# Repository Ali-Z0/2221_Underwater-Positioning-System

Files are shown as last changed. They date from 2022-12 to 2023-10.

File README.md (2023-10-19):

# 2221_UnderwaterLocalization
> Project for the localization of an underwater module.
> Demonstration [here](https://www.example.com). <!-- If you have the project hosted somewhere, include the link here. -->

## Table of Contents
* [General Information](#general-information)
* [Technologies Used](#technologies-used)
* [Features](#features)
* [Configuration](#configuration)
* [Usage](#usage)
* [Project Status](#project-status)
* [Improvements](#improvements)
* [Contact](#contact)
<!-- * [License](#license) -->

## General Information
This project revolves around an onboard electronic card designed to store measurement data about the movement of an underwater module through an inertial unit and a pressure sensor. This aims to mathematically locate it from its starting point (reference). This is crucial because underwater localization isn't an easy task, especially given the various underwater communication constraints, notably that electromagnetic waves do not propagate easily there.
<!-- You don't have to answer all the questions - just the ones relevant to your project. -->

## Technologies Used
- MPLAB Harmony v2_06
- Microcontroller - PIC32MX130F256D
- Inertial Unit - Bosch BNO055

## Features
- Saving a data set every 100ms.
- Maximum usage depth of 60m.
- 2 hours of logging onto an SD card.
- Sensing on 9 axes:
  - 3-axis accelerometer.
  - 3-axis gyroscope.
  - 3-axis magnetometer.
  - Temperature sensor
  - Depth gauge [0->10bar] [Res 1/10]
  - 3 to 5 free MikroE slots for additional measurements.
- Capability to save location of points of interest via:
  Saving button [To be defined: Magnetic, Optical, Mechanical or other].
- Battery with a minimum autonomy of 2 hours.
- Battery charging via USB connector.
- Data reading through USB connector (Electronic interfacing, software
  optional in this version).
- LED Interface.

<p align="center" width="100%">
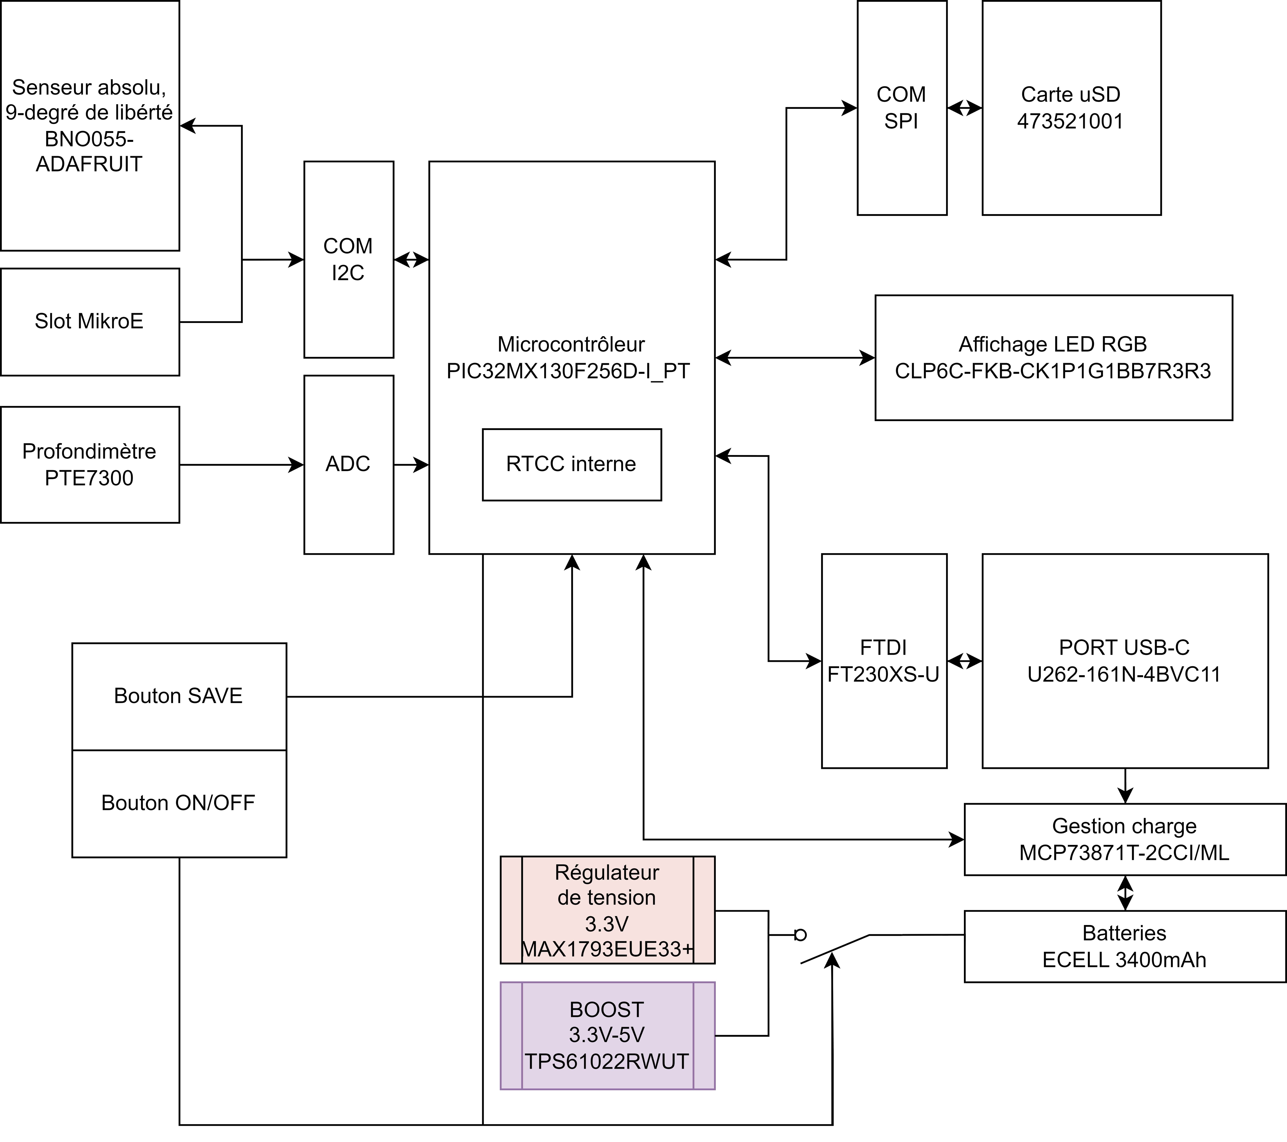
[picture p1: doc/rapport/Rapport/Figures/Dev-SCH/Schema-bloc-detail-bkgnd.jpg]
    
</p>

## Configuration
The electronic card must be assembled considering the manufacturing files and the BOM (Bill of Materials). The firmware then needs to be implemented into the PIC microcontroller, and an SD card should be inserted to read the movement data.

## Usage
The firmware code needs to be flashed using MPLAB-X with harmony onto the microcontroller of the produced PCB. To do this, there's a BERG programming connector. Once the code is flashed, the underwater module can be used, and provided an SD card is inserted, movement data will be saved in CSV format.

## Project Status
The project is completed, but improvements can always be made.

## Improvements
To do:
- [DONE] SCK VALID ONLY AT PIN 14 instead of 20
- [DONE] CHANGE U2TX PIN (PIN14) TO ANOTHER PIN
- [DONE] EXTERNAL OSCILLATOR MUST BE CONNECTED AS SECONDARY OSCILLATOR AND NOT PRIMARY
- Review multiplexer system (choice of CS polarity).

## Contact
Created by Ali Zoubir: ali.zoubir@etml-es.ch

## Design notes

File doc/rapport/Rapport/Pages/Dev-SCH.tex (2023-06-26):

% ------------------------- MAIN TASK ---------------------------------
\section{Développement schématique}

\subsection{Scéma bloc détaillé}
{
	\begin{figure}[h]
		\centering
		
		\caption{Schéma bloc détaillé}
		\label{fig:schema-bloc-detail}
		\source{Auteur}
	\end{figure}
}

\clearpage
\subsection{Choix des composants} \label{ssec:num32}
{
	\subsubsection{Microcontrôleur}
	Lors de la recherche de composants, j'ai décidé d'utiliser l'un des PIC32 standards de l'ES :
	\textbf{PIC32MX130F064D-I/PT}.
		
	\begin{figure}[h]
		\centering
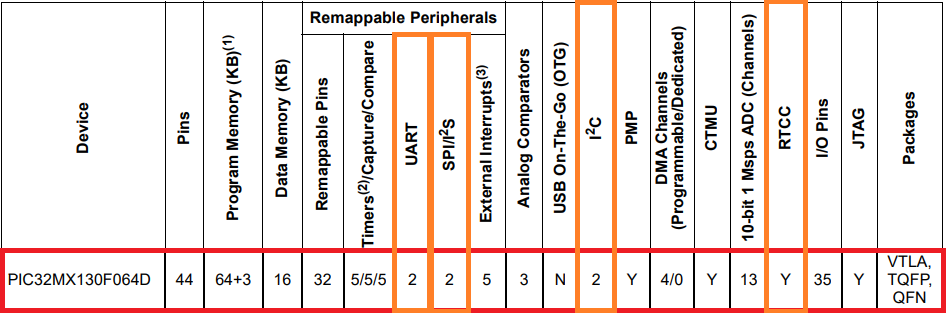
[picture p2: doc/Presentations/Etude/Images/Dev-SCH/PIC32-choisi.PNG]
		
		\caption{Périphériques disponibles du PIC}
		\label{fig:pic32-choisi}
		\source{\href{https://ww1.microchip.com/downloads/aemDocuments/documents/OTH/ProductDocuments/DataSheets/PIC32MM0256GPM064-Family-Data-Sheet-DS60001387D.pdf}{PIC32MM0256GPM064 family datasheet}}
	\end{figure}
	
	Nous pouvons constater sur la figure \ref{fig:pic32-choisi} que les critères minimaux de mon projet sont respectés :
	
	\begin{center}
		\fbox{\textit{1 - I2C}} \fbox{\textit{1 - SPI}} \fbox{\textit{1 - UART}} \fbox{\textit{1 - RTCC}}
	\end{center}
}

\clearpage
\subsection{Dimensionnements} \label{ssec:num31}
{
	\subsubsection{Vue d'ensemble schématique} \label{sssec:SchemaBloc} \vspace{-6mm}
	{
		\begin{figure}[th]
			\centering
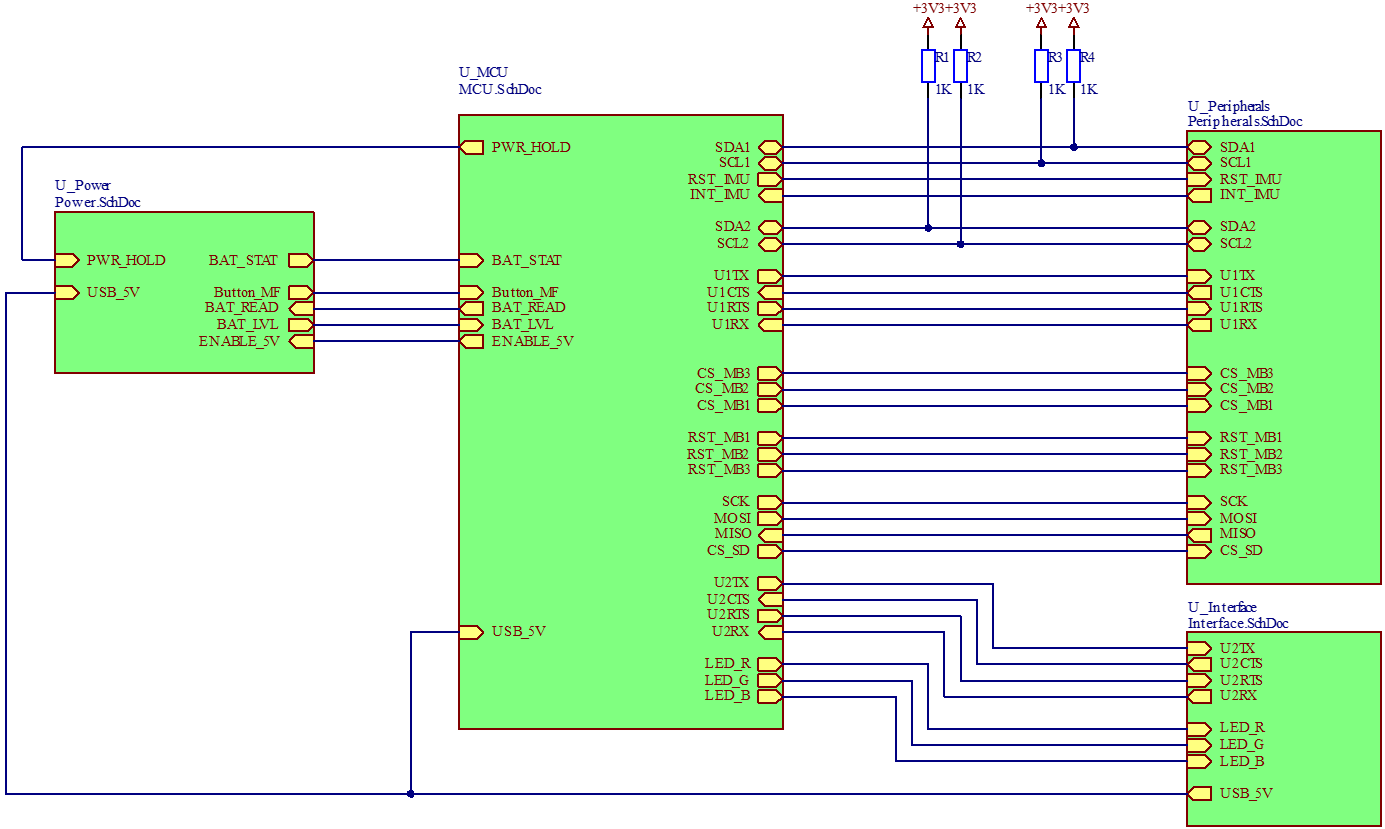
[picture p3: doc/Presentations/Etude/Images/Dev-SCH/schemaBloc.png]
			
			\caption{Schéma bloc de la schématique}
			\source{Auteur}
			\label{fig:schemablocSCH}
		\end{figure} \vspace{-5mm}
		Nous pouvons constater sur la figure \ref{fig:schemablocSCH} la structure des différents blocs du schéma : 
		
		\begin{tabularx}{16cm}{|X|X|}
			\hline
			Bloc & Description \\
			\hline
			\hline
			Power & Contient les différents régulateurs du système, ainsi que la gestion de charge de la batterie. \\
			\hline
			MCU & Contient l'intelligence du système, avec le microcontrôleur ainsi que tous ses composants passifs associés. \\
			\hline
			Peripherals & Périphériques du système : Carte-SD, Centrale inertielle, Capteur de pression, Slots MikroE. \\ 
			\hline
			Interface & Connecteur USB avec convertisseur serial (FTDI) et tous les composants passifs de sécurité. Interface LED RGB pour le statut. \\
			\hline
		\end{tabularx}
	}

	\clearpage
	\subsubsection{Autonomie du système} \label{sssec:SysAutonomie}
	{
		Afin de proportionner la batterie du circuit, il a fallut dimensionner les différentes consommations des composants, ceci par le biais de leurs documentations :
		
		\begin{center}
			\fbox{\textit{MCU - 30mA}} \fbox{\textit{BNO055 - 12.3mA}} \fbox{\textit{Capt. Pression - 4mA}} \fbox{\textit{\textcolor{red}{Carte-SD - 100mA}}} \fbox{\textit{MikroE - ??mA}} \fbox{\textit{Régulateurs - 40uA}} \fbox{\textit{LED RGB - 25mA}} 
		\end{center}
		
		Nous pouvons constater que la plus grande consommation vient de la carte micro-SD, qui au maximum peut induire 100mA. \footnote{\href{https://images-na.ssl-images-amazon.com/images/I/91tTtUMDM3L.pdf}{Datasheet SanDisk} }

		Afin d'obtenir une autonomie d'au moins 2h (selon CDC), il faudrait une capacité de :
		
		\begin{equation}
			Capacite = Consommation_{tot} * Temps
		\end{equation}
		
		Ce qui nous fait une capacité de $\sim$342.68mAh, valeur facilement atteignable par les batteries li-ion du marché. Étant-donné que différents projets utilisaient des batteries 3400mAh, dans un objectif de conformité et de simplification des commandes, j'ai choisis cette même valeur.
		Ce qui signifie une autonomie de $\sim$20 heures, sans compter les différents mécanismes d'économie d'énergie.
		
		C'est un temps largement suffisant pour la durée de plusieurs expéditions, néanmoins la RTCC du microcontrôleur pourrait requérir d'être alimentée en permanence, on pourrait donc imaginer un fonctionnement où lorsque l'on charge la batterie la date se mettrait à jour et le mode "éteint" serait juste un mode de veille qui attendrait un niveau positif sur le switch avant de commencer le logging avec un timsetamp principale contenant la date, puis, seulement des deltas entre les mesures. Un diagramme des états est présents à la figure \ref{fig:etatsdiagramme}.
		
		\clearpage
		\begin{figure}[th]
			\centering
			
			\caption{Diagramme des états du système}
			\label{fig:etatsdiagramme}
			\source{Auteur}
		\end{figure}
		
	}

	\clearpage
	\subsubsection{LED Interface} \label{sssec:DimLedRGB}
	{
		Afin d'informer l'utilisateur de ce qu'il se passe dans le système, j'ai décidé d'implémenter en tant qu'interface, une led RGB. Celle-ci sera un minimum puissante, afin de pouvoir être lisible lors de l'utilisation sous-marine du module.
		
		La consommation de la led RGB étant relativement importante, des mécanismes d'économie d'énergie seront mis en place dans le développement firmware. \vspace{+3mm}
		
		\textbf{Diagramme d'interface :}
		
		\begin{figure}[h]
			\centering
			
			\caption{Définitions des états de la LED RGB}
			\source{Auteur}
			\label{fig:ledstates}
		\end{figure}
	}

	\clearpage
	\subsubsection{Adaptation mécanique} \label{sssec:MecAdapt}
	{	
		L'idée étant d'obtenir une mesure de pression sans modification mécaniques sur le boîtier originale, plusieurs idées ont émergées :
		\begin{itemize}
			\item[1)] Mesurer une déformation mécanique a-même le module, dans le but de déduire la pression (Développement d'un capteur).
			\item[2)] Ajout d'une rallonge cylindrique au module, afin de fixer un capteur de pression à plat sur celui-ci, tout en permettant les modifications mécaniques sans altération du boîtier originale.
		\end{itemize}
		Par sa complexité moins importante et due aux contraintes de temps, la seconde option sera-celle développée lors de cette version du projet.
		Voici des ébauches (Pas à l'échelle) du concept : 
		\begin{figure}[h]
			\centering
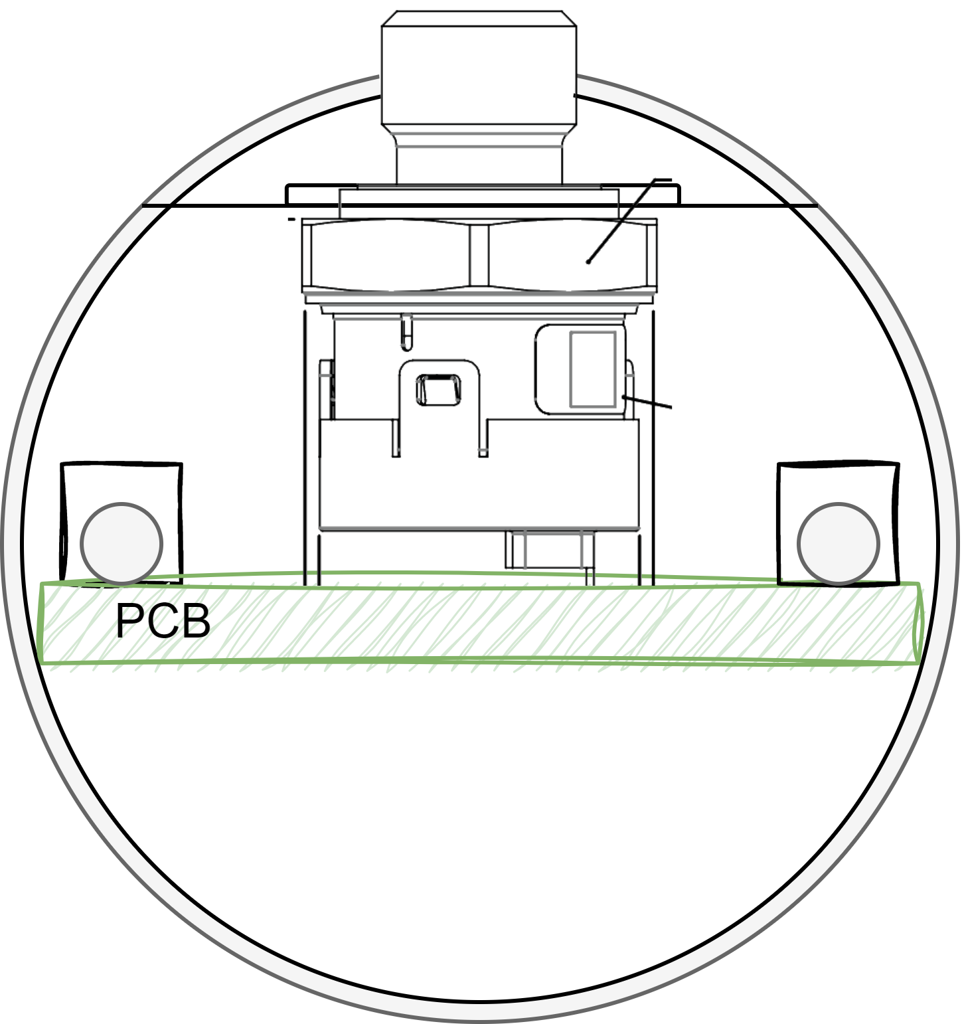
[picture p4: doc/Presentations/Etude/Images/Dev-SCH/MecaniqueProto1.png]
			
			\caption{Ébauche intérieur du cylindre}
			\label{fig:mecaniqueproto1}
			\source{Auteur}
		\end{figure}\vspace{-5mm}
		\begin{figure}[!h]
			\centering
			
			\caption{Ébauche globale}
			\label{fig:mecaniqueproto2}
			\source{Auteur}
		\end{figure}

	}

	\clearpage
	\subsubsection{Bus de communications}
	{
		\textbf{UART (1) :} \\
		\underline{Utilisation :} Communication avec les boards Mikroe, pour les clicks-boards utilisant la comm. série. \\
		\underline{Pinning :} \vspace{-6mm}
		\begin{figure}[h]
			\centering
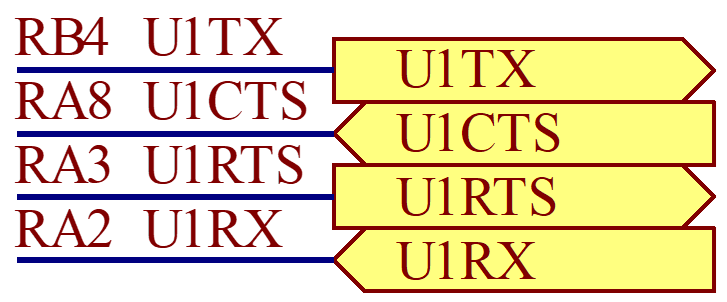
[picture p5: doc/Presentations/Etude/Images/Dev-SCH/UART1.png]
			
			\label{fig:uart1}
		\end{figure}		
	
		\textbf{UART (2) :} \\
		\underline{Utilisation :} Communication avec FTDI conversion USB-Serial. Transfert des fichiers de la carte-SD et mise-à-jour de la RTCC. \\
		\underline{Pinning :} \vspace{-6mm}
		\begin{figure}[h]
			\centering
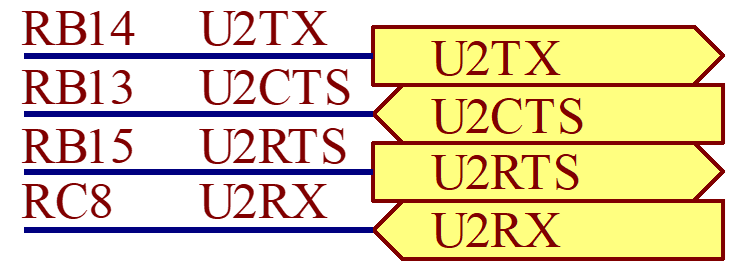
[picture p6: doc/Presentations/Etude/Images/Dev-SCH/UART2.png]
			
			\label{fig:uart2}
		\end{figure}		
	
		\textbf{SPI :} \\
		\underline{Utilisation :} Communication avec la carte micro-SD, écriture des mesures, timestamps et flag d'importance. \\
		\underline{Pinning :} \vspace{-6mm}
		\begin{figure}[h]
			\centering
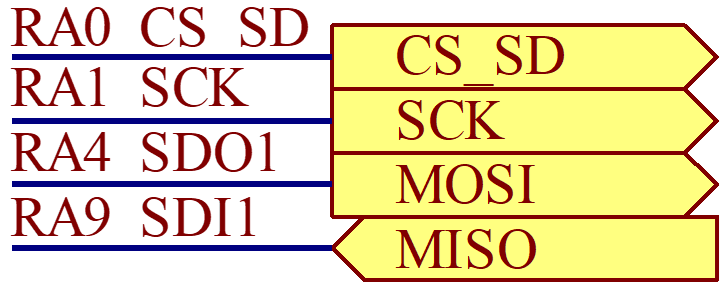
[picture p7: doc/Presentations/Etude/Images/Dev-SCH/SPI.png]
			
			\label{fig:spi}
		\end{figure}
	
		\textbf{I2C (1) :} \\
		\underline{Utilisation :} Lecture des mesure de la centrale inertielle BNO055 et paramétrage des registres de celui-ci. \\
		\underline{Pinning :} \vspace{-6mm}
		\begin{figure}[h!]
			\centering
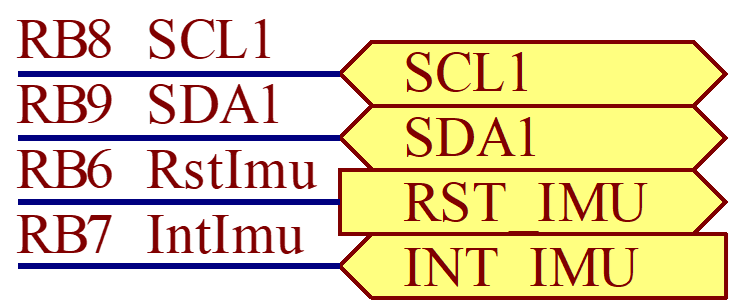
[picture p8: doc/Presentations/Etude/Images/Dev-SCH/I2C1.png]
			
			\label{fig:i2c1}
		\end{figure}
	
		\textbf{I2C (2) :} \\
		\underline{Utilisation :} Lecture des données du capteur de pression et est également connecté aux slots Mikroe, pour permettre à ceux-ci de communiquer via I2C. \\
		\underline{Pinning :} \vspace{-6mm}
		\begin{figure}[h!]
			\centering
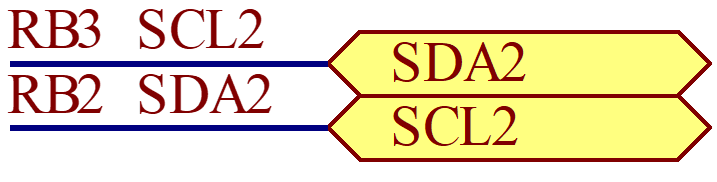
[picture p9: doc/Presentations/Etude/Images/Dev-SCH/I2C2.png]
			
			\label{fig:i2c2}
		\end{figure}
	
		\clearpage
		Pour ce qui est des mesures sur ces différents bus de communications, des connecteurs bergs ont étés prévus, afin de pouvoir connecter facilement un analyseur logique sur les différentes trames : 
		
		\begin{figure}[h]
			\centering
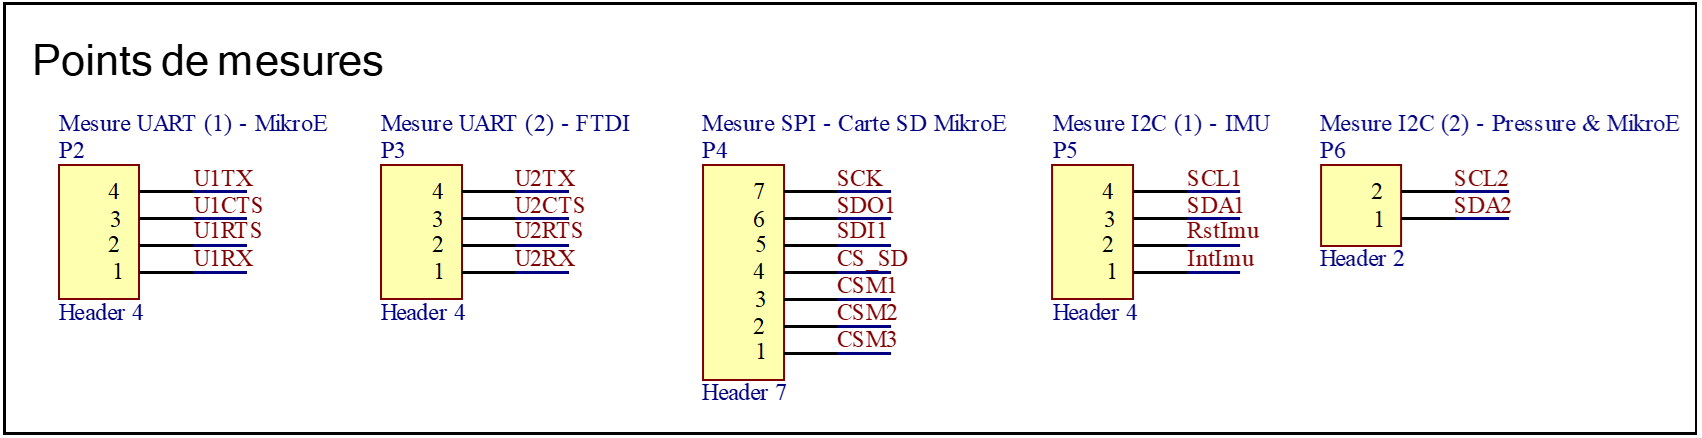
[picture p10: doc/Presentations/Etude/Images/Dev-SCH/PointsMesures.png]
			
			\caption{Connecteurs pour analyseur logique}
			\label{fig:pointsmesures}
		\end{figure}
		
		Une contrainte s'est crée, lorsque toutes les pins du microcontrôleur ont été allouée alors qu'il restait des connexion pour les "Chip select" et "Reset" des carte click-board Mikroe. Afin de remédier à ce problème, j'ai décidé d'utiliser un démultiplexeur, sachant que chacune des ces PINS, peuvent être activée seulement une à une : 
		
		\begin{figure}[h]
			\centering
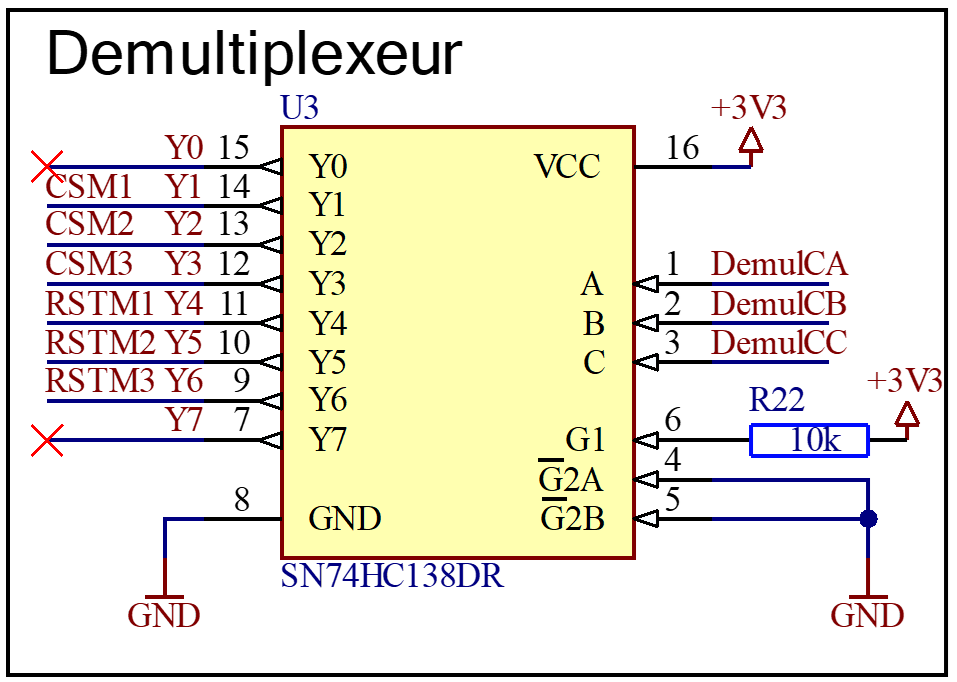
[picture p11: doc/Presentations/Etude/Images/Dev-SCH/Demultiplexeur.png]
			
			\caption{Demultiplexeur}
			\label{fig:demultiplexeur}
		\end{figure}
	}
	
	\clearpage
	\subsubsection{Périphériques}
	{
		\begin{figure}[h]
			\centering
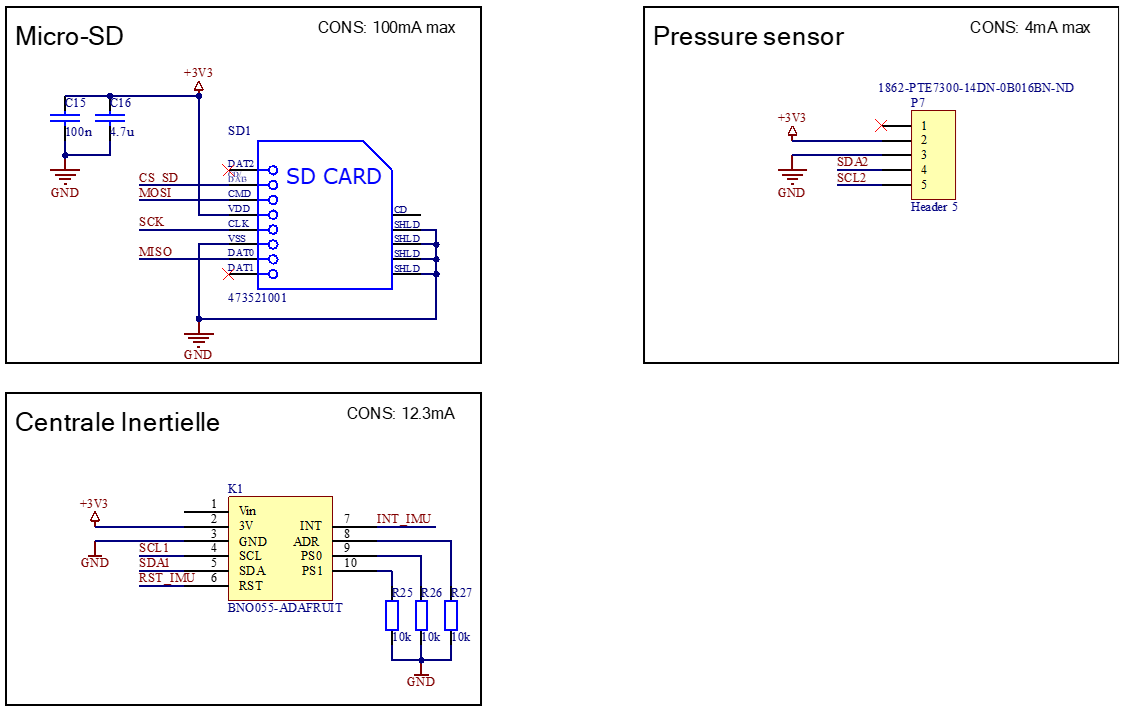
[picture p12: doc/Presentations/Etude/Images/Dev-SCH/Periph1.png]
			
			\caption{Carte-SD, capteur de pression et centrale inertielle.}
			\label{fig:periph1}
		\end{figure}
		
		Pour la carte-SD, certaines pins ne sont pas utilisée car pas utile dans le cadre du projet (Ex: Pin CD (Card Detect)).
		Pour le capteur de pression, il s'agit d'un simple connecteur (AMTEK 5H2001N0-105PXBL00A01) qui vas venir connecter le senseur rattaché à l'extension mécanique.
		Quant à la centrale inertielle (BNO055 adafruit-board) le bit d'adresse supplémentaire est mis à 0.
		
		\begin{figure}[h]
			\centering
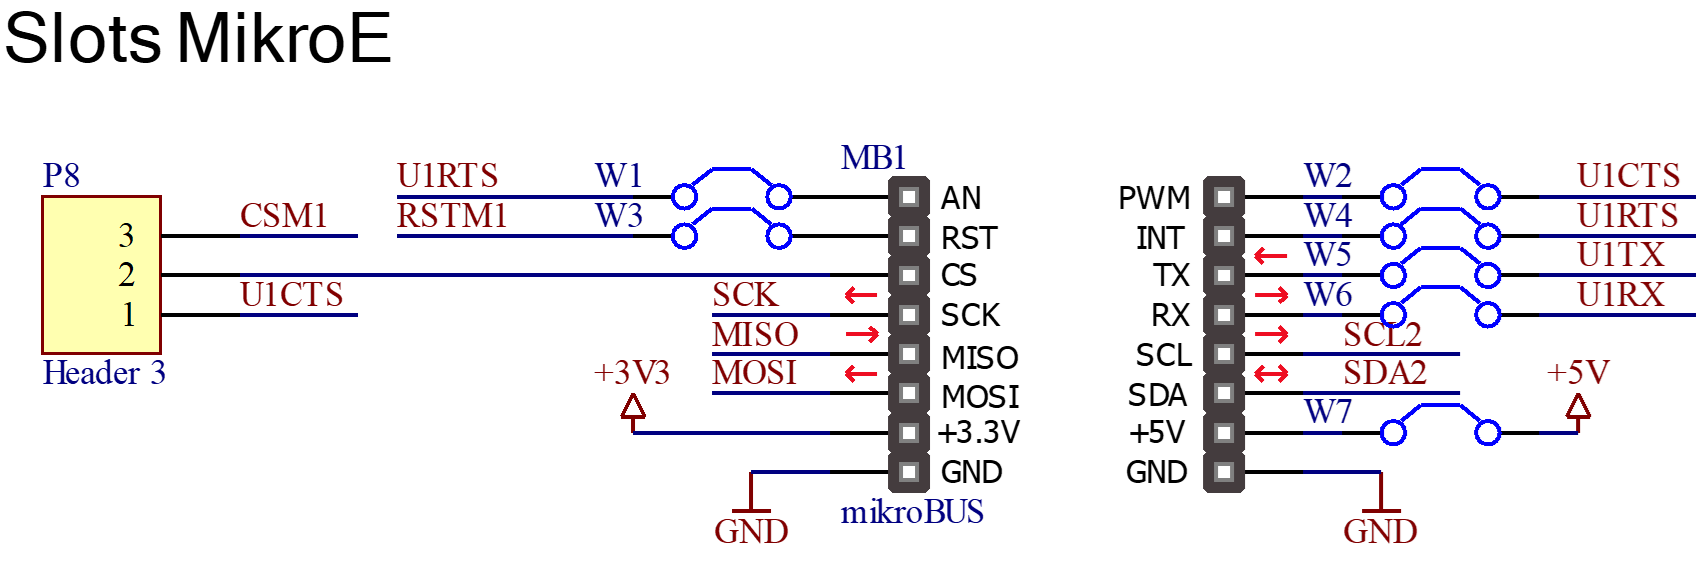
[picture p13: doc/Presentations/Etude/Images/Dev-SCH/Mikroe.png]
			
			\caption{}
			\label{fig:mikroe}
		\end{figure}
		Les slots Mikroe (3x figure \ref{fig:mikroe}) sont prévus pour pouvoir utiliser le plus de bus de communication possibles. Les jumpers sont prévus pour éviter les collisions sur les lignes.
		
	}

	\clearpage
	\subsubsection{Chargeur de batterie} \label{sssec:BatCharger}
	{
		Ici je vais me pencher sur les dimensionnement des 3 résistances \textit{PROG} du composant de régulation et de charge d'accu, les autres composants passifs n'ont pas requis de dimensionnements particuliers.
		\begin{figure}[h]
			\centering
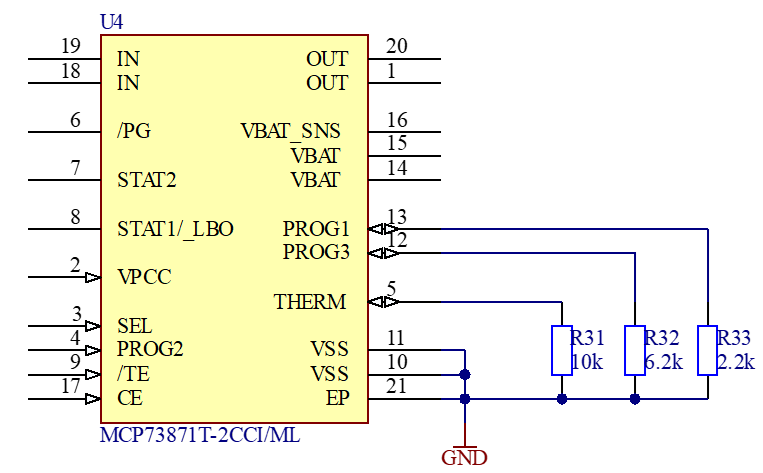
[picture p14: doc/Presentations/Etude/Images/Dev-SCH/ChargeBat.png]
			
			\caption{IC régulation et gestion charge de l'accu}
			\label{fig:chargebat}
		\end{figure}
		
		Afin de déterminer le comportement de la charge via les différentes étapes de courants, quelques équations ont été utiles : \\
		Où \\
		$C = 3400mAh$ \\
		$ratio_{term} = 0.05$
		$ratio_{chrg} = 0.1$
		
		\begin{equation} \label{equ:ich}
			I_{term} = C * ratio_{chrg} 
		\end{equation}
		D'après \ref{equ:ich}, $I_{term} = 170mA$.
	 
	 	\begin{equation} \label{equ:Rprog3}
		 	Rprog3 = \frac{1000V}{I_{term}}
		\end{equation}
		D'après \ref{equ:Rprog1}, $Rprog3 = 5k88 \Omega$ E12 $\Longrightarrow$ $6k2\Omega$ (Arrondis au supérieur pour limiter courant de terminaison).
		
		\begin{equation} \label{equ:Rprog1}
			Rprog1 = \frac{1000V}{C * ratio_{chrg}} 
		\end{equation}
		D'après \ref{equ:Rprog1}, $Rprog1 = 2k94 \Omega$ E12 $\Longrightarrow$ $2k2\Omega$ (Arrondis à l'inférieur pour limiter courant de charge).
		 
	}
	
	\clearpage
	\subsubsection{Synthèse et perspectives de l'étude} \label{sssec:conclusionEtude}
	{
		Lors du développement de la schématique, je n'ai pas eu de grands dimensionnements à faire mais plutôt dû mettre en place des mécanismes permettant la communication avec tous les senseurs et périphériques du système. J'ai essayé d'être le plus explicite possible lors de la création des différents blocs du schéma électrique, pour permettre une compréhension aisée de celui-ci. 
		J'ai pû faire un contrôle mutuel de la schématique avec mon collègue M. Meven Ricchieri.
		Je n'ai pas rencontré de problèmes particuliers, j'ai pus compléter la schématique, avancer sur le concept globale et je suis très enthousiaste de continuer ce projet.
		Désormais il vas falloir préparer la création du PCB, en contrôlant les footprints du circuit et développer d'avantage l'aspect mécanique du projet.
		La schématique issue de cette partie développement,  sera disponible en annexe de ce rapport.	
		
	}
}

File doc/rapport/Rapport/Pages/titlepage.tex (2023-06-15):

\begin{titlepage}
   \begin{center}
        \vspace*{1cm}
        \LARGE
        {\Huge \textbf{Localisation sous-marine}}
        
        \vspace{0.3cm}
        Système de logging pour déplacement de module sous-marin.
            
        \vspace{1.5cm}

        \textbf{Ali Zoubir} \vspace{5mm}
        
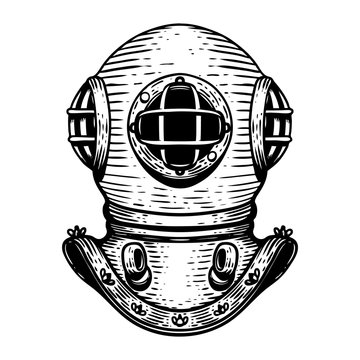
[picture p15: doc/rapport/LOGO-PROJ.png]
        

        \vfill
            
        Rapport de projet
            
        \vspace{0.8cm}
     
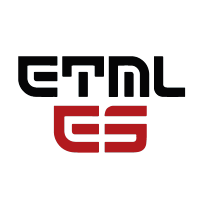
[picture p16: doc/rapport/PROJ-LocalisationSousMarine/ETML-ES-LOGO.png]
        

        Génie électrique\\
        École supérieure\\
        Suisse\\
        \monthyeardate\today
            
   \end{center}
\end{titlepage}

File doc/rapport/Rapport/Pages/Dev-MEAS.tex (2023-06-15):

% !TeX spellcheck = fr_FR
\section{Validation du design}
Lors de cette section, sera décrite la procédure de vérification des caractéristiques du projet ainsi que sa validation.
\subsection{Liste de matériel} \label{ssec:ListeMateriel}
{
	\begin{enumerate}
		\item Oscilloscope Tektronix RTB2004 ES.SLO2.05.01.16 \label{enum:oscillo}
		\item Analyseur logique USB, 8 canaux, 24 MHz \label{enum:logicAnalyzer}
		\item USB vers TTL HW-597 \label{enum:USB-TTL}
		\item Carte Localisation-Sous-Marine V0.0 \label{enum:PCBL}
	\end{enumerate}
}

\subsection{Contrôle des alimentations}
{
	En premier lieu, une vérification des tensions d'alimentation permet de valider un aspect critique et fondamental de la carte.
	\subsubsection{Méthodologie}
	\paragraph{Mesure du 3.3V :} Alimentation de la carte par une connexion brève entre les pins du connecteur du bouton \textbf{P15}. Mesure sur le testpoint \textit{V\_regOUT5}, voir figure \ref{fig:sch3}.
	\begin{figure}[h]
		\centering
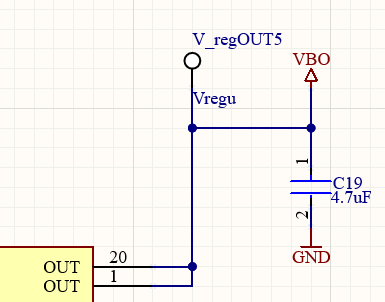
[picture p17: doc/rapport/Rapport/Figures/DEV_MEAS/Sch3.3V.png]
		\fbox{}
		\caption{Testpoint mesure 3.3V}
		\label{fig:sch3}
	\end{figure}
	
	\paragraph{Mesure du 5V :} Pour mesurer le 5V, il faut ponter par une résistance de $0\Omega$ la résistance R50, ainsi que activer la Pin RC5 / EN\_5V. Ensuite, la mesure a été prise sur le connecteur P16, pin-3, avec l'oscilloscope (Numéro \ref{enum:oscillo} de la liste de matériel \ref{ssec:ListeMateriel}) :
	\begin{figure}[h]
		\centering
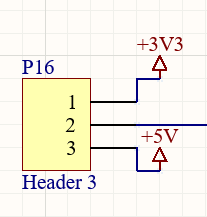
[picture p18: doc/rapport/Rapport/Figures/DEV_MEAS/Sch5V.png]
		\fbox{}
		\caption{Schéma de mesure 5V}
		\label{fig:sch5v}
	\end{figure}
	
	\clearpage
	
	\subsubsection{Mesures}
	
	\begin{figure}
		\begin{subfigure}{.5\textwidth}
			\centering
			
			\caption{Mesure 3.3V}
			\label{fig:Mes3.3V}
		\end{subfigure}
		\begin{subfigure}{.5\textwidth}
			\centering
			
			\caption{Mesure 5V}
			\label{fig:Mes5V}
		\end{subfigure}
		\caption{Mesures des tensions d'alimentation}
		\label{fig:Mesure3.3et5V}
	\end{figure}
	
	\paragraph{Analyse :} Nous pouvons observer les valeurs respectives des tensions sur les figures \ref{fig:Mes3.3V} et \ref{fig:Mes5V}. La tension d'alimentation du microcontrôleur est mesurée à \textit{3.125V}, ce qui peut être expliqué par une chute de tension aux bornes de la batterie LI-ION qui nécessite donc d'être chargée. La tension 3.3V oscille légèrement, ce qui peut s'expliquer par le fait qu'il s'agit de l'alimentation principale de la carte avec le plus de consommateurs. Mais également par le fait que des signaux rapides sont générés par le microcontrôleur et ses différents périphériques.
	
	La tension d'alimentation du capteur de pression, dont la tension dimensionnée est de 5V, est quant à elle mesurée à \textit{5.0295V}, ce qui signifie une bonne précision de la part du circuit de boost. On peut également voir que la tension n'oscille pas et ne va donc pas perturber le capteur de pression.
	
	Nous pouvons donc confirmer le fonctionnement des blocs d'alimentation du projet.
}

\subsection{Communication UART}
{
	Comme décrit lors de la sous-section \ref{ssec:Usart}, une communication série est implémentée dans le projet. Cette communication n'est pas critique pour le projet, mais il est important de vérifier son fonctionnement pour d'éventuelles versions ultérieures.
	\subsubsection{Méthodologie}
	Pour la mesure, l'analyseur logique (Numéro \ref{enum:logicAnalyzer} de la liste de matériel \ref{ssec:ListeMateriel}) a été utilisé. Les trames U1TX et U1RX ont été mesurées sur le connecteur P4 :
	
	\begin{figure}[h]
		\centering
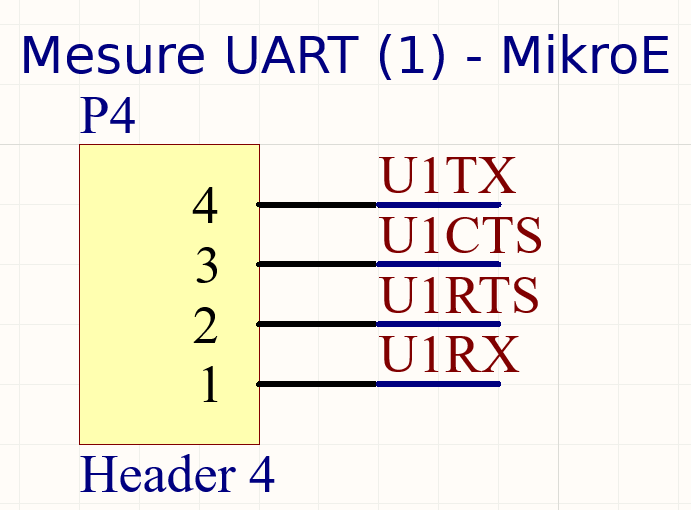
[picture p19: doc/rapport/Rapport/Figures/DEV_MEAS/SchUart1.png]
		\fbox{}
		\caption{Schéma de mesure UART1}
		\label{fig:schuart1}
	\end{figure}
	\clearpage	
	\subsubsection{Mesures}
	
	\begin{figure}[h]
		\centering
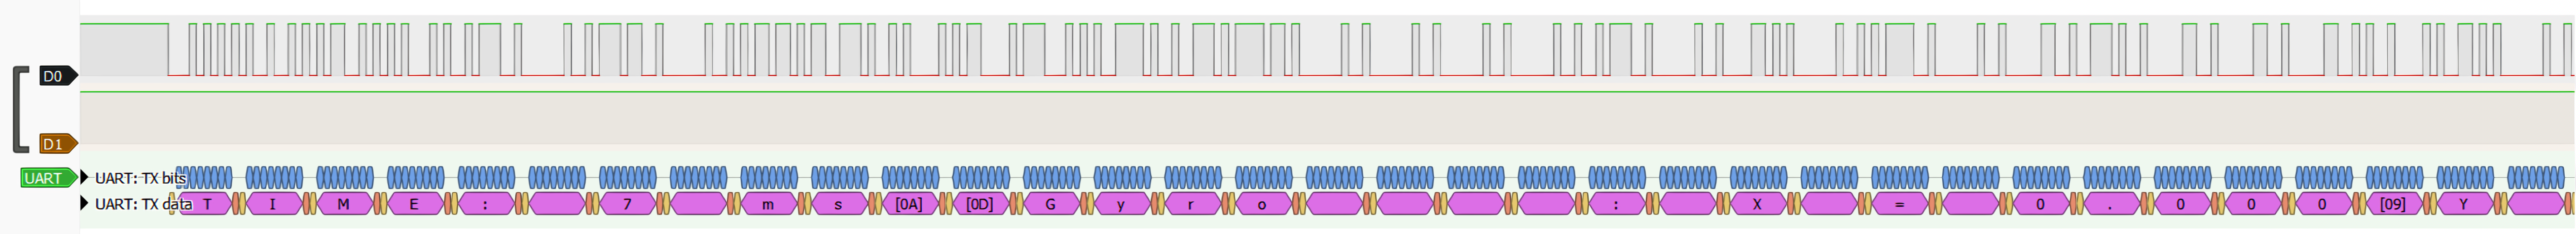
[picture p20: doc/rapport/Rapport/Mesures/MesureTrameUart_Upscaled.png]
		\fbox{}
		\caption{Mesures trames UART}
		\label{fig:mesuretrameuart}
	\end{figure}
	Nous pouvons lire des caractères ASCII sur la trame de la figure \ref{fig:mesuretrameuart}, qui reflètent le message envoyé contenant les mesures. 
	
	En connectant le module USB-TO-TTL (Numéro \ref{enum:USB-TTL} de la liste de matériel \ref{ssec:ListeMateriel}) aux broches Tx et Rx de la figure \ref{fig:mesuretrameuart}, puis en ouvrant une communication série via PuTTY à une baudrate de $115200$, nous obtenons la communication de la figure \ref{fig:puttytrames} dans la console :
	
	\begin{figure}[h]
		\centering
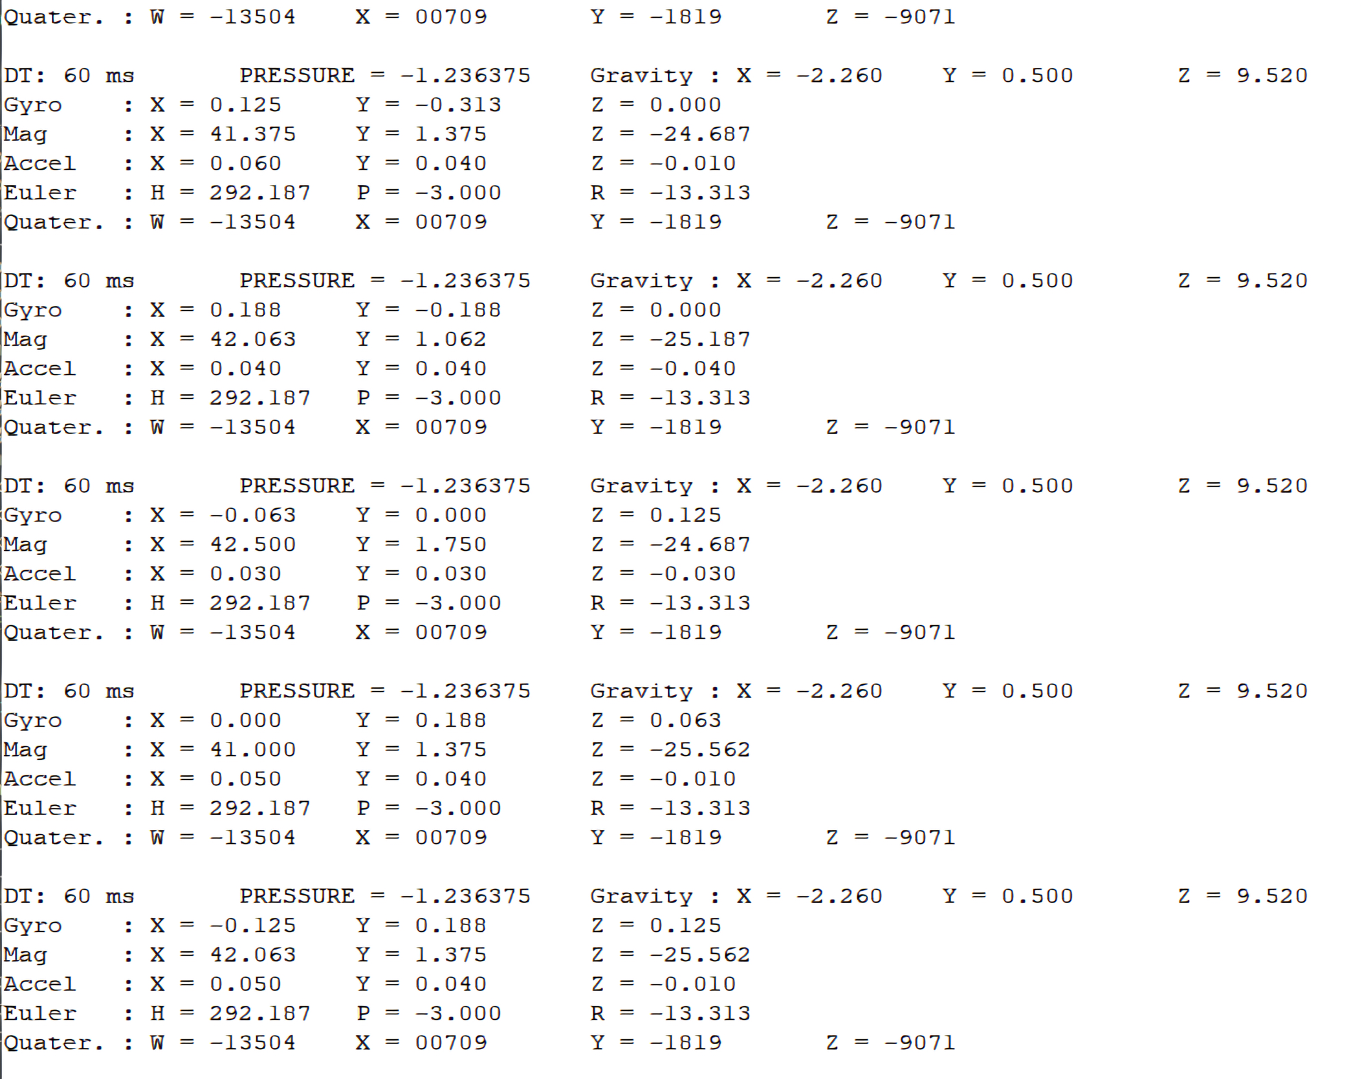
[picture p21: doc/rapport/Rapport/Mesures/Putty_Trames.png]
		\fbox{}
		\caption{Réception UART sur PuTTY}
		\label{fig:puttytrames}
	\end{figure}
	Analyse de la réception : Sur la figure \ref{fig:puttytrames}, on peut visualiser les données de la centrale inertielle, le temps écoulé entre chaque mesure, ainsi que les données du capteur de pression. Nous pouvons observer qu'entre chaque mesure, il s'écoule un laps de temps de $60 ms$, ce qui est plus rapide que les spécifications demandées par le cahier des charges. La mesure du capteur de pression à $-1.236$ bar n'est pas cohérente, car le capteur de pression n'était pas connecté au moment des mesures. Nous pouvons également constater que les mesures de la centrale inertielle sont cohérentes selon les données typiques d'une centrale inertielle\footnote{Exemple de données de fusion d'une centrale inertielle \cite{rozbicka2021estimation}}.
	
	\clearpage
}

\subsection{Communication SPI, carte SD}
{
	Il reste maintenant un élément critique à valider : la communication SPI avec la carte SD. Cette communication permet le logging des valeurs de mesure et est donc un aspect essentiel du projet.
	\subsubsection{Méthodologie}
	Pour cette mesure j'ai mesuré les signaux (SCK, SDO1, SDI1, CS\_SD) du SPI avec l'analyseur logique (Numéro \ref{enum:logicAnalyzer} de la liste de matériel \ref{ssec:ListeMateriel}).
	
	\begin{figure}[h]
		\centering
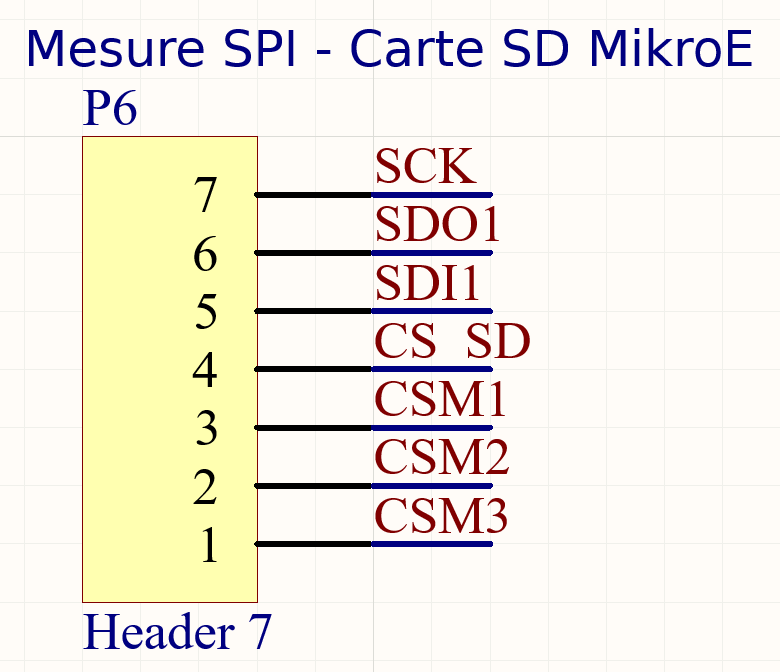
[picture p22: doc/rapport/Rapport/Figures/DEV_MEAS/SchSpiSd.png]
		\fbox{}
		\caption{Schéma de mesure carte SD}
		\label{fig:schspisd}
	\end{figure}
		
	\subsubsection{Mesures}
	\begin{figure}[h]
		\centering
		
		\caption{Vue d'ensemble de la communication SPI}
		\label{fig:spisdcommensembleupscaled}
	\end{figure}
	Comme le montre la figure \ref{fig:spisdcommensembleupscaled}, on peut constater que les trames SPI utilisées pour la gestion de la FAT sont nombreuses. C'est pourquoi il est important d'avoir une fréquence élevée afin d'optimiser le temps des échanges de données.
	
	Nous allons maintenant mesurer le temps entre deux écritures sur la carte SD afin de vérifier le temps écoulé entre les mesures. et l'écriture.
	
	\clearpage
	
	\begin{figure}[h]
		\centering
		
		\caption{Temps entre deux écritures sur la carte SD}
		\label{fig:spisdtempreentre2commsupscaled}
	\end{figure}
	
	Nous pouvons observer sur la figure \ref{fig:spisdtempreentre2commsupscaled} que le temps mesuré entre une première écriture et le début de la suivante est de $89.804 ms$. Le temps disponible entre deux écritures est d'environ $\sim6ms$.
	Nous pouvons donc constater l'importance d'une vitesse élevée sur la communication SPI et sur le microcontrôleur.
	
	Avec une fréquence d'horloge de $48MHz$, on peut donc déduire :
	
	\begin{equation} 
		\label{equ:Noperations}
		N_{op} = T_{dispo} * F_{sys} = 6*10^{-3} * 48*10^{6} = 288'000 
	\end{equation}
	
	D'après le calcul \ref{equ:Noperations} nous savons que le MCU peut effectuer $288'000$ cycles machines durant ce temps disponible. Nous considérons ce nombre d'opérations suffisants au système, sachant qu'il n'y a pas beaucoup d'autre opérations. \textbf{Cet élément est à prendre en compte en cas d'ajout de fonctionnalité dans le système}.
	
	\paragraph{Mesure début de trame :} Sur la figure \ref{fig:spisdtramedepartupscaled} nous pouvons observer à quoi ressemble un début de trame sur la carte SD pour système FAT.
	
	\begin{figure}[h]
		\centering
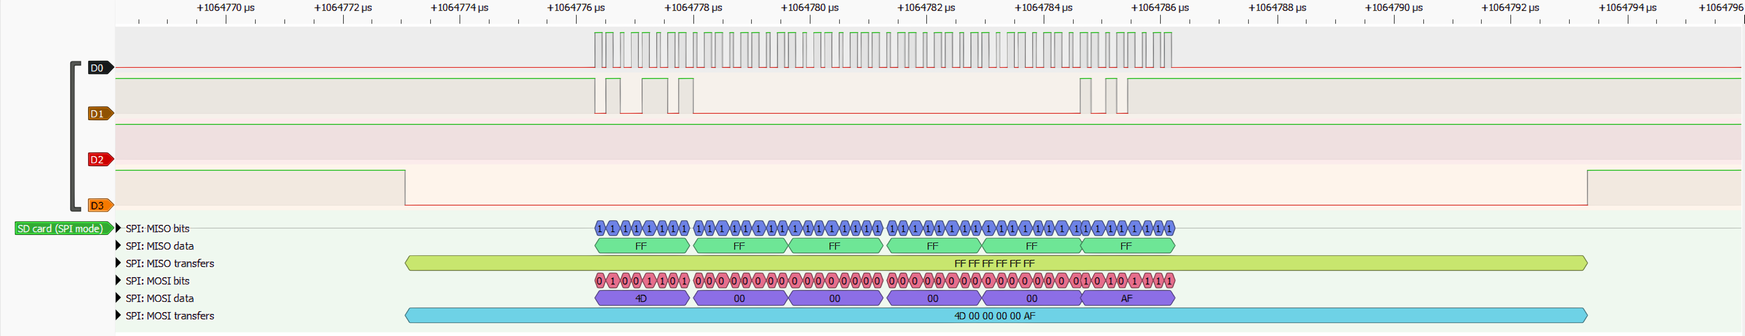
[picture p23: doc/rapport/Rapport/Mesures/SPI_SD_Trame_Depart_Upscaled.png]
		
		\caption{Mesure début de trame}
		\label{fig:spisdtramedepartupscaled}
	\end{figure}

}

\clearpage

\section{Caractéristiques du produit fini}

\input{Tables/tb_caracteristiques.tex}

On peut voir sur le tableau \ref{tab:Caracteristiques} les caractéristiques issues du développement final du projet dans sa version 0.0. Un test de logging de 5 heures a été effectué sans difficulté et a récolté 30 MB de données dans le fichier CSV, ce qui correspond effectivement aux caractéristiques du tableau \ref{tab:Caracteristiques}.

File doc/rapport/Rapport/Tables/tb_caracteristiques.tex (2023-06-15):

% Please add the following required packages to your document preamble:
% \usepackage{graphicx}
\begin{table}[h]
	\centering
	\resizebox{\columnwidth}{!}{%
		\begin{tabular}{|l|rlrl|}
			\hline
			Caractéristique          & \multicolumn{2}{c|}{Attribut}                       & \multicolumn{2}{c|}{Valeur alternative} \\ \hline
			Axes de mesures          & $9$                 & \multicolumn{1}{l|}{}         & -                   &                   \\ \hline
			Mesures                  & \multicolumn{4}{c|}{$[ms][bar][\degree/s][uT][Euler][Quaternion][\degree C]$}                              \\ \hline
			Temps entre mesures      & $90$                & \multicolumn{1}{l|}{$[ms]$}   & $11.11$             & $Hz$              \\ \hline
			Nombre de mesures max    & $1.641$             & \multicolumn{1}{l|}{$M$}      & -                   &                   \\ \hline
			Capacité carte SD        & $256$               & \multicolumn{1}{l|}{$[MB]$}   & -                   &                   \\ \hline
			Pression maximum         & $10$                & \multicolumn{1}{l|}{$[bars]$} & $145$               & $PSI$             \\ \hline
			Autonomie                & $\sim20$            & \multicolumn{1}{l|}{$[h]$}    & $72'000$            & $[s]$             \\ \hline
			Batterie                 & $3400$              & \multicolumn{1}{l|}{$[mAh]$}  & $11.22$             & $[Wh]$            \\ \hline
			Profondeur               & $101.97$            & \multicolumn{1}{l|}{$[mH2O]$} & -                   &                   \\ \hline
			Précision pression       & $0.15$              & \multicolumn{1}{l|}{$[\%]$}    & -                   &                   \\ \hline
			Slot Mikroe              & $1$                 & \multicolumn{1}{l|}{$[-]$}    & -                   &                   \\ \hline
			Vitesse MCU              & $48$                & \multicolumn{1}{l|}{$[MHz]$}  & -                   &                   \\ \hline
			Interface                & LED RGB             & \multicolumn{1}{l|}{}         & -                   &                   \\ \hline
			Communications           & I2C, SPI, UART, USB & \multicolumn{1}{l|}{}         & -                   &                   \\ \hline
			Vitesse SPI              & $5$                 & \multicolumn{1}{l|}{$[MHz]$}  & -                   &                   \\ \hline
			Vitesse UART             & $115200$            & \multicolumn{1}{l|}{$[Bd]$}   & -                   &                   \\ \hline
			Mise en évidence mesure  & Oui                 & \multicolumn{1}{l|}{}         & -                   &                   \\ \hline
			Compensation température & Oui                 & \multicolumn{1}{l|}{}         & -                   &                   \\ \hline
		\end{tabular}%
	}
	\caption{Caractéristiques du projet V0.0}
	\label{tab:Caracteristiques}
\end{table}

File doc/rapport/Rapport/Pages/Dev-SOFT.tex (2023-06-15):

% !TeX spellcheck = fr_FR
\section{Développement firmware}
Dans cette section, nous allons décrire et expliquer le processus de programmation du code qui a été implémenté dans le microcontrôleur PIC32MX130F256D.
Le processus de programmation du code dans le PIC32MX130F256D comprend plusieurs étapes. Tout d'abord, il est nécessaire de disposer d'un environnement de développement intégré (IDE) adapté à ce microcontrôleur, tel que MPLAB X IDE. Cet IDE est équipé de l'environnement Harmony, qui permet l'utilisation d'un configurateur graphique pour les différentes bibliothèques du PIC.

\subsection{Configuration des PINs dans Harmony}
{
	\begin{figure}[h]
		\centering
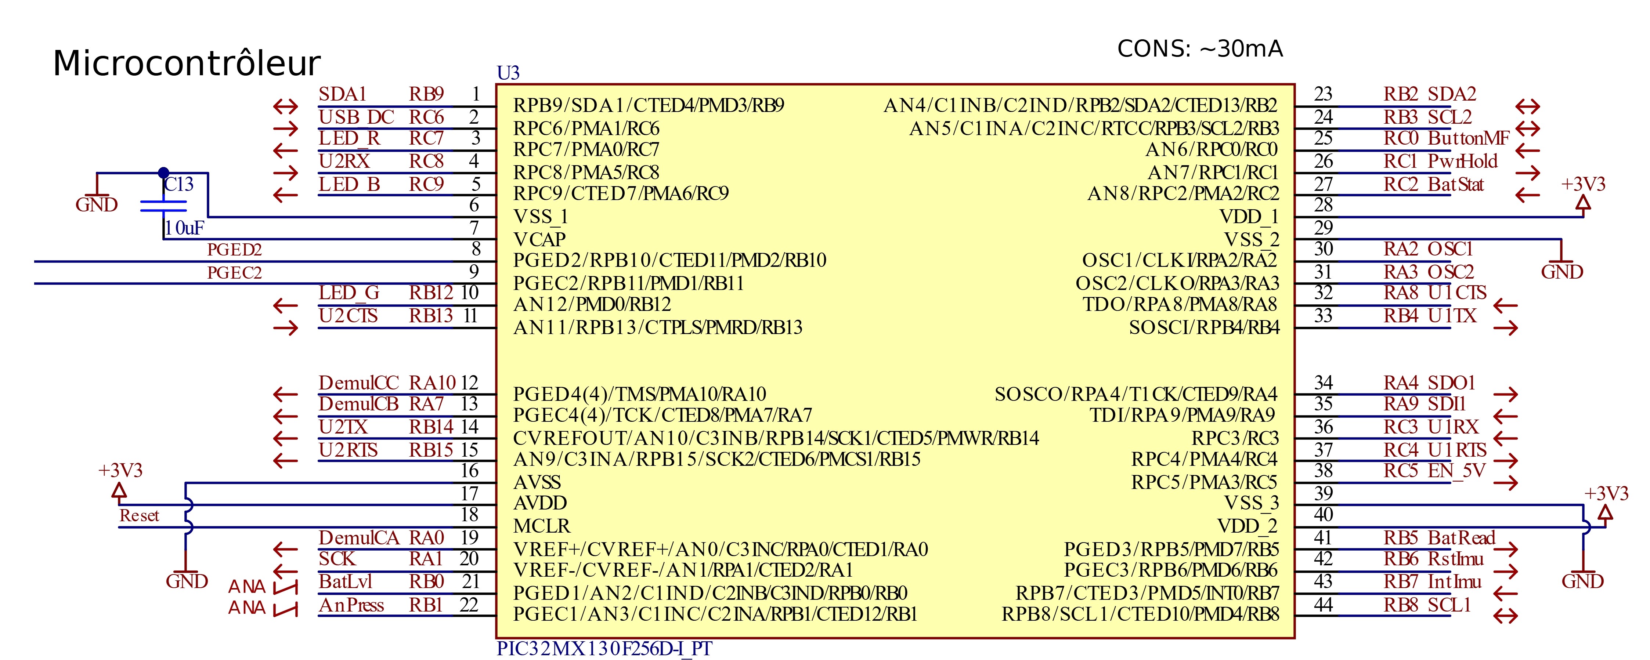
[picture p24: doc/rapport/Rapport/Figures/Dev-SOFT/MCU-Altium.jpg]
		
		\caption{Pinning réelles dans altium designer}
		\label{fig:mcu-altium}
	\end{figure}
	\begin{figure}[h]
		\centering
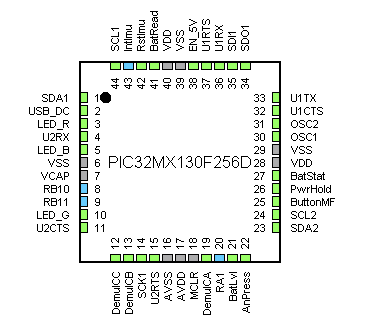
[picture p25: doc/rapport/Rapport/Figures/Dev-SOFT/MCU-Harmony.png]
		
		\caption{Pinning dans Harmony}
		\label{fig:mcu-harmony}
	\end{figure}
	
	On peut constater que la PIN 20 (SCK) est en haute impédance dans Harmony, tandis que la PIN 14, qui était supposée être \textit{U2TX}, est maintenant configurée en tant que SCK. Cela est dû à une erreur : SCK ne peut être assigné qu'à la PIN 14. Par conséquent, il a été nécessaire d'ajouter un fil externe pour relier la PIN 14 à la PIN 20, ce qui a entraîné la perte de la communication USB sur l'UART2. Cette modification sera expliquée en détail ultérieurement.

}

\subsection{Configuration des périphériques dans Harmony}
{
	\subsubsection{Timers} 
	
	Deux timers seront utilisés, l'un pour mesurer des attentes en ms et l'autre moins rapide, pour les diverses actions du programmes, avec une interruptions chaque 10ms.
	\begin{table}[h]
		\centering
		\begin{tabular}{|l|l|}
			\hline
			Timer & Temps voulu \\
			\hline
			Timer 1 & 1ms \\
			\hline
			Timer 2 & 10ms \\
			\hline
		\end{tabular}
	\end{table}

	La fréquence de l'horloge système a été augmentée à 48 MHz dans le but d'accélérer l'ensemble du système, étant donné qu'il implique de nombreuses communications nécessitant des opérations rapides, que ce soit pour la préparation des tampons de données ou les divers calculs.
	
	\begin{figure}[h]
		\centering
		
		\caption{Configuration dans harmony}
		\label{fig:timerconfig}
	\end{figure}

	\begin{figure}[h]
		\centering
		\begin{subfigure}[b]{0.45\textwidth}
			\centering
			
			\caption{Timer 1, Dimensionnement pour 1ms}
			\label{fig:timer1ms}
		\end{subfigure}
		\hfill
		\begin{subfigure}[b]{0.45\textwidth}
			\centering
			
			\caption{Timer 2, Dimensionnement pour 10ms}
			\label{fig:timer10ms}
		\end{subfigure}
		\hfill
		\caption{Application timer développée par l'auteur}
		\label{fig:appTimer}
	\end{figure}

	\clearpage

	\subsubsection{USART} \label{ssec:Usart}
	Dans le but de vérifier les données de mesure en temps réel et de faciliter le débogage, une communication sérielle UART a été mise en place. Pour cela, le périphérique UART1, initialement prévu pour le slot mikroe, a été utilisé. Un module USB-to-TTL externe sera utilisé pour lire les données via Putty sur un ordinateur.
	
	\begin{figure}[h]
		\centering
		
		\caption{Configuration UART}
		\label{fig:configuart}
	\end{figure}

	Nous pouvons constater sur la figure \ref{fig:configuart} que l'UART est configuré sans interruption à un bauderate de 115200.

	\subsubsection{Carte SD - SPI} 
	{
	L'utilisation du SPI a été optimisée en choisissant une fréquence de 5 MHz afin de réduire le temps d'exécution sur le microcontrôleur, compte tenu du grand nombre de trames nécessaires pour les opérations FAT. Cependant, j'ai rencontré un problème lié à la clock du SPI. En raison de la vitesse élevée et des modifications que j'ai dû apporter, la clock interfère inutilement avec le FTDI, et un fil relie SCK et U2TX, créant ainsi une inductance parasite. Pour résoudre ce problème, j'ai ajouté un condensateur de \textbf{33pF} entre SCK et GND pour stabiliser la communication. Vous pouvez consulter la configuration Harmony de la carte SD sur la figure \ref{fig:configsdspi}.
	\clearpage
	\begin{figure}[h]
		\centering
		
		\caption{Configuration du SPI}
		\label{fig:configsdspi}
	\end{figure}
	}

	\subsection{Code}
	Je vais dans cette section décrire le code du projet. Voici la hiérarchie des fichier du projet :
	\begin{figure}[h]
		\centering
		
		\caption{Hiérarchie des fichiers du projet}
		\label{fig:classescode}
	\end{figure}
	
	\clearpage	
	
	\subsubsection{Callbacks}
	{
	Chacun des timers appelle dans leur interruption une fonction appartenant au fichier \textit{app.c}, qui contient les actions définies pour chaque intervalle de temps spécifique. On peut visualiser cela sur le diagramme présenté dans la figure \ref{fig:callbacks}.
	
	\begin{figure}[h!]
		\centering
		
		\caption{Interactions des interruptions et des callbacks}
		\label{fig:callbacks}
	\end{figure}

	Les callbacks en C offrent flexibilité, extensibilité et réutilisabilité. Ils permettent d'ajuster dynamiquement le comportement du programme, d'étendre les fonctionnalités et de réutiliser le code. Les callbacks favorisent également l'encapsulation et la personnalisation, améliorant ainsi la modularité et la maintenance du code.	
	}
	
	\clearpage
	\subsubsection{Centrale inertielle BNO055}
	Pour ce qui est de la centrale inertielle BNO055, j'ai utilisé la bibliothèque de BOSCH \footnote{\href{https://github.com/BoschSensortec/BNO055_driver}{Bibliothèque du fabricant}}. Je l'ai configurée en 32 bits et j'ai créé les fonctions de bas niveau (i2c) en établissant le lien avec la bibliothèque BOSCH. Tout cela a été fait dans le fichier BNO055\_support.c.
	
	Pour faire le lien entre la bibliothèque de haut niveau et la bibliothèque de bas niveau, j'ai utilisé un pointeur de fonction présent dans la structure de données du BNO, comme illustré dans le listing \ref{lst:lienPointeur}.
	
\begin{lstlisting}[frame=single, label={lst:lienPointeur}, language=C, caption={Code lien pointeur de fonction}, captionpos=b]
s8 I2C_routine(void)
{
	bno055.bus_write = BNO055_I2C_bus_write;
	bno055.bus_read = BNO055_I2C_bus_read;
	bno055.delay_msec = BNO055_delay_msek;
	bno055.dev_addr = BNO055_I2C_ADDR1;
	return BNO055_INIT_VALUE;
}
\end{lstlisting}
\begin{lstlisting}[frame=single, language=C, caption={Code écriture i2c au BNO055}, captionpos=b, breaklines=true]
s8 BNO055_I2C_bus_write(u8 dev_addr, u8 reg_addr, u8 *reg_data, u8 cnt)
{
	s8 BNO055_iERROR = BNO055_INIT_VALUE;
	u8 array[I2C_BUFFER_LEN];
	u8 stringpos = BNO055_INIT_VALUE;
	array[BNO055_INIT_VALUE] = reg_addr;
	
	i2c_start();
	BNO055_iERROR = i2c_write(dev_addr<<1);
	
	for (stringpos = BNO055_INIT_VALUE; stringpos < (cnt+BNO055_I2C_BUS_WRITE_ARRAY_INDEX); stringpos++)
	{
		BNO055_iERROR = i2c_write(array[stringpos]);
		array[stringpos + BNO055_I2C_BUS_WRITE_ARRAY_INDEX] = *(reg_data + stringpos);
	}
	
	i2c_stop();
	if(BNO055_iERROR-1 != 0)
		BNO055_iERROR = -1;
	else
		BNO055_iERROR = 0;
	return (s8)(BNO055_iERROR);
}
\end{lstlisting}
	Pour ce qui est de l'utilisation de la libraire haut-niveau bno055\_support, voici la préparation et la lecture des données : 
	
	\begin{lstlisting}[frame=single, language=C, caption={Code lecture des données par la librairie}, captionpos=b, breaklines=true]
/* BNO055 Read all important info routine */
bno055_local_data.comres = bno055_read_routine(&bno055_local_data);
/* Delta time */
bno055_local_data.d_time = timerData.TmrMeas - timerData.ltime;
/* Pressure measure */
bno055_local_data.pressure = Press_readPressure();
/* Flag measure value */
bno055_local_data.flagImportantMeas = flagMeas;
	\end{lstlisting}

	\subsubsection{Carte SD}
	La  communication de la carte SD fonctionne sous forme d'une machine d'état non-bloquante, permettant ainsi de s'adapter aux situations de la carte sans bloquer le système pour autant.
	
	\begin{figure}[h]
		\centering
		
		\caption{Machine d'état de la carte SD}
		\label{fig:mermaid-diagram-2023-06-14-162436}
	\end{figure}

	\clearpage
	
	\paragraph{Planification d'une écriture}
	Afin de lancer une écriture d'un set de mesure sur la carte SD, il faut utiliser la fonction \textit{sd\_BNO\_scheduleWrite()} qui vas préparer le buffer d'écriture et modifier l'état de la carte SD : 
	\begin{lstlisting}[frame=single, language=C, caption={Lancement d'une écriture sur la carte SD}, captionpos=b, breaklines=true]
/* Write measures to sdCard */
sd_BNO_scheduleWrite(&bno055_local_data);
	\end{lstlisting}
	
	Les données sont écrite dans un fichier .CSV nommé "MESURES". La forme de la trame est la suivante :
	
	\begin{figure}[h]
		\centering
		
		\caption{Format de la trame}
		\label{fig:trame}
	\end{figure}

	\begin{lstlisting}[frame=single, language=C, caption={Ecriture du buffer}, captionpos=b, breaklines=true]
"%d;%d0;%f;%.4f;%.4f;%.4f;%.4f;%.4f;%.4f;%.4f;%.4f;%.4f;%.4f;%.4f;%.4f;%.4f;%.4f;%.4f;%d;%d;%d;%d;"
	\end{lstlisting}
	
	\paragraph{Exemple trame CSV :} 
	0;372;1.025;-0.2500;0.3800;9.7900;-0.1250;0.1250;-0.0625;-44.8750;35.0625;-7.2500;0.0000;-0.0100;-0.2700;0.0000;-2.1875;-1.5000;16379;320;216;-1;

	\subsubsection{Application main}
	On peut visualiser la machine d'état de l'application principale sur la figure \ref{fig:stateapp}.
	\begin{figure}[h]
		\centering
		
		\caption{Machine d'état application}
		\label{fig:stateapp}
	\end{figure}

	\clearpage
	
	\paragraph{Fonctionnement APP\_STATE\_LOGGING :} Une fois que l'application est en mode logging, le fonctionnement est décris sur la figure \ref{fig:appstatelogging} sous forme de flowchart.
	
	\begin{figure}[h]
		\centering
		
		\caption{Fowchart state logging}
		\label{fig:appstatelogging}
	\end{figure}

	\clearpage

}

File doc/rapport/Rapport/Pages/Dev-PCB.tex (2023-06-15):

% ------------------------- MAIN TASK ---------------------------------
\section{Développement du PCB}

\subsection{Bill of materials} \label{ssec:BOM}
{
	La BOM complète est disponible dans les répertoires du projet, voici un extrait des prix des composants importants :
	
	\begin{figure}[h]
		\centering
		
		\caption{Prix des composants}
		\label{fig:prixcomposants}
	\end{figure}
	
}
\clearpage

\subsection{Mécanique du projet} \label{ssec:mechProjet}
{
	Afin d'installer le PCB dans le boitier de la lampe, les deux tiges internes du boitier peuvent avec des attaches servir de support. Pour se faire, imprimer une pièce a visser en 3d ou en utilisant simplement des brides, pourrait permettre de maintenir la carte dans le boitier. Il faudra donc mettre des trous dans le PCB pour permettre des visses ou des brides.

	\subsubsection{Considérations mécaniques} \label{ssec:RestrictionMech}
	\paragraph{Tige conductrice :} Sachant que les tiges de support de la lampe sont conductrices, il faut donc prévoir une zone sans composant, sans cuivre apparent et si possible sans pistes sur les bords de la couche \textit{bottom}.
	\paragraph{Carte SD : } La carte SD requiert un support relativement grand et un espace doit être prévu pour pouvoir insérer/retirer la carte facilement et sans qu'elle dépasse trop du PCB.
	\paragraph{Centra inertielle :} La centrale inertielle, se connecte via des bergs femelles et vas par conséquent prendre de la place en hauteur, ce qui doit être considéré.
	\paragraph{Slot MIKROE :} Un slot mikroe est présent dans le projet et pour être implémenté, vas requérir un allongement mécanique du bouton de la lampe, pour gagner de la place. Cette pièce doit être produite et usinée, car elle requiert d'être étanche. 
	\paragraph{LED RGB :} La LED en bout du PCB peut exploiter le réfracteur déjà présent de la lampe.
	\paragraph{Connecteur USB :} Pour charger l'appareil, un port USB devrait être disponible au bord du PCB.
}
\clearpage

\subsection{Placement des composants} \label{ssec:placementComp}
{
\begin{figure}[h]
	\centering
	
	\caption{Placement alimentations}
	\label{fig:baspcb}
\end{figure}

J'ai décidé de placer en bas du PCB les parties d'alimentations du projet. Cette zone comporte :

% Please add the following required packages to your document preamble:
% \usepackage{graphicx}
\begin{table}[h]
	\centering
	\resizebox{\textwidth}{!}{%
		\begin{tabular}{|c|l|l|}
			\hline
			Composant &
			\multicolumn{1}{c|}{Detail} &
			\multicolumn{1}{c|}{Justification} \\ \hline
			USB &
			FTDI, piste 5V, pistes différentiels &
			Bord du PCB pour cablage ergonomique \\ \hline
			Capteur de pression &
			\begin{tabular}[c]{@{}l@{}}Connecteur, Jumper choix alim,\\ Choix mode (courant,tension,i2c)\end{tabular} &
			\begin{tabular}[c]{@{}l@{}}Capteur de pression proche du bord\\ branchement plus simple\end{tabular} \\ \hline
			Carte SD &
			Condos de découplages, pistes SPI &
			Plus grand consommateur \\ \hline
			Gestion batterie &
			\begin{tabular}[c]{@{}l@{}}Régulateur de charge, bouton ON/OFF,\\ régulateur 3.3V\end{tabular} &
			Zone dédiée, proche de la batterie \\ \hline
			Boost 5V (bottom) &
			Circuit de boost 3.3-5V &
			\begin{tabular}[c]{@{}l@{}}Isolé, loin des petits signaux (bruit).\\ Proche du capteur de pression (5V)\end{tabular} \\ \hline
		\end{tabular}%
	}
	\caption{Composants de la zone et justification}
	\label{tab:PlacementBas}
\end{table}
\clearpage

\begin{figure}[h]
	\centering
	
	\caption{Placement signaux}
	\label{fig:hautpcb}
\end{figure}

Le microcontrôleur est plus ou moins centrée par rapport aux différents périphériques, afin de minimiser la longueur des pistes des petits signaux. Il y a un bouton de reset, un multiplexeur et un oscillateur externe, au plus proche du MCU.
}
\clearpage

\subsection{Mécanique du PCB}
{

	\begin{figure}[h]
		\centering
		
		\caption{Plan mécanique du PCB}
		\label{fig:2221pcbmechdimspage-0001}
	\end{figure}
	La conception du PCB comprend des dimensions spécifiques, avec une longueur de 188.15 mm, une largeur de 40.51 mm et une hauteur de 27 mm. Pour faciliter l'installation et la fixation, cinq trous M3 sont répartis le long du PCB. Cependant, la présence du socle de la pile, qui a une hauteur de 15.9 mm, peut poser un problème, car il peut entraver le placement du PCB.
	Afin de résoudre cette contrainte, une décision a été prise de positionner le socle de la pile au centre du PCB. Cette disposition permet de mieux répartir l'espace disponible et d'éviter que le socle de la pile ne perturbe les autres contraintes mécaniques.
	En examinant une représentation en 3D de la carte, on peut constater que la carte SD simulée s'intègre parfaitement à la surface du PCB et ne dépasse pas ses dimensions.
}

\clearpage
\subsection{Routage} \label{ssec:routage}
{
	\begin{figure}[h]
		\centering
		
		\caption{Pistes du PCB}
		\label{fig:pistespcb}
	\end{figure}
	
	Routage sur 4 couches, chacune possède une orientation de piste : Top-Horizontal, Bottom-Vertical, Layer1-Vertical, Layer2-Vertical. La zone la plus denses est celle du microcontrôleur, c'est aussi où il y a le plus de vias. On peut voir que les pistes du bas sur la figure \ref{fig:pistespcb} sont plus épaisses, c'est parce que ce sont les pistes d'alimentations principales. Le 3.3V a une arborescence en arbre, avec le tronc qui traverse le PCB et les branches qui vont alimenter les différents systèmes, en passant bien d'abord par les condensateur de découplages de chacun. 
	\paragraph{Piste différentiel :} L'USB possède une piste différentiel Data+/Data-, on peut la voir en bas de la figure \ref{fig:pistespcb} (Couche brune).
}
\clearpage

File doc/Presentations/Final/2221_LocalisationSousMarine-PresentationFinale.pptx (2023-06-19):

## PRESENTATION FINALE

Localisation sous-marine 2221
Système de logging pour algorithme de localisation sous-maine


Ali Zoubir

ETML-ES
Génie électrique

## STRUCTURE

1. Concept et caractéristiques
2. Design
3. Validation
4. Caractéristiques finales
5. Conclusion
6. Démonstration

TABLE DES MATIERES

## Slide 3

CONCEPT & INTRODUCTION

## INTRODUCTION

CONCEPT

L’objectif de ce projet, et de stocker des données de mesures du déplacement d’un
module sous-marin par une centrale inertielle, dans le but de le localiser.

Micro Sd Images - Free Download on Freepik
Goupille de localisation - Icônes cartes et emplacement gratuites
Gagnez une lampe de plongée SUPE - chercheursdeau
6: Example sensor data from an IMU sensor placed on the lateral side of... | Download Scientific Diagram

## INTRODUCTION

CARACTERISTIQUES

PRINCIPALES

- Sensing sur 9 axes.
- Sauvegarde d’un set de donnée chaque 100ms.
- 2 heures de logging dans une carte SD.
- Possibilité de sauvegarder la localisation de points d’intérêts.
- Profondeur d’utilisation maximum, de 60m.
- Batterie, autonomie minimum de 2 heures
- Charge de la batterie par connecteur USB.

SECONDIRES

- Lecture des données par connecteur USB (Interfaçage électronique, software optionnel
dans cette version).
- Interface LED ou petit écran.

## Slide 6

DESIGN

## DESIGN

SCHEMA BLOC


## DESIGN

TECHNOLOGIES


Pression : 10 [bars]
Température : -40 … 125 [°C]
Courant : 7 [mA]

BNO055 IMU Fusion Breakout - Stemma QT - Adafruit | Mouser

Profondeur : 950 [m]
Température : 0… 40 [°C]
Tension max : 26 [V]


Mémoire : 64+3 [kB]
Pins : 44 [-]
Timers : 5 [-]
UART : 2 [-]
SPI : 2 [-]
I2C : 2 [-]
ADC : 3 [-]
RTCC : Oui

ECELL ECE18650 Pile rechargeable spéciale 18650 Li-Ion 3.7 V 3400 mAh - Conrad Electronic Suisse
Kingbright3.2 V, 4.1 V, 4.5 V RGB LED 5050 SMD, KAAF-5050RGBS-13 | RS

## DESIGN

METHODOLOGIE - INTERFACES

DONNEES IMU

I2C

CLICK BOARD

UART, SPI, I2C, ADC

CARTE SD

SPI

CLICK BOARD

UART, SPI, I2C, ADC

DONNEES IMU

I2C

3,3 TO 5V

XC9140A501MR-G

PRESSION

ADC

NIVEAU BATTERIE

ADC – MCP73871

## DESIGN

PRIX PRINCIPAUX


## DESIGN

MECANIQUE - CONTRAINTES

TIGE CONDUCTRICES

Il faut prévoir une zone sans composant, sans cuivre apparent et si possible sans pistes sur les
bords de la couche bottom.

CARTE SD

La carte SD requiert un support relativement grand et un espace doit être prévu pour pouvoir insérer/retirer la carte facilement et sans qu’elle dépasse trop du PCB.

IMU

La centrale inertielle, se connecte via des bergs femelles et vas par conséquent prendre de la place en hauteur, ce qui doit être considéré.

CLICK BOARD

Un slot mikroe est présent dans le projet et pour être implémenté, vas requérir un allongement mécanique du bouton de la lampe, pour gagner de la place.

## DESIGN


BAS DU PCB


MECANIQUE - PLACEMENT

## DESIGN


HAUT DU PCB

MECANIQUE - PLACEMENT

## DESIGN

MECANIQUE - DIMENSIONS


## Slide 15

VALIDATION

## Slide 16

CARACTERISTIQUES FINALES

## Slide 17

CONCLUSION

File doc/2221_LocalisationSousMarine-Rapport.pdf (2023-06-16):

# Localisation sous-marine

# Système de logging pour déplacement de module

sous-marin.

# Ali Zoubir

# Rapport de projet

# Génie électrique École supérieure Suisse 16 juin 2023

PROJET 2221 | 16 juin 2023 | LocalisationSousMarine

## Table des matières

1 Cahier des charges | | 4
2 Pré-étude | 8
3 Développement schématique | 17
4 Développement du PCB | 28

PROJET 2221 | 16 juin 2023 | LocalisationSousMarine
5 Développement firmware | 34
6 Validation du design | 43
7 Caractéristiques du produit fini | 48
8 Conclusion | 49
9 Bibliographie | 50
10 Annexes | 51

ETML-ES | 16 juin 2023 | Localisation sous-marine V0.0

# Localisation sous-marine

2022, V0.0

## 1 Cahier des charges

### 1.1 Description

L´ objectif de ce projet, et de stocker des données de mesures du déplacement dun module sous-marin par une centrale inertielle, dans le but de mathématiquement le localiser depuis son point de départ (référence). Ceci, car la localisation sous-marine nest pas une tâche aisée due aux différentes contraintes de communication sous-marine notamment le fait que les ondes électromagnétiques ne sy propagent pas facilement.

### 1.2 Aperçu

— Sauvegarde dun set de donnée chaque 100ms. — Profondeur dutilisation maximum, de 60m.
— 2 heure de logging dans carte SD.
— Sensing sur 9 axes :
Mesures [Il est souhaitable que les capteurs choisis aient une faible dérive]; Accéléromètre 3-axes.
Gyroscope 3-axes.
Magnétomètre 3-axes.
Senseur de température
Profondimètre [0->10bar] [Res 1/10]
3 à 5 slots libres MikroE pour autres mesures.
— Possibilité de sauvegarder la localisation de points dintérêts par :
Bouton de sauvegarde [A définir : Magnétique, Optique, Mécanique ou autre].
— Batterie, autonomie minimum de 2 heures [∼10°C].
— Charge de la batterie par connecteur USB.
— (Optionnel) Lecture des données par connecteur USB (Interfaçage électronique, software optionnel dans cette version).
— (Optionnel) Interface LED ou petit écran.

### 1.3 Tâches à réaliser

Développement et intégration dun PCB avec capteurs et logging sur carte SD dans une lampe de plongée étanche.
Développement schématique
- Fonctionnement MCU.
- Périphériques de mesures et de sauvegarde / Bus de communication.
- Gestion batterie
Routage pour intégration dans boitier de lampe de plongée 200x45mm. Programmation mesure et sauvegarde chaque 100ms.
- Configuration MCU.
- Configuration des périphériques de mesure pour 9-DOF.
- Configuration des périphériques de sauvegarde (Carte SD).
- Configuration et communication avec l’interface.
- Communication et traitement des données mesurées.

FIGURE 1 – Schéma de principe Source : Auteur

### 1.4 Description des blocs

1. Carte SD :
Stockage des données de mesures chaque 100ms, cur du projet.
2. Accéléromètre-gyroscope-magnétomètre :
Lecture des données individuelles brute ainsi que de fusion des capteurs, pour mesurer les déplacements sur 9 degrés de libertés.
3. Profondimètre :
Mesure la pression pour déduire la profondeur, afin de corroborer les autres mesures des capteurs.
4. Real time clock :
Permet de sauvegarder la temporalité du set de mesure dans la carte SD.
5. Affichage :
Affichage LED ou écran, pour affichage pas encore définis (ex. Profondeur, état batterie)
6. Bouton sauvegarde :
Permet la mise en valeur dun set de mesure. La forme de ce bouton nest pas encore définie. Il sera peut-être fusionné avec le bouton ON/OFF.
7. Bouton ON/OFF :
Permet dallumer ou déteindre le système.
8. Batterie :
Batterie du système, technologie à définir dans la pré-étude.
9. COM. USB :
Permet de charger les batteries. Il faudra également prévoir dans cette version linterface électronique pour la lecture de la carte SD directement par le port USB.
10. Microcontrôleur :
Lis et traite les valeurs des capteurs, sauvegarde dans la carte SD...

### 1.5 Jalons principaux


FIGURE 2 – Jalons principaux

### 1.6 Livrable

Les fichiers sources de CAO électronique des PCB réalisés
Tout le nécessaire à fabriquer un exemplaire hardware de chaque :
fichiers de fabrication (GERBER) / liste de pièces avec références pour commande / implantation
Prototype fonctionnel
Modifications / dessins mécaniques, etc
Les fichiers sources de programmation microcontrôleur (.c / .h)
Tout le nécessaire pour programmer les microcontrôleurs (logiciel ou fichier .hex)
Un calcul / estimation des coûts
Un rapport contenant les calculs - dimensionnement de composants - structogramme, etc.

## 2 Pré-étude

L’objectif de cette pré-étude, est de se pencher sur le fonctionnement plus fondamental du système, faire des petits dimensionnements ainsi que de survoler différents aspects techniques liés au projet.

### 2.1 Fonctionnement du système

### 2.1.1 Schéma bloc

FIGURE 3 – Schéma bloc du module Source : Auteur

Capteurs : Les différents capteurs sont interfacés sur le même bus, et ont comme master le microcontrôleur en communication bidirectionnel, afin d’à la fois configurer les registres des périphériques et de lire leurs mesures.

Carte SD : La carte SD est interfacée en SPI et va contenir les données des différents capteurs ainsi que leurs éventuels flags d’importance (sauvegarde), sa taille sera dimensionnée ultérieurement.

Port USB & charge : Un port USB est présent, afin charger les batteries par un IC de gestion de charge connecté directement au 5V. De plus le port USB est communiquant avec le microcontrôleur par un driver FTDI, afin d’éventuellement ajouter un système de lecture de la carte SD, directement par USB. Ceci dans cette version ou une ultérieure. Le port USB pourrait aussi servir a fixer la référence de la RTC.

Bouton multifonction : Un bouton étanche sera présent sur le module, l’exploiter en tant que bouton multifonction est une solution ergonomique pour ne pas mettre en péril l’étanchéité globale. Ce bouton ferait office de ON/OFF et de "sauvegarde" de point d’intérêt. Pour se faire, le bouton contrôlerait par un transistor de commutation l’alimentation du système, puis lors de l’allumage du microcontrôleur, le MCU prendrait la relève en maintenant le système allumé a sont tour, permettant ainsi de lire le bouton et de sur une pression longue déconnecter l’alimentation.

Affichage : L’affichage permettra de visualiser différentes données, dont les plus importantes tel que la pression ou le statut de la batterie. La forme de l’affichage est encore a définir selon la mécanique du module, mais le plus élégant, serait l’utilisation d’un petit écran OLED.

Capteur de pression : Le capteur de pression devra avoir un contact direct avec l’eau, cela impliquera de la mécanique et de la gestion d’étanchéité. Une autre possibilité aurait été de mesurer optiquement la déformation du boîtier pour en déduire la pression, mais la complexité est trop importante.

### 2.2 Choix des composants importants

### 2.2.1 Senseur absolu

Pour le senseur absolu, il existe des IC permettant directement de faire la fusion des senseurs (Accéléromètre, gyroscope, magnétomètre et thermomètre), ce qui épargne toute une phase de calcul chronophage, en permettant directement de lire les quaternion, angles de Euler, vecteurs de rotations, cap de direction etc... directement sur le composant. Il existe différents IC dont deux ce sont montrés très intéressants, le BNO85 et le BNO55, les deux étant PIN-Compatibles, j’ai décidé d’opter pour le BNO055 ¹

FIGURE 4 – Schéma bloc du module Source : https://www.mouser.ch/new/bosch/bosch-bno55-sensor/

Sachant que la brazure de ce type de boîtier est compliquée et également dans un but de
simplification du projet, j’ai décidé d’utiliser les cartes d’évaluation d’adafruit Nr : 4646 ˇ | qui
ont des connections bergs ainsi que tous les composants externes passifs déjà montés.

Caractéristiques importantes :

Résolution gyroscope | : 16 | [bits]
Résolution accéléromètre | : 14 | [bits]
Résolution magnétomètre : ∼0.3 | [µT]
IDD | : 12.3 | [mA]
Dérive de température | : ± 0.03 [%/K]
Dérive accéléromètre | : 0.2 | [%/V]
Dérive gyroscope | : <0.4 | [%/V]
Nous allons par la suite voir sur la figure 5, quelles données du BNO055 sont disponibles ainsi que leurs tailles mémoires.
1. K:/ES/PROJETS/SLO/2221_LocalisationSousMarine/doc/composants/9DOF-BNO055


FIGURE 5 – Donnée de sortie de l’IC (43 bytes) Source : https://cdn-shop.adafruit.com/datasheets/BST_BNO055_DS000_12.pdf

### 2.2.2 Capteur de pression

Pour le capteur de pression, une modification mécanique du boîter sera très probablement nécessaire. J’ai pu trouver un capteur correspondant aux caractéristiques demandée du projet, celui-ci est plutôt générique et peut communiquer en I2C :
PTE7300-14AN-1B016BN

FIGURE 6 – Illustration capteur de pression Source : Distrelec, PTE7300-14AN-1B016BN (https://www.distrelec.ch/fr/capteur-de-pression-hermetique-numerique-industriel-g1-16bar-module-sensata-pte7300-14an-1b016bn/p/30302457)

L’avantage avec le capteur ci-dessus est le système hermétique pour le trou, un autre capteur peut être utilisé lors de l’étude, néanmoins la modification mécanique étant probablement inévitable, le système de vissage de la figure 6 est intéréssant.

Changement : Le capteur de pression n’étant plus disponible, nous avons dû opter pour une alternative qui est :

FIGURE 7 – Capteur de pression alternatif Source : Distrelec, MIPAM1XX010BAAAX (https://www.distrelec.ch/fr/capteur-de-pression-isoles-du-milieu-m12-10-bar-pression-absolue-honeywell-mipam1xx010baaax/p/30173754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)

### 2.2.3 Affichage

Pour l’affichage, je vais essayer d’opter pour un petit afficheur OLED, en gardant la possibilité en cas de de complication lors de l’étude, l’utilisation de simples LEDS d’indications. Il existe plusieurs affichages OLED rond petits formats, sur lesquels je me pencherais plus en détail lors de l’étude.

### 2.2.4 Carte SD

Taille mémoire : Afin de dimensionner la taille de stockage de la carte SD, il faut utiliser les différentes caractéristiques du projet. Normalement la taille de la carte SD n’est clairement pas un problème, sachant que seulement du texte est enregistré et que les tailles mémoires disponibles peuvent être très élevées. Néanmoins il est intéressant de faire le dimensionnement pour connaître le minimum, et pour éventuellement adapter le projet avec d’autres systèmes de mémorisation.
Où :
Trec | = 7200⁰000 [ms] | Temps a enregistrer
Tech | = 100 | [ms] | Temps d’un échantillon
Smes | = 150 | [bytes] | Taille de toutes les données de mesures
Stimestamp | = ∼3 | [bytes] | Taille de l’information de temporalité
Sf lag | = 1 | [bytes] | Taille de l’indication d’importance

Nombre de mesure a effectuer :

Nbmesures =

Trec

Tech

(1)

D’après (1), nous avons un nombre de mesure de 72’000.

Taille minimum :

Taillemin = Nbmesures ∗ (Smes +Stimestamp +Sf lag) | (2)

D’après (2), la taille mémoire minimum doit être de ∼11MB.

Nous pouvons donc constater que pour une utilisation standard de 2h, la mémoire occupée est très faible, d’où l’intérêt de sauvegarder dans la carte SD la date, afin de pouvoir faire plusieurs "expéditions" en "une fois", sans avoir à vider la carte.

### 2.2.5 Real Time Clock

L’objectif de la RTC, est de donner l’information de la temporalité de la mesure (timestamp), afin de lors du traitement des donnée avoir accès à ce paramètre.
Sachant que l’échantillonnage des mesures est de 100ms, la RTC devrait permettre cette résolution. Néanmoins une autre information importante, comme mentionnée lors de la section 2.2.4, est la date de la mesure, afin de permettre plusieurs expéditions par utilisation de la carte.

J’ai donc décidé d’utiliser une RTC pour l’heure grossière de départ (Année, date, heure, minute, seconde) et les compteur du MCU pour faire le delta entre chacune des mesures en ms.

La RTC devra pouvoir tenir le minimum de 2 heure d’utilisation, à cette fin, la batterie LI-ION déjà présente sera suffisante.
La RTC devra avoir une faible consommation, le calendrier ainsi qu’une bonne précision. A cette fin, la RTC S-35390A-T8T1G est assez générique et possède une bonne documentation.

changement : L’utilisation d’une RTC/RTCC a été remplacée par une simple mesure de différence de temps entre chaque mesures.

### 2.2.6 Microcontrôleur

Le microcontrôleur devra avoir un nombre suffisant de communications, sachant que beaucoup sont présentes dans le projet (I2C, SPI, UART...), ce qui signifie un nombre de pattes élevées.
Des calculs peuvent aussi être nécessaire, si il s’avère qu’il faille faire une traitement des données préliminaire, il faudrait donc opter pour un MCU 32bits si possible.
La famille PIC est celle standardisée par l’école supérieure, c’est donc pour cette famille-ci que je vais opter.

FIGURE 8 – Illustration du modèle MCU du kit ETML-ES Source : https://www.microchip.com/en-us/product/PIC32MX795F512L

### 2.2.7 Batterie, charge et régulation

Pour la technologie de batterie, en utilisation sous-marine, j’ai trouvé ce tableau de comparaison :

FIGURE 9 – Comparaison des technologies de batteries Source : Power Systems for Autonomous Underwater Vehicles[1]

Pour des raisons de praticité et étant-donné la documentation plus importante, j’ai décidé d’utiliser la technologie LI-ION :

Avantages | Inconvénient
Haute densité d’énergie | Risque d’éclatement
Poids léger | Risque d’enflammement avec l’eau
Haute durée de vie | Sensible a la température
Charge rapide | Décharge complète altérante

TABLE 1 – Tableau avantages/inconvénient LI-ION)

Malgré les risque dûs au contact de l’eau (Enflammement, éclatement...) la technologie LI-ION est souvent utilisée pour les application sous-marines dû a ses différents avantages, c’est pour cela que j’opterais pour cette technologie.

### 2.3 Estimation des coûts

Ici je vais me baser sur les composants que j’ai pu trouver et estimer le coût moyen de ceux-ci, c’est a titre purement indicatif, (les prix sont généralement estimés a la hausse).

Composant | Estimation
Profondimètre | 70.-
Centrale inertielle | 35.-
RTC | 5.-
Microcontrôleur | 5.-
Carte SD | 20.-
Affichage OLED | 45.-
FTDI | 4.-
Batterie LI-ION | 20.-
IC chargeur | 4.-
Traco-power 3.3V | 10.-
PCB | 40.-
Total | 258.-

L’estimation des prix étant plutôt élevée, des économies peuvent être très facilement réalisées, en changeant l’affichage OLED pour des LEDS ou en modifiant le PCB (Le simplifier ou changer de fournisseur (eurocircuit)).

### 2.4 Synthèse développement

J’ai pu lors de cette pré-étude, établir le fonctionnement global du système, choisir certaines technologies et composants importants, ainsi que pu procéder a certains dimensionnements utiles quant au futur développement. Par la suite, je vais affiner les différents éléments abordés lors de la pré-étude, effectuer le développement plus détaillé de chacun des blocs et réaliser la schématique du projet. Lors de la pré-étude, je n’ai pas eu accès au boîtier mécanique du projet, ce qui a restreint mon champs d’action lors de certains dimensionnement, tandis que pendant l’étude j’aurais accès a celui-ci, ce qui risque d’impacter/modifier certains aspect fixés lors des section antérieures. Je suis très intéressé par le projet et me réjouis grandement de poursuivre son développement.

## 3 Développement schématique

### 3.1 Scéma bloc détaillé


FIGURE 10 – Schéma bloc détaillé Source : Auteur

### 3.2 Choix des composants

### 3.2.1 Microcontrôleur

Lors de la recherche de composants, j’ai décidé d’utiliser l’un des PIC32 standards de l’ES : PIC32MX130F064D-I/PT.

FIGURE 11 – Périphériques disponibles du PIC Source : PIC32MM0256GPM064 family datasheet (https://ww1.microchip.com/downloads/aemDocuments/documents/OTH/ProductDocuments/DataSheets/PIC32MM0256GPM064-Family-Data-Sheet-DS60001387D.pdf)

Nous pouvons constater sur la figure 11 que les critères minimaux de mon projet sont respectés :

1 - I2C | 1 - SPI | 1 - UART | 1 - RTCC

### 3.3 Dimensionnements

### 3.3.1 Vue d’ensemble schématique


FIGURE 12 – Schéma bloc de la schématique Source : Auteur
Nous pouvons constater sur la figure 12 la structure des différents blocs du schéma :
Bloc | Description
Power | Contient les différents régulateurs du sys-tème, ainsi que la gestion de charge de la bat-terie.
MCU | Contient l’intelligence du système, avec le microcontrôleur ainsi que tous ses compo-sants passifs associés.
Peripherals | Périphériques du système : Carte-SD, Cen-trale inertielle, Capteur de pression, Slots Mi-kroE.
Interface | Connecteur USB avec convertisseur serial (FTDI) et tous les composants passifs de sé-curité. Interface LED RGB pour le statut.

### 3.3.2 Autonomie du système

Afin de proportionner la batterie du circuit, il a fallut dimensionner les différentes consommations des composants, ceci par le biais de leurs documentations :

MCU - 30mA | BNO055 - 12.3mA | Capt. Pression - 4mA | Carte-SD - 100mA
MikroE - ??mA | Régulateurs - 40uA | LED RGB - 25mA

Nous pouvons constater que la plus grande consommation vient de la carte micro-SD, qui au maximum peut induire 100mA. ²
Afin d’obtenir une autonomie d’au moins 2h (selon CDC), il faudrait une capacité de :
Capacite = Consommationtot ∗Temps | (3)

Ce qui nous fait une capacité de ∼342.68mAh, valeur facilement atteignable par les batteries li-ion du marché. Étant-donné que différents projets utilisaient des batteries 3400mAh, dans un objectif de conformité et de simplification des commandes, j’ai choisis cette même valeur. Ce qui signifie une autonomie de ∼20 heures, sans compter les différents mécanismes d’économie d’énergie.
C’est un temps largement suffisant pour la durée de plusieurs expéditions, néanmoins la RTCC du microcontrôleur pourrait requérir d’être alimentée en permanence, on pourrait donc imaginer un fonctionnement où lorsque l’on charge la batterie la date se mettrait à jour et le mode "éteint" serait juste un mode de veille qui attendrait un niveau positif sur le switch avant de commencer le logging avec un timsetamp principale contenant la date, puis, seulement des deltas entre les mesures. Un diagramme des états est présents à la figure 13.
2. Datasheet SanDisk (https://images-na.ssl-images-amazon.com/images/I/91tTtUMDM3L.pdf)

FIGURE 13 – Diagramme des états du système Source : Auteur

### 3.3.3 LED Interface

Afin d’informer l’utilisateur de ce qu’il se passe dans le système, j’ai décidé d’implémenter en tant qu’interface, une led RGB. Celle-ci sera un minimum puissante, afin de pouvoir être lisible lors de l’utilisation sous-marine du module.
La consommation de la led RGB étant relativement importante, des mécanismes d’économie d’énergie seront mis en place dans le développement firmware.

Diagramme d’interface :

FIGURE 14 – Définitions des états de la LED RGB Source : Auteur

### 3.3.4 Adaptation mécanique

L’idée étant d’obtenir une mesure de pression sans modification mécaniques sur le boîtier originale, plusieurs idées ont émergées :
1) Mesurer une déformation mécanique a-même le module, dans le but de déduire la pression (Développement d’un capteur).
2) Ajout d’une rallonge cylindrique au module, afin de fixer un capteur de pression à plat sur celui-ci, tout en permettant les modifications mécaniques sans altération du boîtier originale.
Par sa complexité moins importante et due aux contraintes de temps, la seconde option seracelle développée lors de cette version du projet. Voici des ébauches (Pas à l’échelle) du concept :


FIGURE 15 – Ébauche intérieur du cylindre

Source : Auteur

FIGURE 16 – Ébauche globale

Source : Auteur

### 3.3.5 Bus de communications

UART (1) :
Utilisation : Communication avec les boards Mikroe, pour les clicks-boards utilisant la comm. série.
Pinning :

UART (2) :
Utilisation : Communication avec FTDI conversion USB-Serial. Transfert des fichiers de la carte-SD et mise-à-jour de la RTCC.
Pinning :

SPI :
Utilisation : Communication avec la carte micro-SD, écriture des mesures, timestamps et flag d’importance.
Pinning :

I2C (1) :
Utilisation : Lecture des mesure de la centrale inertielle BNO055 et paramétrage des registres de celui-ci.
Pinning :

I2C (2) :
Utilisation : Lecture des données du capteur de pression et est également connecté aux slots Mikroe, pour permettre à ceux-ci de communiquer via I2C.
Pinning :

Pour ce qui est des mesures sur ces différents bus de communications, des connecteurs bergs ont étés prévus, afin de pouvoir connecter facilement un analyseur logique sur les différentes trames :


FIGURE 17 – Connecteurs pour analyseur logique

Une contrainte s’est crée, lorsque toutes les pins du microcontrôleur ont été allouée alors qu’il restait des connexion pour les "Chip select" et "Reset" des carte click-board Mikroe. Afin de remédier à ce problème, j’ai décidé d’utiliser un démultiplexeur, sachant que chacune des ces PINS, peuvent être activée seulement une à une :

FIGURE 18 – Demultiplexeur

### 3.3.6 Périphériques


FIGURE 19 – Carte-SD, capteur de pression et centrale inertielle.

Pour la carte-SD, certaines pins ne sont pas utilisée car pas utile dans le cadre du projet (Ex : Pin CD (Card Detect)). Pour le capteur de pression, il s’agit d’un simple connecteur (AMTEK 5H2001N0-105PXBL00A01) qui vas venir connecter le senseur rattaché à l’extension mécanique. Quant à la centrale inertielle (BNO055 adafruit-board) le bit d’adresse supplémentaire est mis à 0.

FIGURE 20

Les slots Mikroe (3x figure 20) sont prévus pour pouvoir utiliser le plus de bus de communication possibles. Les jumpers sont prévus pour éviter les collisions sur les lignes.

### 3.3.7 Chargeur de batterie

Ici je vais me pencher sur les dimensionnement des 3 résistances PROG du composant de régulation et de charge d’accu, les autres composants passifs n’ont pas requis de dimensionnements particuliers.


FIGURE 21 – IC régulation et gestion charge de l’accu

Afin de déterminer le comportement de la charge via les différentes étapes de courants, quelques équations ont été utiles :
Où
C = 3400mAh
ratioterm = 0.05 ratiochrg = 0.1
Iterm = C∗ ratiochrg | (4)

D’après 4, Iterm = 170mA.

Rprog3 =

1000V Iterm | (5)

D’après 6, Rprog3 = 5k88Ω E12 =⇒ 6k2Ω (Arrondis au supérieur pour limiter courant de terminaison).

Rprog1 =

1000V C∗ ratiochrg | (6)

D’après 6, Rprog1 = 2k94Ω E12 =⇒ 2k2Ω (Arrondis à l’inférieur pour limiter courant de charge).

### 3.3.8 Synthèse et perspectives de l’étude

Lors du développement de la schématique, je n’ai pas eu de grands dimensionnements à faire mais plutôt dû mettre en place des mécanismes permettant la communication avec tous les senseurs et périphériques du système. J’ai essayé d’être le plus explicite possible lors de la création des différents blocs du schéma électrique, pour permettre une compréhension aisée de celui-ci. J’ai pû faire un contrôle mutuel de la schématique avec mon collègue M. Meven Ricchieri. Je n’ai pas rencontré de problèmes particuliers, j’ai pus compléter la schématique, avancer sur le concept globale et je suis très enthousiaste de continuer ce projet. Désormais il vas falloir préparer la création du PCB, en contrôlant les footprints du circuit et développer d’avantage l’aspect mécanique du projet. La schématique issue de cette partie développement, sera disponible en annexe de ce rapport.

## 4 Développement du PCB

### 4.1 Bill of materials

La BOM complète est disponible dans les répertoires du projet, voici un extrait des prix des composants importants :

FIGURE 22 – Prix des composants

### 4.2 Mécanique du projet

Afin d’installer le PCB dans le boitier de la lampe, les deux tiges internes du boitier peuvent avec des attaches servir de support. Pour se faire, imprimer une pièce a visser en 3d ou en utilisant simplement des brides, pourrait permettre de maintenir la carte dans le boitier. Il faudra donc mettre des trous dans le PCB pour permettre des visses ou des brides.

### 4.2.1 Considérations mécaniques

Tige conductrice : Sachant que les tiges de support de la lampe sont conductrices, il faut donc prévoir une zone sans composant, sans cuivre apparent et si possible sans pistes sur les bords de la couche bottom.

Carte SD : La carte SD requiert un support relativement grand et un espace doit être prévu pour pouvoir insérer/retirer la carte facilement et sans qu’elle dépasse trop du PCB.

Centra inertielle : La centrale inertielle, se connecte via des bergs femelles et vas par conséquent prendre de la place en hauteur, ce qui doit être considéré.

Slot MIKROE : Un slot mikroe est présent dans le projet et pour être implémenté, vas requérir un allongement mécanique du bouton de la lampe, pour gagner de la place. Cette pièce doit être produite et usinée, car elle requiert d’être étanche.

LED RGB : La LED en bout du PCB peut exploiter le réfracteur déjà présent de la lampe.

Connecteur USB : Pour charger l’appareil, un port USB devrait être disponible au bord du PCB.

### 4.3 Placement des composants

FIGURE 23 – Placement alimentations

J’ai décidé de placer en bas du PCB les parties d’alimentations du projet. Cette zone comporte :

Composant | Detail | Justification
USB | FTDI, piste 5V, pistes différentiels | Bord du PCB pour cablage ergonomique
Capteur de pression | Connecteur, Jumper choix alim, Choix mode (courant,tension,i2c) | Capteur de pression proche du bord branchement plus simple
Carte SD | Condos de découplages, pistes SPI | Plus grand consommateur
Gestion batterie | Régulateur de charge, bouton ON/OFF, régulateur 3.3V | Zone dédiée, proche de la batterie
Boost 5V (bottom) | Circuit de boost 3.3-5V | Isolé, loin des petits signaux (bruit). Proche du capteur de pression (5V)

TABLE 2 – Composants de la zone et justification


FIGURE 24 – Placement signaux

Le microcontrôleur est plus ou moins centrée par rapport aux différents périphériques, afin de minimiser la longueur des pistes des petits signaux. Il y a un bouton de reset, un multiplexeur et un oscillateur externe, au plus proche du MCU.

### 4.4 Mécanique du PCB

FIGURE 25 – Plan mécanique du PCB

La conception du PCB comprend des dimensions spécifiques, avec une longueur de 188.15 mm, une largeur de 40.51 mm et une hauteur de 27 mm. Pour faciliter l’installation et la fixation, cinq trous M3 sont répartis le long du PCB. Cependant, la présence du socle de la pile, qui a une hauteur de 15.9 mm, peut poser un problème, car il peut entraver le placement du PCB. Afin de résoudre cette contrainte, une décision a été prise de positionner le socle de la pile au centre du PCB. Cette disposition permet de mieux répartir l’espace disponible et d’éviter que le socle de la pile ne perturbe les autres contraintes mécaniques. En examinant une représentation en 3D de la carte, on peut constater que la carte SD simulée s’intègre parfaitement à la surface du PCB et ne dépasse pas ses dimensions.

### 4.5 Routage


FIGURE 26 – Pistes du PCB

Routage sur 4 couches, chacune possède une orientation de piste : Top-Horizontal, Bottom-Vertical, Layer1-Vertical, Layer2-Vertical. La zone la plus denses est celle du microcontrôleur, c’est aussi où il y a le plus de vias. On peut voir que les pistes du bas sur la figure 26 sont plus épaisses, c’est parce que ce sont les pistes d’alimentations principales. Le 3.3V a une arborescence en arbre, avec le tronc qui traverse le PCB et les branches qui vont alimenter les différents systèmes, en passant bien d’abord par les condensateur de découplages de chacun.

Piste différentiel : L’USB possède une piste différentiel Data+/Data-, on peut la voir en bas de la figure 26 (Couche brune).

## 5 Développement firmware

Dans cette section, nous allons décrire et expliquer le processus de programmation du code qui a été implémenté dans le microcontrôleur PIC32MX130F256D. Le processus de programmation du code dans le PIC32MX130F256D comprend plusieurs étapes. Tout d’abord, il est nécessaire de disposer d’un environnement de développement intégré (IDE) adapté à ce microcontrôleur, tel que MPLAB X IDE. Cet IDE est équipé de l’environnement Harmony, qui permet l’utilisation d’un configurateur graphique pour les différentes bibliothèques du PIC.

### 5.1 Configuration des PINs dans Harmony

FIGURE 27 – Pinning réelles dans altium designer


FIGURE 28 – Pinning dans Harmony

On peut constater que la PIN 20 (SCK) est en haute impédance dans Harmony, tandis que la PIN 14, qui était supposée être U2TX, est maintenant configurée en tant que SCK. Cela est dû à une erreur : SCK ne peut être assigné qu’à la PIN 14. Par conséquent, il a été nécessaire d’ajouter un fil externe pour relier la PIN 14 à la PIN 20, ce qui a entraîné la perte de la communication USB sur l’UART2. Cette modification sera expliquée en détail ultérieurement.

### 5.2 Configuration des périphériques dans Harmony

### 5.2.1 Timers

Deux timers seront utilisés, l’un pour mesurer des attentes en ms et l’autre moins rapide, pour les diverses actions du programmes, avec une interruptions chaque 10ms.

Timer | Temps voulu
Timer 1 | 1ms
Timer 2 | 10ms

La fréquence de l’horloge système a été augmentée à 48 MHz dans le but d’accélérer l’ensemble du système, étant donné qu’il implique de nombreuses communications nécessitant des opérations rapides, que ce soit pour la préparation des tampons de données ou les divers calculs.

FIGURE 29 – Configuration dans harmony

(a) Timer 1, Dimensionnement pour 1ms | (b) Timer 2, Dimensionnement pour 10ms

FIGURE 30 – Application timer développée par l’auteur

### 5.2.2 USART

Dans le but de vérifier les données de mesure en temps réel et de faciliter le débogage, une communication sérielle UART a été mise en place. Pour cela, le périphérique UART1, initialement prévu pour le slot mikroe, a été utilisé. Un module USB-to-TTL externe sera utilisé pour lire les données via Putty sur un ordinateur.


FIGURE 31 – Configuration UART

Nous pouvons constater sur la figure 31 que l’UART est configuré sans interruption à un bauderate de 115200.

### 5.2.3 Carte SD - SPI

L’utilisation du SPI a été optimisée en choisissant une fréquence de 5 MHz afin de réduire le temps d’exécution sur le microcontrôleur, compte tenu du grand nombre de trames nécessaires pour les opérations FAT. Cependant, j’ai rencontré un problème lié à la clock du SPI. En raison de la vitesse élevée et des modifications que j’ai dû apporter, la clock interfère inutilement avec le FTDI, et un fil relie SCK et U2TX, créant ainsi une inductance parasite. Pour résoudre ce problème, j’ai ajouté un condensateur de 33pF entre SCK et GND pour stabiliser la communication. Vous pouvez consulter la configuration Harmony de la carte SD sur la figure 32.

FIGURE 32 – Configuration du SPI

### 5.3 Code

Je vais dans cette section décrire le code du projet. Voici la hiérarchie des fichier du projet :

FIGURE 33 – Hiérarchie des fichiers du projet

### 5.3.1 Callbacks

Chacun des timers appelle dans leur interruption une fonction appartenant au fichier app.c, qui contient les actions définies pour chaque intervalle de temps spécifique. On peut visualiser cela sur le diagramme présenté dans la figure 34.


FIGURE 34 – Interactions des interruptions et des callbacks

Les callbacks en C offrent flexibilité, extensibilité et réutilisabilité. Ils permettent d’ajuster dynamiquement le comportement du programme, d’étendre les fonctionnalités et de réutiliser le code. Les callbacks favorisent également l’encapsulation et la personnalisation, améliorant ainsi la modularité et la maintenance du code.

### 5.3.2 Centrale inertielle BNO055

Pour ce qui est de la centrale inertielle BNO055, j’ai utilisé la bibliothèque de BOSCH ³ .
Je l’ai configurée en 32 bits et j’ai créé les fonctions de bas niveau (i2c) en établissant le lien avec la bibliothèque BOSCH. Tout cela a été fait dans le fichier BNO055_support.c.
Pour faire le lien entre la bibliothèque de haut niveau et la bibliothèque de bas niveau, j’ai utilisé un pointeur de fonction présent dans la structure de données du BNO, comme illustré dans le listing 1.

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

Listing 1 – Code lien pointeur de fonction

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

i 2 c _ s t a r t ( ) ;
BNO055_iERROR = i 2 c _ w r i t e ( de v _a d d r < <1) ;

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

i 2 c _ s t o p ( ) ;
i f ( BNO055_iERROR−1 != 0 ) BNO055_iERROR = −1;
e l s e
BNO055_iERROR = 0 ;
r e t u r n ( s 8 ) ( BNO055_iERROR ) ; }

Listing 2 – Code écriture i2c au BNO055

3. Bibliothèque du fabricant (https://github.com/BoschSensortec/BNO055_driver)

Pour ce qui est de l’utilisation de la libraire haut-niveau bno055_support, voici la préparation et la lecture des données :

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

Listing 3 – Code lecture des données par la librairie

### 5.3.3 Carte SD

La communication de la carte SD fonctionne sous forme d’une machine d’état non-bloquante, permettant ainsi de s’adapter aux situations de la carte sans bloquer le système pour autant.

FIGURE 35 – Machine d’état de la carte SD

Planification d’une écriture Afin de lancer une écriture d’un set de mesure sur la carte SD, il faut utiliser la fonction sd_BNO_scheduleWrite() qui vas préparer le buffer d’écriture et modifier l’état de la carte SD :

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

Listing 4 – Lancement d’une écriture sur la carte SD

Les données sont écrite dans un fichier .CSV nommé "MESURES". La forme de la trame est la suivante :

FIGURE 36 – Format de la trame

"%d;%d0;% f ;%. 4 f ;%. 4 f ;%. 4 f ;%. 4 f ;%. 4 f ;%. 4 f ;%. 4 f ;%. 4 f ;%. 4 f ;%. 4 f ;%. 4 f ;%. 4 f ;%. 4 f ;%. 4 f ;%. 4 f ;%d;%d;%d;%d ; "

Listing 5 – Ecriture du buffer

Exemple trame CSV : 0;372;1.025;-0.2500;0.3800;9.7900;-0.1250;0.1250;-0.0625;-44.8750;35.0625;-7.2500;0.0000;-0.0100;-0.2700;0.0000;-2.1875;-1.5000;16379;320;216;-1;

### 5.3.4 Application main

On peut visualiser la machine d’état de l’application principale sur la figure 37.

FIGURE 37 – Machine d’état application

Fonctionnement APP_STATE_LOGGING : Une fois que l’application est en mode logging, le fonctionnement est décris sur la figure 38 sous forme de flowchart.


FIGURE 38 – Fowchart state logging

## 6 Validation du design

Lors de cette section, sera décrite la procédure de vérification des caractéristiques du projet ainsi que sa validation.

### 6.1 Liste de matériel

1. Oscilloscope Tektronix RTB2004 ES.SLO2.05.01.16
2. Analyseur logique USB, 8 canaux, 24 MHz
3. USB vers TTL HW-597
4. Carte Localisation-Sous-Marine V0.0

### 6.2 Contrôle des alimentations

En premier lieu, une vérification des tensions d’alimentation permet de valider un aspect critique et fondamental de la carte.

### 6.2.1 Méthodologie

Mesure du 3.3V : Alimentation de la carte par une connexion brève entre les pins du connecteur du bouton P15. Mesure sur le testpoint V_regOUT5, voir figure 39.

FIGURE 39 – Testpoint mesure 3.3V

Mesure du 5V : Pour mesurer le 5V, il faut ponter par une résistance de 0Ω la résistance R50, ainsi que activer la Pin RC5 / EN_5V. Ensuite, la mesure a été prise sur le connecteur P16, pin-3, avec l’oscilloscope (Numéro 1 de la liste de matériel 6.1) :

FIGURE 40 – Schéma de mesure 5V

(a) Mesure 3.3V | (b) Mesure 5V

FIGURE 41 – Mesures des tensions d’alimentation

### 6.2.2 Mesures

Analyse : Nous pouvons observer les valeurs respectives des tensions sur les figures 41a et 41b. La tension d’alimentation du microcontrôleur est mesurée à 3.125V, ce qui peut être expliqué par une chute de tension aux bornes de la batterie LI-ION qui nécessite donc d’être chargée. La tension 3.3V oscille légèrement, ce qui peut s’expliquer par le fait qu’il s’agit de l’alimentation principale de la carte avec le plus de consommateurs. Mais également par le fait que des signaux rapides sont générés par le microcontrôleur et ses différents périphériques. La tension d’alimentation du capteur de pression, dont la tension dimensionnée est de 5V, est quant à elle mesurée à 5.0295V, ce qui signifie une bonne précision de la part du circuit de boost. On peut également voir que la tension n’oscille pas et ne va donc pas perturber le capteur de pression.
Nous pouvons donc confirmer le fonctionnement des blocs d’alimentation du projet.

### 6.3 Communication UART

Comme décrit lors de la sous-section 5.2.2, une communication série est implémentée dans le projet. Cette communication n’est pas critique pour le projet, mais il est important de vérifier son fonctionnement pour d’éventuelles versions ultérieures.

### 6.3.1 Méthodologie

Pour la mesure, l’analyseur logique (Numéro 2 de la liste de matériel 6.1) a été utilisé. Les trames U1TX et U1RX ont été mesurées sur le connecteur P4 :

FIGURE 42 – Schéma de mesure UART1

### 6.3.2 Mesures

FIGURE 43 – Mesures trames UART

Nous pouvons lire des caractères ASCII sur la trame de la figure 43, qui reflètent le message envoyé contenant les mesures.
En connectant le module USB-TO-TTL (Numéro 3 de la liste de matériel 6.1) aux broches Tx et Rx de la figure 43, puis en ouvrant une communication série via PuTTY à une baudrate de 115200, nous obtenons la communication de la figure 44 dans la console :


FIGURE 44 – Réception UART sur PuTTY

Analyse de la réception : Sur la figure 44, on peut visualiser les données de la centrale inertielle, le temps écoulé entre chaque mesure, ainsi que les données du capteur de pression. Nous pouvons observer qu’entre chaque mesure, il s’écoule un laps de temps de 60ms, ce qui est plus rapide que les spécifications demandées par le cahier des charges. La mesure du capteur de pression à −1.236 bar n’est pas cohérente, car le capteur de pression n’était pas connecté au moment des mesures. Nous pouvons également constater que les mesures de la centrale inertielle sont cohérentes selon les données typiques d’une centrale inertielle ⁴
4. Exemple de données de fusion d’une centrale inertielle [4]

### 6.4 Communication SPI, carte SD

Il reste maintenant un élément critique à valider : la communication SPI avec la carte SD. Cette communication permet le logging des valeurs de mesure et est donc un aspect essentiel du projet.

### 6.4.1 Méthodologie

Pour cette mesure j’ai mesuré les signaux (SCK, SDO1, SDI1, CS_SD) du SPI avec l’analyseur logique (Numéro 2 de la liste de matériel 6.1).

FIGURE 45 – Schéma de mesure carte SD

### 6.4.2 Mesures

FIGURE 46 – Vue d’ensemble de la communication SPI

Comme le montre la figure 46, on peut constater que les trames SPI utilisées pour la gestion de la FAT sont nombreuses. C’est pourquoi il est important d’avoir une fréquence élevée afin d’optimiser le temps des échanges de données.
Nous allons maintenant mesurer le temps entre deux écritures sur la carte SD afin de vérifier le temps écoulé entre les mesures. et l’écriture.


FIGURE 47 – Temps entre deux écritures sur la carte SD

Nous pouvons observer sur la figure 47 que le temps mesuré entre une première écriture et le début de la suivante est de 89.804ms. Le temps disponible entre deux écritures est d’environ ∼ 6ms. Nous pouvons donc constater l’importance d’une vitesse élevée sur la communication SPI et sur le microcontrôleur.
Avec une fréquence d’horloge de 48MHz, on peut donc déduire :

Nop = Tdispo ∗Fsys = 6 ∗ 10⁻³

∗ 48 ∗ 10⁶ = 288⁰
000 | (7)
D’après le calcul 7 nous savons que le MCU peut effectuer 288⁰000 cycles machines durant ce temps disponible. Nous considérons ce nombre d’opérations suffisants au système, sachant qu’il n’y a pas beaucoup d’autre opérations. Cet élément est à prendre en compte en cas d’ajout de fonctionnalité dans le système.

Mesure début de trame : Sur la figure 48 nous pouvons observer à quoi ressemble un début de trame sur la carte SD pour système FAT.

FIGURE 48 – Mesure début de trame

## 7 Caractéristiques du produit fini

Caractéristique | Attribut | Valeur alternative
Axes de mesures | 9 | -
Mesures | [ms][bar][°/s][uT][Euler][Quaternion][°C]
Temps entre mesures | 90 [ms] | 11.11 Hz
Nombre de mesures max | 1.641 M | -
Capacité carte SD | 256 [MB] | -
Pression maximum | 10 [bars] | 145 PSI
Autonomie | ∼ 20 [h] | 72⁰ 000 [s]
Batterie | 3400 [mAh] | 11.22 [W h]
Profondeur | 101.97 [mH2O] | -
Précision pression | 0.15 [%] | -
Slot Mikroe | 1 [−] | -
Vitesse MCU | 48 [MHz] | -
Interface | LED RGB | -
Communications | I2C, SPI, UART, USB | -
Vitesse SPI | 5 [MHz] | -
Vitesse UART | 115200 [Bd] | -
Mise en évidence mesure | Oui | -
Compensation température | Oui | -

TABLE 3 – Caractéristiques du projet V0.0

On peut voir sur le tableau 3 les caractéristiques issues du développement final du projet dans sa version 0.0. Un test de logging de 5 heures a été effectué sans difficulté et a récolté 30 MB de données dans le fichier CSV, ce qui correspond effectivement aux caractéristiques du tableau 3.

## 8 Conclusion

Synthèse Le présent rapport a décrit le développement et la validation d’un projet de localisation sous-marine. L’objectif principal du projet était de concevoir et de mettre en oeuvre un système capable de collecter et de stocker des données de déplacement, de temps et de pression lors de plongées. Après avoir réalisé les différentes étapes de développement, nous pouvons conclure que le projet a été mené à une version finie.

Développement Au cours de la phase de développement, plusieurs étapes clés ont été franchies. Tout d’abord, une analyse approfondie des besoins et des contraintes a été réalisée, ce qui a permis de définir les spécifications du système. Ensuite, un processus itératif de conception a été suivi, comprenant la sélection des composants appropriés, la création des schémas électroniques, et la fabrication du prototype.

Design L’évaluation du design du projet a été effectuée en suivant une méthodologie rigoureuse de vérification et de validation. Les principales caractéristiques du projet, telles que les tensions d’alimentation, la communication UART et la communication SPI avec la carte SD, ont été vérifiées avec succès. Les mesures effectuées ont montré que le système fonctionnait correctement et répondait aux spécifications requises.

Test Le projet a été testé avec succès lors d’un enregistrement de données de déplacement pendant une durée de 5 heures, ce qui a permis de collecter 30 MB de données. Ces résultats confirment que le système est capable de fonctionner de manière fiable et de fournir les fonctionnalités attendues.

Apports Ce projet a permis d’acquérir une expérience précieuse dans le domaine de la conception et du développement de systèmes électroniques. Il a également mis en évidence l’importance de l’organisation, de la structure et de la vérification étape par étape des éléments du design.

Correctifs Afin de simplifier la mise en place du système, des correctifs mentionnés dans le fichier MODIF (Section 10.1) permettrait de palier a certaines erreurs non-critiques de développements.

Améliorations Des améliorations et des développements futurs peuvent être envisagés, tels que l’ajout de fonctionnalités supplémentaires, l’optimisation de la communication, l’extension des capacités de stockage ainsi que la mise en place d’une communication USB directement par le FTDI en corrigeant le pinning de SCK. Ces évolutions permettraient d’explorer de nouvelles possibilités d’application de ce système de localisation sous-marine.

Remerciements Je tiens à remercier sincèrement M. Juan José Moreno, mon responsable de projet, Dr. Gaston Baudat pour avoir mandaté le projet et pour sa contribution algorithmique sur la localisation, et M. Fréderic Mueller pour son aide mécanique et pour la conception de la rallonge du module. Leur soutien et leur expertise ont été essentiels pour mener à bien ce projet. Je suis reconnaissant de leur précieuse collaboration et de leurs conseils tout au long du processus.

## 9 Bibliographie

## Références

[1] A. Bradley, M. Feezor, H. Singh, and F. Yates Sorrell, “Power systems for autonomous underwater vehicles,” vol. 26, no. 4, pp. 526–538. Conference Name : IEEE Journal of Oceanic Engineering.
[2] N. Shaukat, A. Ali, M. Javed Iqbal, M. Moinuddin, and P. Otero, “Multi-sensor fusion for underwater vehicle localization by augmentation of RBF neural network and error-state kalman filter,” vol. 21, no. 4, p. 1149. Number : 4 Publisher : Multidisciplinary Digital Publishing Institute.
[3] A. S. Zaki, T. B. Straw, M. J. Obara, and P. A. Child, “High accuracy heading sensor for an underwater towed array.”
[4] M. Rozbicka-Goodheart, “Estimation of object orientation using sensor fusion and vhdl,” 2021.

## 10 Annexes


FIGURE 49 – Illustation annexes Source : https://www.alamyimages.fr/photo-image-vecteur-icone-annexe-175637003.html

ECOLE SUPERIEURE | ELCO – SLO
JMO – Nov 2018 | 2221_LocalisationSousMarine-MOD-v1.docx | Page 1

# Projet ETML-ES – Modification

PROJET: | 2221 Localisation sous-marine
Entreprise/Client: | Gaston Baudat | Département: | SLO
Demandé par (Prénom, Nom): | Juan José Moreno | Date: | 17.06.2023
Objet (No ou réf, pièce, PCB...) | 2221
Version à modifier: | V0.0
Auteur (ETML-ES): | Ali Zoubir | Filière: | SLO
Nouvelle version: | V0.0 | Date: | 05.12.2018

### 1 Description ou justification

Des correctifs sont à faire pour perfectionner le fonctionnement du projet, notamment permettre une communication USB directe et simplifier certains éléments.

### 2 Référence conception

K:\ES\PROJETS\SLO\2221_LocalisationSousMarine

https://github.com/Ali-Z0/2221_LocalisationSousMarine.git

### 3 Détail des modifications

# | Description | Fait | Approuvé

1 | Changer les pins U2TX et SCK (SCK valable que sur la pin 14 au-lieu de 29) | Non
2 Oscillateur externe doit être connecté comme oscillateur secondaire et non | principale | Non
3 | Revoir système multiplexeur pour chips select (polarité cs de la carte sd diffèrent) | Non

### 4 Remarques

Les modifications ci-dessus sont à faire pour une version ultérieure du projet.

### 10.1 Fichier de modifs

Ali Zoubir
TECHNICIEN-NE ES EN GÉNIE ÉLECTRIQUE / 2022-2023

www.etml-es.ch

rue de Sébeillon 12, 1004 Lausanne | ETML

2221 Localisation Sous-Marine

L’objectif de ce projet, et de stocker des données de mesures du déplacement d’un module sous-marin par une centrale inertielle, dans le but de mathématiquement le localiser depuis son point de départ (référence). Ceci, car la localisation sous-marine n’est pas une tâche aisée due aux différentes contraintes de communication sous-marine notamment le fait que les ondes électromagnétiques ne s’y propagent pas facilement.

Un processus itératif de conception a été suivi, comprenant la sélection des composants appropriés, la création des schémas électroniques, et la fabrication du prototype. L’évaluation du design du projet a été effectuée en suivant une méthodologie rigoureuse de vérification et de validation. Les principales caractéristiques du projet, ont été vérifiées avec succès. Les mesures effectuées ont montré que le système fonctionnait correctement et répondait aux spécifications requises.
Des améliorations et des développements futurs peuvent être envisagés, tels que l’ajout de fonctionnalités supplémentaires, l’optimisation de la communication, l’extension des capacités de stockage ainsi que la mise en place d’une communication USB directement par le FTDI implémenté. Ces évolutions permettraient d’explorer de nouvelles possibilités d’application de ce système de localisation sous-marine.

### 10.2 Affiche du projet

ETML⁻ES

Ecole supérieure, école des métiers Lausanne
Rue de Sébeillon 12
CH-1004 Lausanne
www.etml-es.ch | | 1 / 1 |
RESUMÉ – Projet | Ali Zoubir SLO 2 2022-2023

Titre :
2221 Localisation Sous-Marine

Contexte et objectifs :

L’objectif de ce projet, et de stocker des données de mesures du déplacement d’un module sous-marin par une centrale inertielle, dans le but de mathématiquement le localiser depuis son point de départ (référence). Ceci, car la localisation sous-marine n’est pas une tâche aisée due aux différentes contraintes de communication sous-marine notamment le fait que les ondes électromagnétiques ne s’y propagent pas facilement.

Résultats obtenus et conclusion :

Objectif : Concevoir et mettre en œuvre un système de collecte et de stockage de données de déplacement, de temps et de pression lors de plongées.

Développement : Analyse approfondie des besoins et des contraintes, définition des spécifications du système, conception itérative, sélection des composants appropriés, création des schémas électroniques et fabrication du prototype.
Design : Évaluation rigoureuse du design avec succès, vérification des principales caractéristiques telles que les tensions d'alimentation et les communications UART et SPI avec la carte SD.

Test : Enregistrement réussi de données de déplacement pendant 5 heures, collecte de 30 Mo de données, confirmant la fiabilité et les fonctionnalités du système.

Apports : Acquisition d'une précieuse expérience en conception et développement de systèmes électroniques, soulignant l'importance de l'organisation et de la vérification étape par étape.

Correctifs : Mise en place de correctifs pour simplifier l'installation du système et résoudre certaines erreurs non critiques de développement.
Améliorations futures : Ajout de fonctionnalités supplémentaires, optimisation de la communication, extension des capacités de stockage et mise en place d'une communication USB directe par le FTDI en corrigeant le pinning de SCK pour explorer de nouvelles possibilités d'application.
Maître(s) de projet : | Juan José Moreno
Entreprise mandataire : | Gaston Baudat

### 10.3 Résumé

### 10.4 Mode d’emploi

1. Insérer la carte SD format FAT.
2. Allumer le système avec une impulsion sur le bouton.
Si la LED clignote en vert, le logging est en cours.
Si la LED s’allume en rouge, il y a une erreur (Vérifier carte SD ou relancer système).
3. Presser brièvement sur le bouton pour mettre la prochaine mesure en importance haute (1 dans CSV).
4. Une fois le logging terminé, maintenir le bouton plus de 5 secondes pour éteindre le système.

Notes Il est conseillé de bien éteindre le système par le bouton, pour ne pas mettre en danger l’intégrité de la carte SD.

5. Retirer la carte SD.
6. Insérer la carte SD sur un ordinateur avec un adaptateur.
7. Récupérer le fichier MESURES.CSV.
8. Recommencer le cycle.

dif.; SDA1 SCL1; BAT_STAT; RST_IMU INT_IMU; PWR_HOLD; SDA2 SCL2; U1TX U1CTS U1RTS U1RX; MISO; MOSI; SCK; Button_MF; BAT_LVL; BAT_READ; RST_MB1 RST_MB2 RST_MB3; ENABLE_5V; USB_5V; LED_R LED_G LED_B; U2TX U2CTS U2RTS U2RX; AN_PRESS; U_MCU MCU.SchDoc; U_Interface Interface.SchDoc; BAT_READ BAT_LVL ENABLE_5V; U_Power Power.SchDoc; SDA1 SCL1 RST_IMU INT_IMU; SCL2; SDA2; SCK MOSI MISO; U_Peripherals Peripherals.SchDoc; PIR101; PIR102; COR1; PIR201; PIR202; COR2; PIR301; PIR302; COR3; PIR401; PIR402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

ETML-ES 16 juin 2023 Localisation sous-marine V0.0

SchemaBloc.SchDoc Fichier : | | a

Date : 08.02.2023 | Version : V0

Heure : 14:08:45 | Auteur : Ali Zoubir
Avenue Recordon 1 1004 Lausanne Switzerland | Projet : 2221_LocalisationSousMarine.PrjPcb | No : 2221

Nb feuilles 6 | Feuille n° 1

Chemin : C:\Users\alizoubir\Documents\ETML-ES-2eme\PROJ\2221_LocalisationSousMarine\hard\2221_LocalisationSousMarine\Schematic\SchemaBloc.SchDoc


MCU.SchDoc Fichier : | | a

Date : 08.02.2023 | Version : V0

Heure : 14:08:45 | Auteur : Ali Zoubir
Avenue Recordon 1 1004 Lausanne Switzerland | Projet : 2221_LocalisationSousMarine.PrjPcb | No : 2221

Nb feuilles 6 | Feuille n° 2

Chemin : C:\Users\alizoubir\Documents\ETML-ES-2eme\PROJ\2221_LocalisationSousMarine\hard\2221_LocalisationSousMarine\Schematic\MCU.SchDoc


Interface.SchDoc Fichier : | | a

Date : 08.02.2023 | Version : V0

Heure : 14:08:45 | Auteur : Ali Zoubir
Avenue Recordon 1 1004 Lausanne Switzerland | Projet : 2221_LocalisationSousMarine.PrjPcb | No : 2221

Nb feuilles 6 | Feuille n° 4

Chemin : C:\Users\alizoubir\Documents\ETML-ES-2eme\PROJ\2221_LocalisationSousMarine\hard\2221_LocalisationSousMarine\Schematic\Interface.SchDoc


La pin 1 est utilisée dans le cas
d'un capteur à sortie analogique
(Courant ou tension) :

Sortie analogique capteur de pression

Peripherals.SchDoc Fichier : | | a

Date : 08.02.2023 | Version : V0

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

Nb feuilles 6 | Feuille n° 5

Chemin : C:\Users\alizoubir\Documents\ETML-ES-2eme\PROJ\2221_LocalisationSousMarine\hard\2221_LocalisationSousMarine\Schematic\Peripherals.SchDoc


Power.SchDoc Fichier : | | a

Date : 08.02.2023 | Version : V0

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

Nb feuilles 6 | Feuille n° 6

Chemin : C:\Users\alizoubir\Documents\ETML-ES-2eme\PROJ\2221_LocalisationSousMarine\hard\2221_LocalisationSousMarine\Schematic\Power.SchDoc

Comment | Description | Designator | Footprint | LibRef | Quantity
0.1uF | Capacitor | C1 | 6-0805_L | Cap | 1
10nF | Capacitor | C2, C5 | 6-0805_L | Cap | 2
47pF | Capacitor | C3, C4 | 6-0805_L | Cap | 2
4.7u | | C6, C16 | 6-0805_L | C | 2
100n | | C7, C8, C9, C10, C11, C13, C14, C15 | 6-0805_L | C | 8
10uF | | C12 | 6-0805_L | C | 1
4.7uF, 35V | Multilayer Ceramic Capacitors 4.7μF ±10% 35V X7R SMD 0805 | C17, C19 | 6-0805_L | CMP-08246-002735-1 | 2
10uF, 10V | CAP CER 10UF 10V X5R 0805 | C18 | 6-0805_L | CMP-2007-03243-2 | 1
6.8uF, 10V | Cap Ceramic 6.8uF 10V X5R 20% Pad SMD 0805 +85°C Automotive T/R | C20 | 6-0805_L | CMP-08246-000118-1 | 1
C0805C106K8PACT U | CAP CER 10UF 10V X5R 0805 | C21 | FP-C0805C-DG-MFG | CMP-2007-03243-2 | 1
GRM21BR61A226 ME44L | Chip Multilayer Ceramic Capacitors for General Purpose, 0805, 22uF, X5R, 15%, 20%, 10V | C22 | FP-GRM21B-0_2-e0_2_0_7-IPC_C | CMP-06035-039918-1 | 1
CLP6C-FKB-CK1P1G1BB7R3R3 | LED RGB DIFFUSED 6PLCC SMD | D1 | FP-CLP6C-FKB-CK1P1G1BB7R3-MFG | CMP-13977-000020-2 | 1
BAS40 | | D2, D3 | BAS40 | BAS40_0 | 2
Super Red, 1.9 V | SMT Mono-color Chip LED Waterclear WL-SMCW, size 0805, Super Red, 1.9 V, 140 deg, 60mcd | D4, D5, D6 | WL-SMCW_0805 | 150080SS75000 | 3
5011 | Test Point, Black, Through Hole, RoHS, Bulk | GND1, GND2, GND3, GND4 | KSTN-5011_V | CMP-1672-00003-4 | 4
1043P | BATT HOLDER 18650 1 CELL PC PIN | J1 | FP-1043P-MFG | CMP-19636-000034-1 | 1
BNO055-ADAFRUIT | | K1 | | BNO055-ADAFRUIT | 1
742792133 | SMD EMI Suppression Ferrite Bead WE-CBF, Z = 600Ohm | L1 | SMD-1206 | CMP-0220-00010-1 | 1
SRN6045-1R0Y | FIXED IND 1UH 4.2A 13.9 MOHM SMD | L2 | FP-SRN6045-MFG | CMP-07248-000038-1 | 1
M3, Length 5mm | WA-SMSI SMT Steel Spacer, M3 Thread Internal, Length 5mm | MP1, MP2, MP3, MP4, MP5 | troueAbraser | 9774050360 | 5
Header 6 | Header, 6-Pin | P1 | HDR1X6 | Header 6 | 1
Header 4 | Header, 4-Pin | P2, P3, P5 | HDR1X4 | Header 4 | 3
Header 7 | Header, 7-Pin | P4 | HDR1X7 | Header 7 | 1
Header 2 | Header, 2-Pin | P6, P11 | HDR1X2 | Header 2 | 2
Header 5 | Header, 5-Pin | P7 | HDR1X5 | Header 5 | 1
Header 3 | Header, 3-Pin | P8, P9, P10 | HDR1X3 | Header 3 | 3
BSS138LT1G | Power MOSFET, 200mA, 50 V, N-Channel, 3-Pin SOT-23, Pb-Free, Tape and Reel | Q1, Q2, Q3, Q5, Q7, Q8 | ONSC-SOT-23-3-318-08_V | CMP-1058-00767-1 | 6
NVR1P02T1G | Power MOSFET, -20 V, -1 A, P-Channel, 3-Pin SOT-23, Pb-Free, Tape and Reel | Q4, Q6, Q9 | ONSC-SOT-23-3-318-08_V | CMP-1058-00745-1 | 3
| Resistor | R1, R2, R3, R4 | AXIAL-0.4 | Res2 | 4
Res2 | Resistor | R5, R6, R7, R8, R9, R10, R11, R12, R13, R14, R15, R16, R17, R18, R19, R25, R26, R27, R44 | 6-0805_L | Res2 | 19
47k | | R20 | 6-0805_L | R | 1
10k | | R21, R22, R23, R24, R31, R34, R41, R43, R46, R47, R49 | 6-0805_L | R, CMP-2001-04376-1, CMP-2001-00410-1 | 11
270R | | R28, R29, R30, R38 | 6-0805_L | CMP-2001-00528-1 | 4
6.2k | | R32, R40 | 6-0805_L | CMP-2001-04031-1, CMP-2001-00562-1 | 2
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

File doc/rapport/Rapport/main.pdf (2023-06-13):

# Localisation sous-marine

# Système de logging pour déplacement de module

sous-marin.

# Ali Zoubir

# Rapport de projet

# Génie électrique École supérieure Suisse 13 juin 2023

PROJET 2221 | 13 juin 2023 | LocalisationSousMarine

## Table des matières

1 Caractéristiques du projet | | 3
2 Pré-étude | 7
3 Développement schématique | 16
4 Développement du PCB | 28

ETML-ES | 13 juin 2023 | Localisation sous-marine V0.0

# Localisation sous-marine

2022, V0.0

## 1 Caractéristiques du projet

1.1 Description
L’objectif de ce projet, et de stocker des données de mesures du déplacement d’un module sous-marin par une centrale inertielle, dans le but de mathématiquement le localiser depuis son point de départ (référence). Ceci, car la localisation sous-marine n’est pas une tâche aisée due aux différentes contraintes de communication sous-marine notamment que les ondes électromagnétiques ne se propagent pas facilement.
1.2 Aperçu
— Sauvegarde d’un set de donnée chaque 100ms.
— Profondeur d’utilisation maximum, de 60m.
— 2 heure de logging dans carte SD.
— Sensing sur 9 axes :
Mesures [Il est souhaitable que les capteurs choisis aient une faible dérive] ; Accéléromètre 3-axes.
Gyroscope 3-axes.
Magnétomètre 3-axes.
Senseur de température
Profondimètre [0->10bar] [Res 1/10]
3 à 5 slots libres MikroE pour autres mesures.
— Possibilité de sauvegarder la localisation de points d’intérêts par :
Bouton de sauvegarde [A définir : Magnétique, Optique, Mécanique ou autre]. — Batterie, autonomie minimum de 2 heures [∼10◦C].
— Charge de la batterie par connecteur USB.
— (Optionnel) Lecture des données par connecteur USB (Interfaçage électronique, software optionnel dans cette version).
— (Optionnel) Interface LED ou petit écran.

1.3 Tâches à réaliser
Développement et intégration d’un PCB avec capteurs et logging sur carte SD dans une lampe de plongée étanche.
- Développement schématique
- Fonctionnement MCU.
- Périphériques de mesures et de sauvegarde / Bus de communication.
- Gestion batterie
- Routage pour intégration dans boitier de lampe de plongée 200x45mm.
- Programmation mesure et sauvegarde chaque 100ms.
- Configuration MCU.
- Configuration des périphériques de mesure pour 9-DOF.
- Configuration des périphériques de sauvegarde (Carte SD).
- Configuration et communication avec l’interface.
- Communication et traitement des données mesurées.


Figure 1 – Schéma de principe Source : Auteur

1.4 Description des blocs
1. Carte SD :
Stockage des données de mesures chaque 100ms, cœur du projet.
2. Accéléromètre-gyroscope-magnétomètre :
Lecture des données individuelles brute ainsi que de fusion des capteurs, pour mesurer les déplacements sur 9 degrés de libertés.
3. Profondimètre :
Mesure la pression pour déduire la profondeur, afin de corroborer les autres mesures des capteurs.
4. Real time clock :
Permet de sauvegarder la temporalité du set de mesure dans la carte SD.
5. Affichage :
Affichage LED ou écran, pour affichage pas encore définis (ex. Profondeur, état batterie…)
6. Bouton sauvegarde :
Permet la mise en valeur d’un set de mesure. La forme de ce bouton n’est pas encore définie. Il sera peut-être fusionné avec le bouton ON/OFF.
7. Bouton ON/OFF :
Permet d’allumer ou d’éteindre le système.
8. Batterie :
Batterie du système, technologie à définir dans la pré-étude.
9. COM. USB :
Permet de charger les batteries. Il faudra également prévoir dans cette version l’interface électronique pour la lecture de la carte SD directement par le port USB.
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

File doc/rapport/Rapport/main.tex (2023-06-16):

% !TeX root = main.tex
% !TeX spellcheck = fr_FR
\documentclass[12pt,a4paper,twoside]{article}
\usepackage[scaled]{helvet}
% Packages and macros
\usepackage[T1]{fontenc}
%\usepackage[utf8]{inputenc}
\usepackage{mathptmx}
\usepackage{pgf}
\usepackage{pgfpages}
\usepackage{parallel}
\usepackage{siunitx}
\usepackage{booktabs}
\usepackage{fancyhdr}
\usepackage{datetime}
\usepackage{multicol}
\usepackage{enumerate}
\usepackage{pifont}
\usepackage{amssymb}
\usepackage[export]{adjustbox}
\usepackage[margin=1in]{geometry}
\usepackage[french]{babel}
\usepackage{caption}
\usepackage{tikz}
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

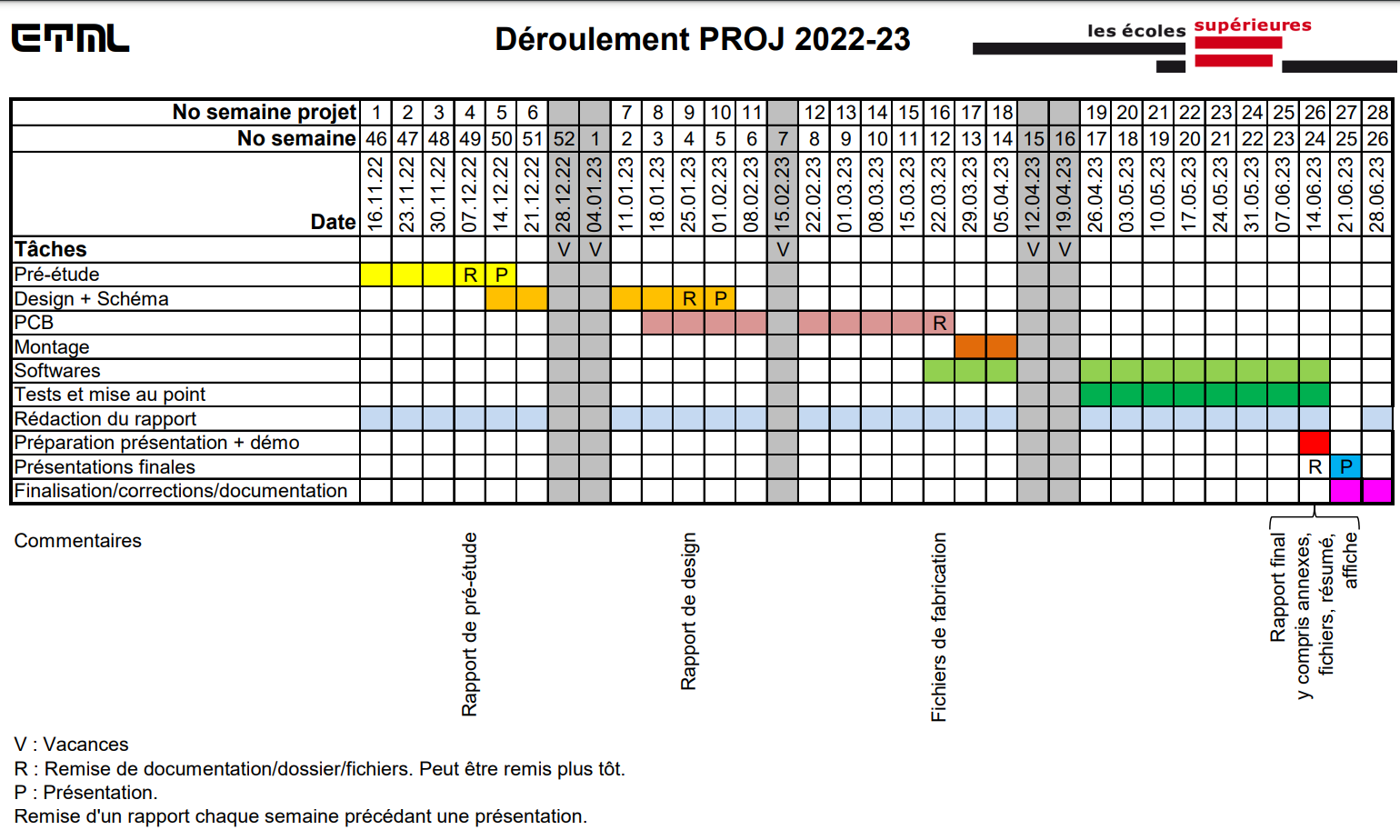
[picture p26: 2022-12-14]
doc/rapport/CDC/Figures/Tab-Jalons-PROJ.PNG

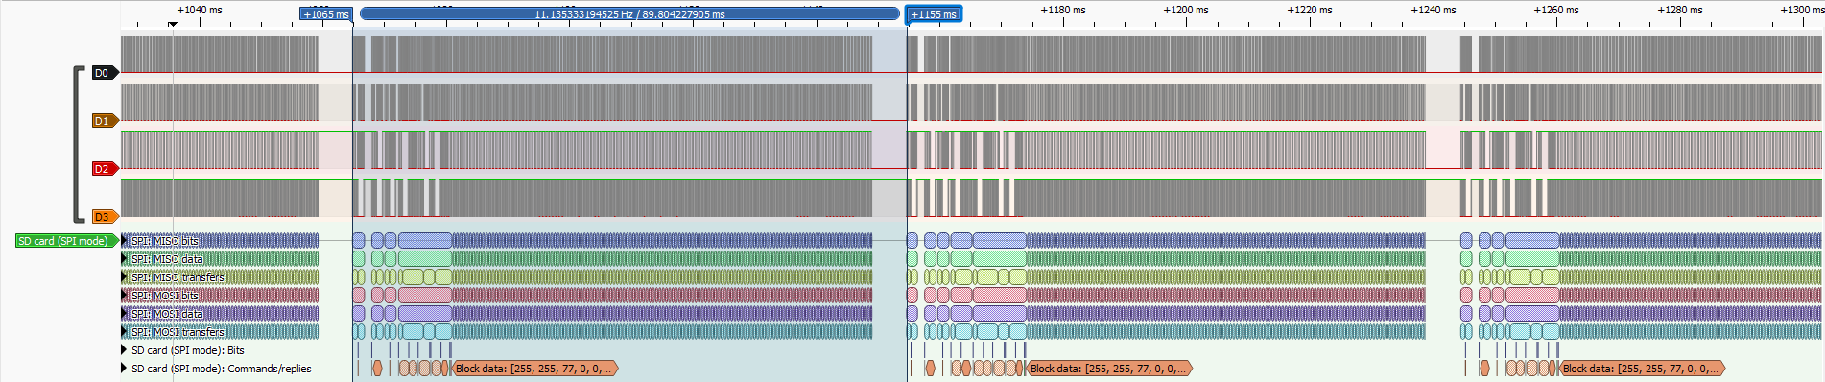
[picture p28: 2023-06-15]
doc/rapport/Rapport/Mesures/SPI_SD_TempreEntre2Comms.png

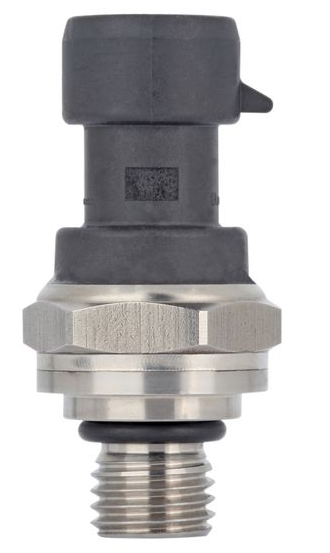
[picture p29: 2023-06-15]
doc/rapport/Rapport/Figures/Capteur-pression_2.PNG

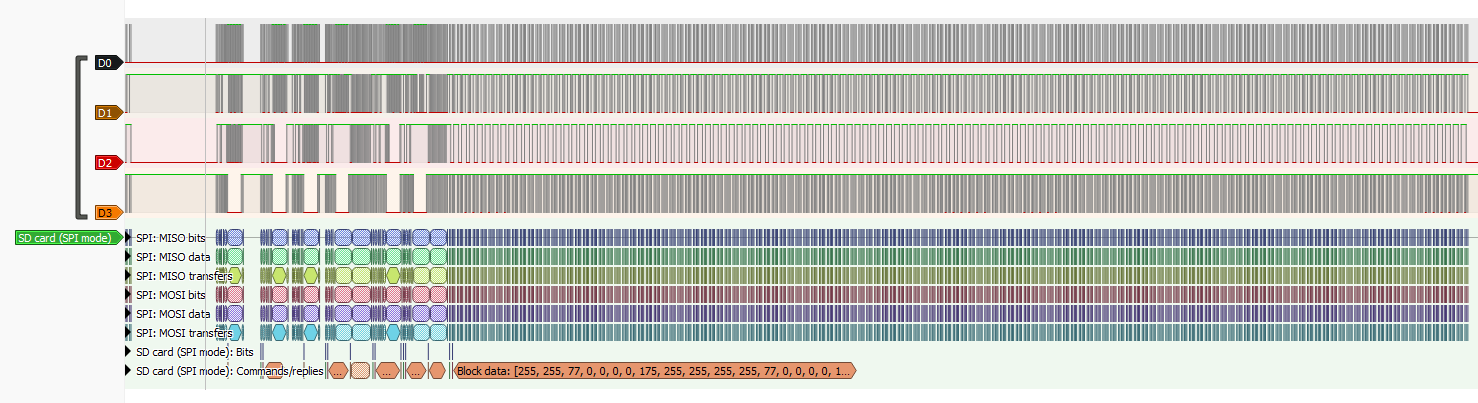
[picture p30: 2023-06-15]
doc/rapport/Rapport/Mesures/SPI_SD_CommEnsemble.png

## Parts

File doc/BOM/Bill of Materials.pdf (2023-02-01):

Comment | Description | Designator | Footprint | LibRef | Quantity
0.1uF | Capacitor | C1 | 6-0805_L | Cap | 1
10nF | Capacitor | C2, C5 | 6-0805_L | Cap | 2
47pF | Capacitor | C3, C4 | 6-0805_L | Cap | 2
4.7u | | C6, C16 | 6-0805_L | C | 2
100n | | C7, C8, C9, C10, C11, C13, C14, C15 | 6-0805_L | C | 8
10uF | | C12 | 6-0805_L | C | 1
4.7uF, 35V | Multilayer Ceramic Capacitors 4.7μF ±10% 35V X7R SMD 0805 | C17, C19 | 6-0805_L | CMP-08246-002735-1 | 2
10uF, 10V | CAP CER 10UF 10V X5R 0805 | C18 | 6-0805_L | CMP-2007-03243-2 | 1
6.8uF, 10V | Cap Ceramic 6.8uF 10V X5R 20% Pad SMD 0805 +85°C Automotive T/R | C20 | 6-0805_L | CMP-08246-000118-1 | 1
C0805C106K8PACT U | CAP CER 10UF 10V X5R 0805 | C21 | FP-C0805C-DG-MFG | CMP-2007-03243-2 | 1
GRM21BR61A226 ME44L | Chip Multilayer Ceramic Capacitors for General Purpose, 0805, 22uF, X5R, 15%, 20%, 10V | C22 | FP-GRM21B-0_2-e0_2_0_7-IPC_C | CMP-06035-039918-1 | 1
CLP6C-FKB-CK1P1G1BB7R3R3 | LED RGB DIFFUSED 6PLCC SMD | D1 | FP-CLP6C-FKB-CK1P1G1BB7R3-MFG | CMP-13977-000020-2 | 1
BAS40 | | D2, D3 | BAS40 | BAS40_0 | 2
Super Red, 1.9 V | SMT Mono-color Chip LED Waterclear WL-SMCW, size 0805, Super Red, 1.9 V, 140 deg, 60mcd | D4, D5, D6 | WL-SMCW_0805 | 150080SS75000 | 3
5011 | Test Point, Black, Through Hole, RoHS, Bulk | GND1, GND2, GND3, GND4 | KSTN-5011_V | CMP-1672-00003-4 | 4
1043P | BATT HOLDER 18650 1 CELL PC PIN | J1 | FP-1043P-MFG | CMP-19636-000034-1 | 1
BNO055-ADAFRUIT | | K1 | | BNO055-ADAFRUIT | 1
742792133 | SMD EMI Suppression Ferrite Bead WE-CBF, Z = 600Ohm | L1 | SMD-1206 | CMP-0220-00010-1 | 1
SRN6045-1R0Y | FIXED IND 1UH 4.2A 13.9 MOHM SMD | L2 | FP-SRN6045-MFG | CMP-07248-000038-1 | 1
M3, Length 5mm | WA-SMSI SMT Steel Spacer, M3 Thread Internal, Length 5mm | MP1, MP2, MP3, MP4, MP5 | troueAbraser | 9774050360 | 5
Header 6 | Header, 6-Pin | P1 | HDR1X6 | Header 6 | 1
Header 4 | Header, 4-Pin | P2, P3, P5 | HDR1X4 | Header 4 | 3
Header 7 | Header, 7-Pin | P4 | HDR1X7 | Header 7 | 1
Header 2 | Header, 2-Pin | P6, P11 | HDR1X2 | Header 2 | 2
Header 5 | Header, 5-Pin | P7 | HDR1X5 | Header 5 | 1
Header 3 | Header, 3-Pin | P8, P9, P10 | HDR1X3 | Header 3 | 3
BSS138LT1G | Power MOSFET, 200mA, 50 V, N-Channel, 3-Pin SOT-23, Pb-Free, Tape and Reel | Q1, Q2, Q3, Q5, Q7, Q8 | ONSC-SOT-23-3-318-08_V | CMP-1058-00767-1 | 6
NVR1P02T1G | Power MOSFET, -20 V, -1 A, P-Channel, 3-Pin SOT-23, Pb-Free, Tape and Reel | Q4, Q6, Q9 | ONSC-SOT-23-3-318-08_V | CMP-1058-00745-1 | 3
| Resistor | R1, R2, R3, R4 | AXIAL-0.4 | Res2 | 4
Res2 | Resistor | R5, R6, R7, R8, R9, R10, R11, R12, R13, R14, R15, R16, R17, R18, R19, R25, R26, R27, R44 | 6-0805_L | Res2 | 19
47k | | R20 | 6-0805_L | R | 1
10k | | R21, R22, R23, R24, R31, R34, R41, R43, R46, R47, R49 | 6-0805_L | R, CMP-2001-04376-1, CMP-2001-00410-1 | 11
270R | | R28, R29, R30, R38 6-0805_L | | CMP-2001-00528-1 | 4
6.2k | | R32, R40 | 6-0805_L | CMP-2001-04031-1, CMP-2001-00562-1 | 2

2.2k | R33 | 6-0805_L | CMP-1013-00510-
2 | 1
39k | | R35, R36, R37, R42 | 6-0805_L | CMP-2001-00410-1 | 4
100k | | R39 | 6-0805_L | CMP-2001-00479-1 | 1
Res2 | Resistor | R45 | AXIAL-0.4 | Res2 | 1
430R | | R48 | 6-0805_L | CMP-2001-00410-1 | 1
KSA0A210 | | S1 | 6x6_mm_SMD_W S-TASV | KSA0A210 | 1
473521001 | MicroSD(TM), Pitch 1.1mm, 8 Position, Height 1.88mm, -20 to 85 degC, RoHS, Tape and Reel | SD1 | MOLX-473521001_V | CMP-2000-05848-1 | 1
FT230XS-U | USB to Basic UART Interface Chip, UHCI/OHCI/EHCI Compatible, USB 2.0 Compatible, -40 to +85 degC, 16-Pin SSOP, Pb-Free, Tube | U1 | SSOP-16_N | CMP-0248-00025-2 | 1
PIC32MX130F256D-I_PT | Microchip PIC32MX130F256D-I/PT, 32bit PIC Microcontroller, 40MHz, 256 kB Flash, 44-Pin TQFP | U2 | QFP80P1200X1200 X120-44N | PIC32MX130F256D-I_PT | 1
SN74HC138DR | IC 3-8 LINE DECOD/DEMUX 16-SOIC | U3 | FP-D0016A-IPC_A | CMP-1633-00238-3 | 1
MCP73871T-2CCI/ML | Charger IC Lithium Ion/Polymer 20-QFN _4x4_ | U4 | Microchip_C04-126_IPC_B | MCP73871T-2CCI/ML | 1
MAX1793EUE33+ | | U5 | TSOP65P640X110_ HS-17N | MAX1793EUE33+ | 1
TPS61022RWUT | POWER MANAGEMENT | U6 | FP-RWU0007A-MFG | CMP-04918-000300-1 | 1
3.3V | Test Point, 1 Position SMD, RoHS, Tape and Reel | V1 | KSTN-5019_V | CMP-1672-00008-1 | 1
VBOI | Test Point, 1 Position SMD, RoHS, Tape and Reel | V_btnON1 | KSTN-5019_V | CMP-1672-00008-1 | 1
Vcharge | Test Point, 1 Position SMD, RoHS, Tape and Reel | V_regIN1 | KSTN-5019_V | CMP-1672-00008-1 | 1
Vregu | Test Point, 1 Position SMD, RoHS, Tape and Reel | V_regOUT1 | KSTN-5019_V | CMP-1672-00008-1 | 1
Vbat | Test Point, 1 Position SMD, RoHS, Tape and Reel | Vbat1 | KSTN-5019_V | CMP-1672-00008-1 | 1
Jumper | Jumper Wire | W1, W2, W3, W4, W5, W6, W7, W8, W9, W10, W11, W12, W13, W14, W15, W16, W17, W18, W19, W20, W21 | RAD-0.2 | Jumper | 21
U262-161N-4BVC11 | U262-161N-4BVC11 XKB Connectivity | X1 | GCT_USB4105-GF-A | USB-C Type 2.0 | 1
XTAL | Crystal Oscillator | Y1 | R38 | XTAL | 1

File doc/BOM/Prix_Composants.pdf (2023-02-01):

Composant | Prix/unité
C0805C106K8PACT | 0,61
BAS40 | 0,14
150080SS75000 | 0,19
BNO055-ADAFRUIT | 27,5
742792133 (ferrite bead) | 0,24
SRN6045-1R0Y (Inducteur de puissance) | 0,57
BSS138LT1G (Power Mosfet) | 0,41
NVR1P02T1G (Power Mosfet) | 0,43
473521001 (Molex connector) | 4,34
FT230XS-U (FTDI) | 2,08
PIC32MX130F256DI_PT | 4,11
SN74HC138DR (demultiplexeur) | 0,42
MCP73871T-2CCI/ML (Chargeur) | 2,23
MAX1793EUE33+ (Regulateur 3,3V) | 4,02
TPS61022RWUT (Boost) | 2,07
U262-161N-4BVC11 (USB-C) | 0,39
Total | 49,75

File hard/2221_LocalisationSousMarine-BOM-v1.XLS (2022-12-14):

ETML
Refs | Nb | Désignation | Type | Valeur | Fournisseur | N° de commande | Prix u / 1 | Prix u / 10 | Prix u / 100 | Prix u / 1000 | Unité(s) d'emballage | Prix u / unité d'emballage | Prix de référence | Choix | Prix tot | Remarques
X1,X2 | 2 | Connecteur header pour câble plat DIN 41 651 sans bride de rétension | 3421-7600 | 20 pôles | Sasco Spoerle | 238221 |  |  | 2.450 | 2.150 | 100 | 2.450 | / un emb | * | 4.900 | p 3-23.002
 |  |  |  |  |  |  |  |  |  |  |  |  | -
 | 0.14 | m de câble plat 20 pôles | 3365-20 | 20 pôles | Sasco Spoerle | 270327 | 2.050 |  | 1.10 | 0.860 | 91m | 1.100 | / un emb | * | 0.154 | p3-26.029
 |  |  |  |  |  |  |  |  |  |  |  |  | -
 | 1 | montage |  |  | CIP |  |  |  |  |  |  |  | -
 |  |  |  |  | GXE |  |  | 4.000 | 3.000 |  |  |  | / 10 | * | 4.000
 |  |  |  |  |  |  |  |  |  |  |  |  | - | * | 0
 |  |  |  |  |  |  |  |  |  |  |  |  | -
 |  |  |  |  |  |  |  |  |  |  |  |  | - | * | 0
 |  |  |  |  |  |  |  |  |  |  |  |  | -
 |  |  |  |  |  |  |  |  |  |  |  |  | - | * | 0
 |  |  |  |  |  |  |  |  |  |  |  |  | -
 |  |  |  |  |  |  |  |  |  |  |  |  | - | * | 0
 |  |  |  |  |  |  |  |  |  |  |  |  | -
 |  |  |  |  |  |  |  |  |  |  |  |  | - | * | 0
 |  |  |  |  |  |  |  |  |  |  |  |  | -
 |  |  |  |  |  |  |  |  |  |  |  |  | - | * | 0
 |  |  |  |  |  |  |  |  |  |  |  |  | -
 |  |  |  |  |  |  |  |  |  |  |  |  | - | * | 0
 |  |  |  |  |  |  |  |  |  |  |  |  | -
 |  |  |  |  |  |  |  |  |  |  |  |  | - | * | 0
 |  |  |  |  |  |  |  |  |  |  |  |  | -
 |  |  |  |  |  |  |  |  |  |  |  |  | - | * | 0
 |  |  |  |  |  |  |  |  |  |  |  |  | -
 |  |  |  |  |  |  |  |  |  |  |  |  | - | * | 0
 |  |  |  |  |  |  |  |  |  |  |  |  | -
 |  |  |  |  |  |  |  |  |  |  |  |  | - | * | 0
 |  |  |  |  |  |  |  |  |  |  |  |  | -
 |  |  |  |  |  |  |  |  |  |  |  |  | - | * | 0
 |  |  |  |  |  |  |  |  |  |  |  |  | -
 |  |  |  |  |  |  |  |  |  |  |  |  | - | * | 0
 |  |  |  |  |  |  |  |  |  |  |  |  | -
 |  |  |  |  |  |  |  |  |  |  |  |  | - | * | 0
 |  |  |  |  |  |  |  |  |  |  |  |  | -
 |  |  |  |  |  |  |  |  |  |  |  |  | - | * | 0
 |  |  |  |  |  |  |  |  |  |  |  |  | -
 |  |  |  |  |  |  |  |  |  |  |  |  | - | * | 0
 |  |  |  |  |  |  |  |  |  |  |  |  | -
 |  |  |  |  |  |  |  |  |  |  |  |  | - | * | 0
 |  |  |  |  |  |  |  |  |  |  |  |  | -
 |  |  |  |  |  |  |  |  |  |  |  |  |  | Total: | 9.05

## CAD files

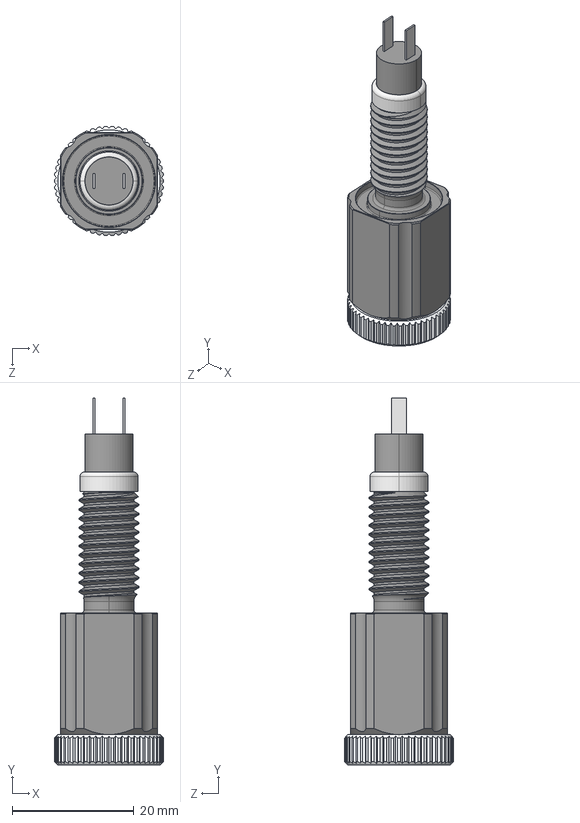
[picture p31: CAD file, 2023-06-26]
mec/button/SWITCH-M10-5A-R1-RP.STEP
18.0 x 60.3 x 18.0 mm
VENT-M10-BULKHEAD-R1_PRV-BULKHEAD-X1
PRV-M10-PLUG-R1_Switich
ORING-11.5X1.5-BUNA-70A_9262K523 x 2
Button GH1358-ND 5A_91772A555

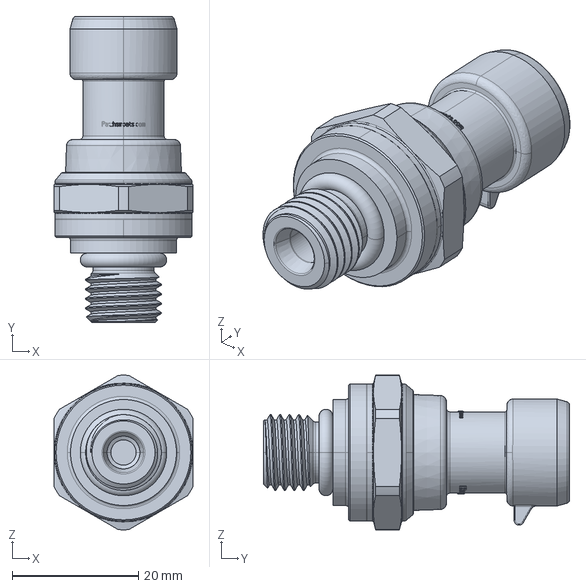
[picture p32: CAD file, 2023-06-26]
mec/pressure_sensor/mip-am1_sw_b.stp
22.0 x 48.5 x 24.5 mm

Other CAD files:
mec/button/SWITCH-M10-5A-R1-RP.SLDPRT
mec/button/SWITCH-M10-5A-R1-RP.STL

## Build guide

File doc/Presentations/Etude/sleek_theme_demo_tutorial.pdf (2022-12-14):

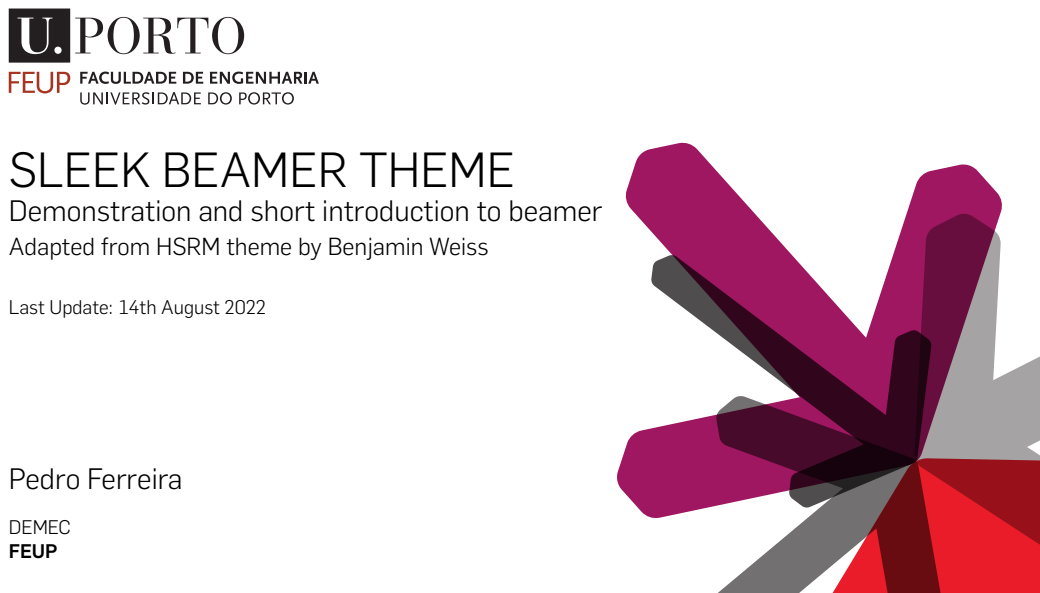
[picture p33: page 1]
Pedro Ferreira; DEMEC FEUP

SLEEK BEAMER THEME
Demonstration and short introduction to beamer
Adapted from HSRM theme by Benjamin Weiss

Last Update: 14th August 2022

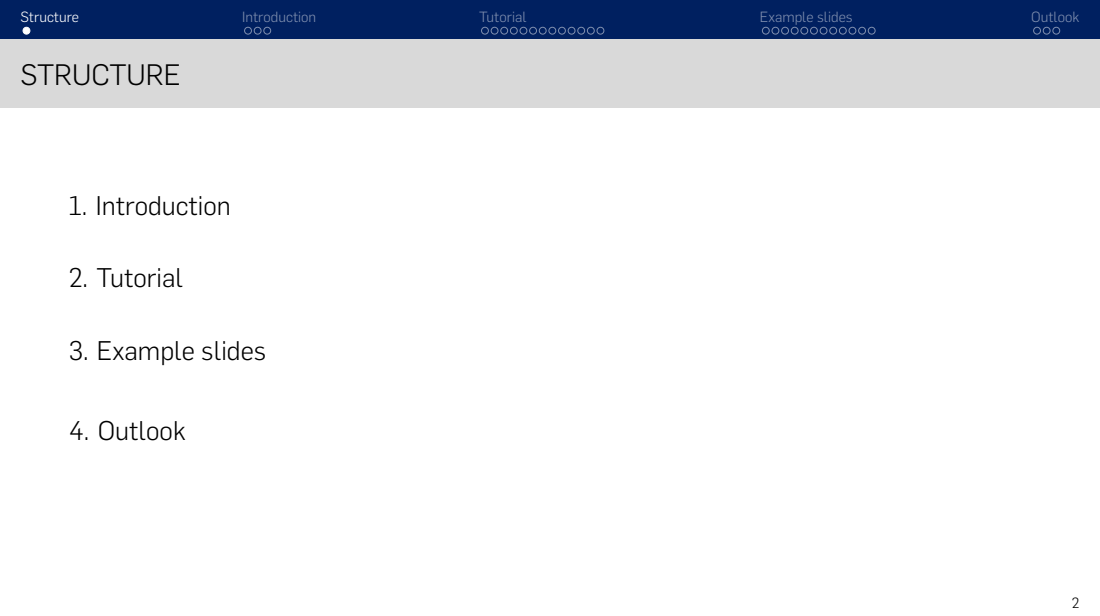
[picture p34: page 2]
Structure; Introduction; Tutorial; Example slides; Outlook; STRUCTURE; 1. Introduction; 2. Tutorial; 3. Example slides; 4. Outlook

## INTRODUCTION

The beamer classes for LATEX are used to create presentations that are to be shown with a beamer. The text typesetting system creates PDF files that can be shown by a large number of programmes.
The present theme was adapetd from HSRM theme by Benjamin Weiss and it makes the creation of slides (assuming basic knowledge of LATEX ) child’s play.

In order to successfully create presentations with this theme, the following requirements must be met by the system:

- LuaLaTeX must be used to typeset the slides.
- Besides some standard packages, the packages beamer, pgf and xcolor must be installed.
- The fonts ‘Flama-Light’, ‘Flama-Book’ and ‘Flama-Medium’ should be installed. Alternative: ‘Arial’
http://www.felicianotypefoundry.com/

## TUTORIAL

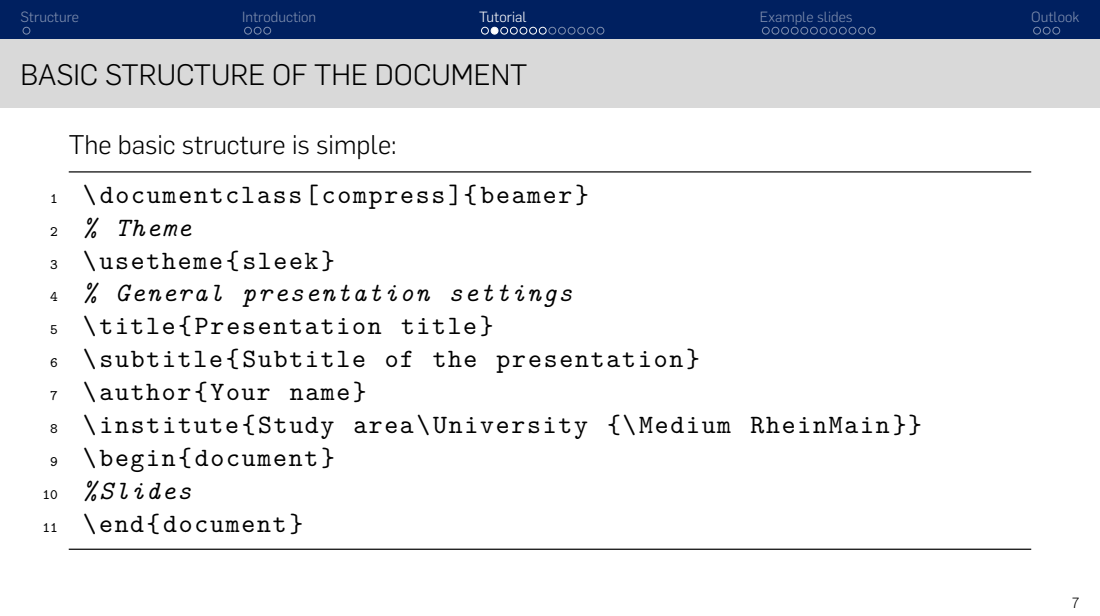
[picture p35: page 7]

BASIC STRUCTURE OF THE DOCUMENT

The basic structure is simple:
1 \ documentclass [compress ]{ beamer}
2 % Theme
3 \usetheme {sleek}
4 % General presentation settings
5 \title{ Presentation title}
6 \subtitle {Subtitle of the presentation }
7 \author{Your name}
8 \ institute {Study area\ University {\ Medium RheinMain }}
9 \begin{document }
10 %Slides
11 \end{document }

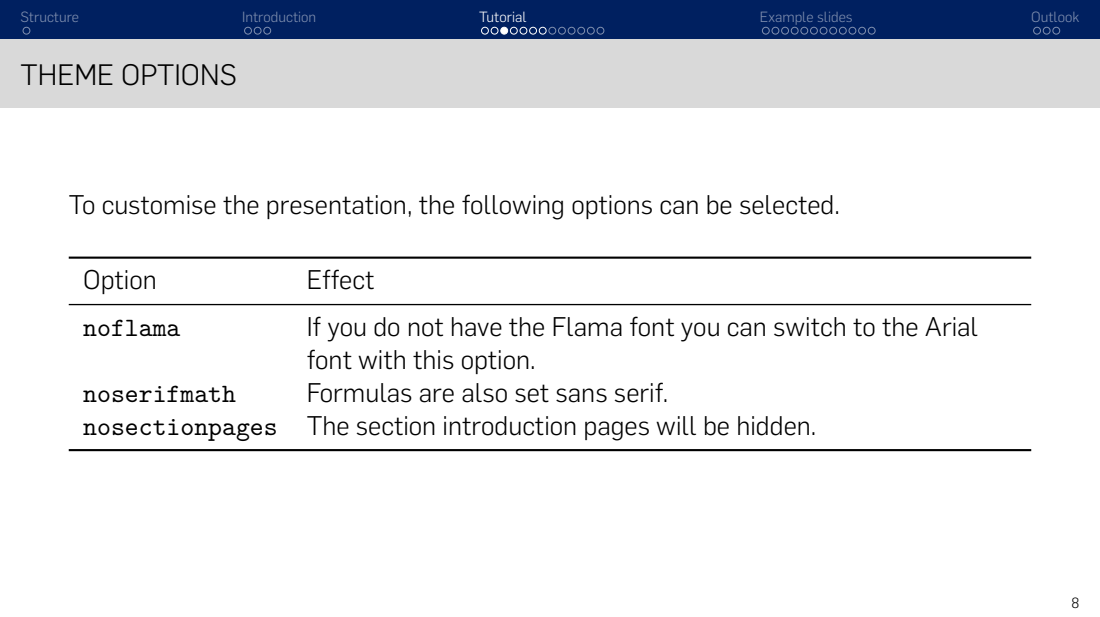
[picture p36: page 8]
THEME OPTIONS; Option; Effect; noflama; If you do not have the Flama font you can switch to the Arial; noserifmath; Formulas are also set sans serif.

To customise the presentation, the following options can be selected.

font with this option.

nosectionpages The section introduction pages will be hidden.

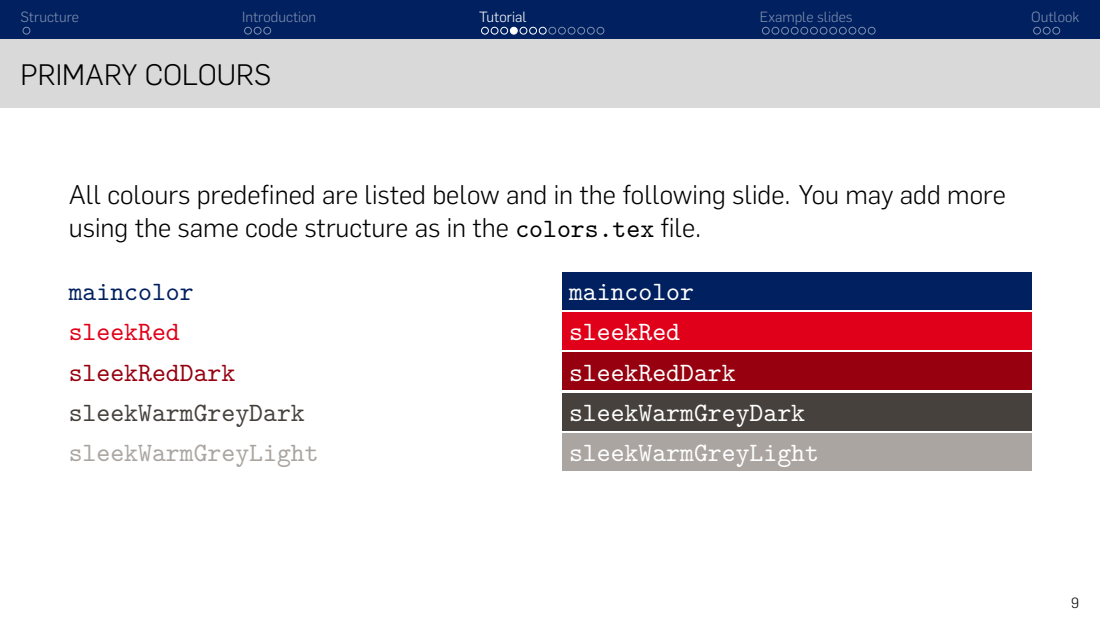
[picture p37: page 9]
PRIMARY COLOURS; maincolor sleekRed sleekRedDark sleekWarmGreyDark sleekWarmGreyLight

All colours predefined are listed below and in the following slide. You may add more
using the same code structure as in the colors.tex file.
maincolor
sleekRed
sleekRedDark
sleekWarmGreyDark
sleekWarmGreyLight

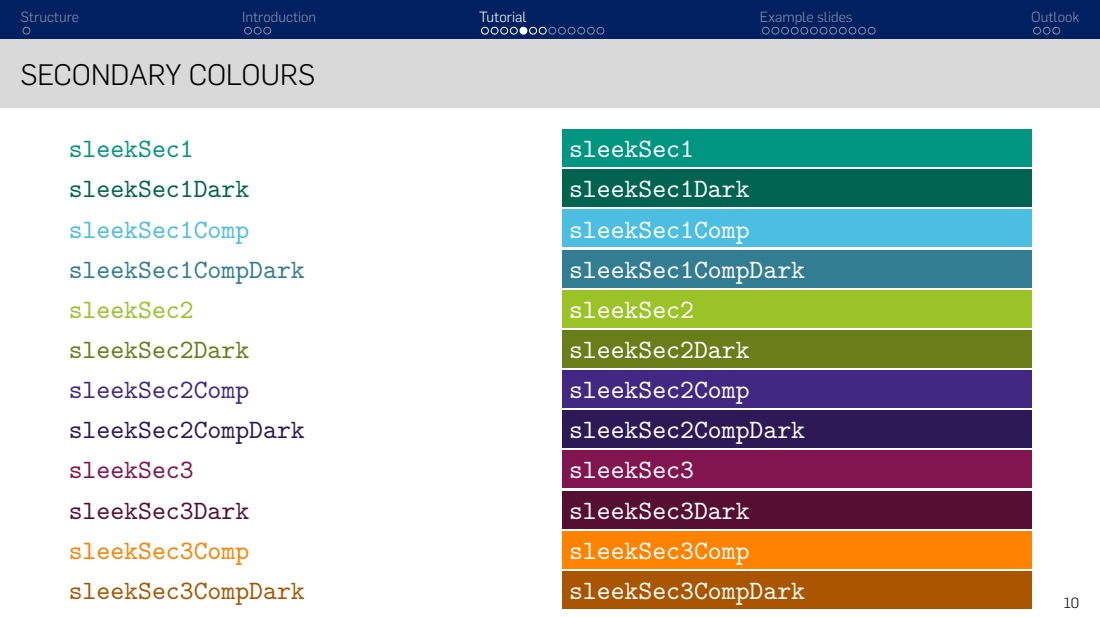
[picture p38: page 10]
SECONDARY COLOURS; sleekSec1 sleekSec1Dark sleekSec1Comp sleekSec1CompDark sleekSec2 sleekSec2Dark sleekSec2Comp sleekSec2CompDark sleekSec3 sleekSec3Dark sleekSec3Comp sleekSec3CompDark; sleekSec1 sleekSec1Dark sleekSec1Comp sleekSec1CompDark sleekSec2 sleekSec2Dark sleekSec2Comp sleekSec2CompDark sleekSec3 sleekSec3Dark sleekSec3Comp; sleekSec3CompDark

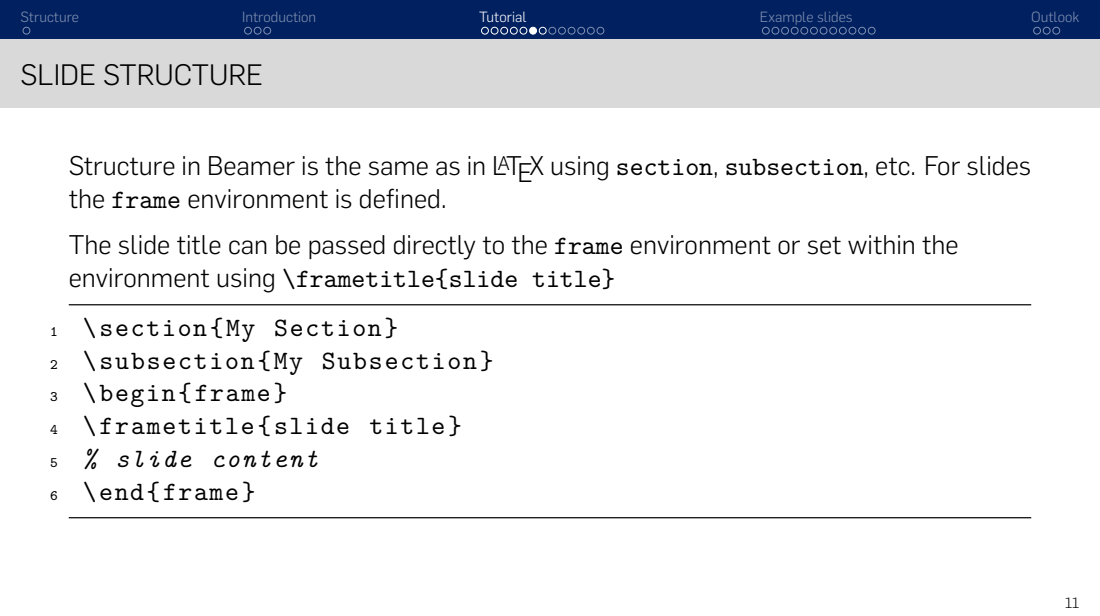
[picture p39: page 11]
SLIDE STRUCTURE

Structure in Beamer is the same as in LATEX using section, subsection, etc. For slides
the frame environment is defined.
The slide title can be passed directly to the frame environment or set within the
environment using \frametitle{slide title}
1 \section{My Section}
2 \ subsection {My Subsection }
3 \begin{frame}
4 \ frametitle {slide title}
5 % slide content
6 \end{frame}

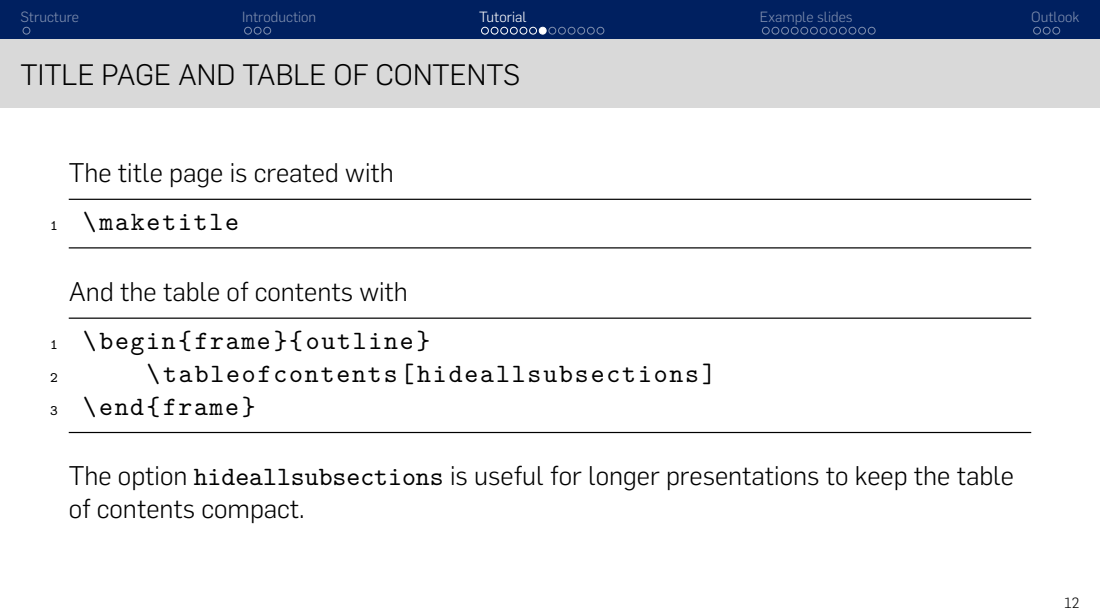
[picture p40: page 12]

TITLE PAGE AND TABLE OF CONTENTS

The title page is created with
1 \ maketitle

And the table of contents with
1 \begin{frame }{ outline}
2 \ tableofcontents [ hideallsubsections ]
3 \end{frame}

The option hideallsubsections is useful for longer presentations to keep the table
of contents compact.

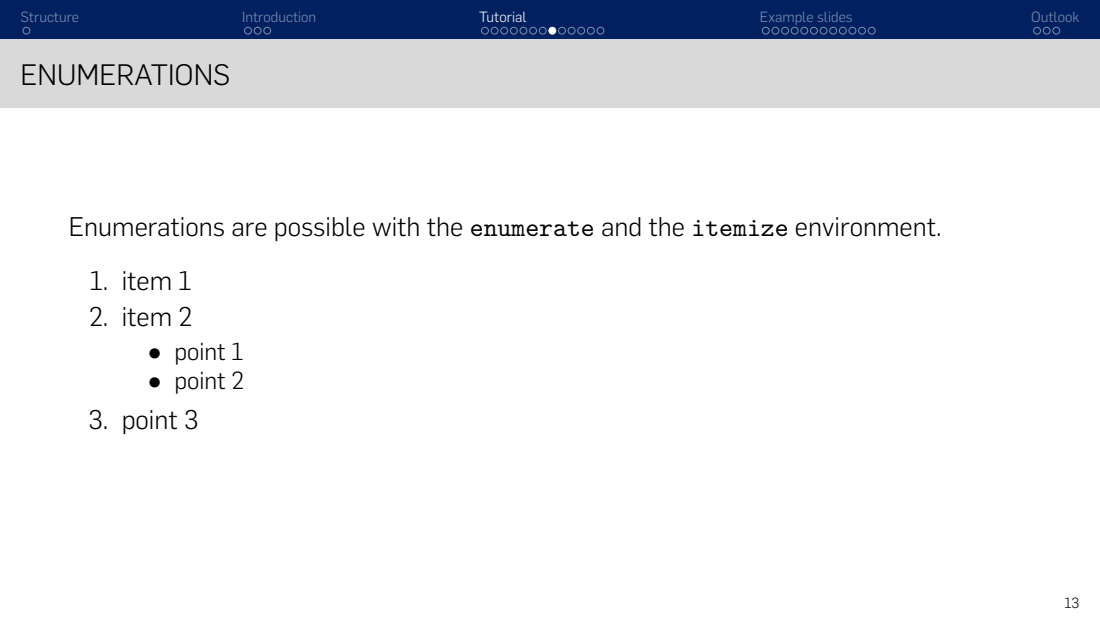
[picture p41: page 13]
ENUMERATIONS

Enumerations are possible with the enumerate and the itemize environment.
1. item 1
2. item 2
• point 1
• point 2
3. point 3

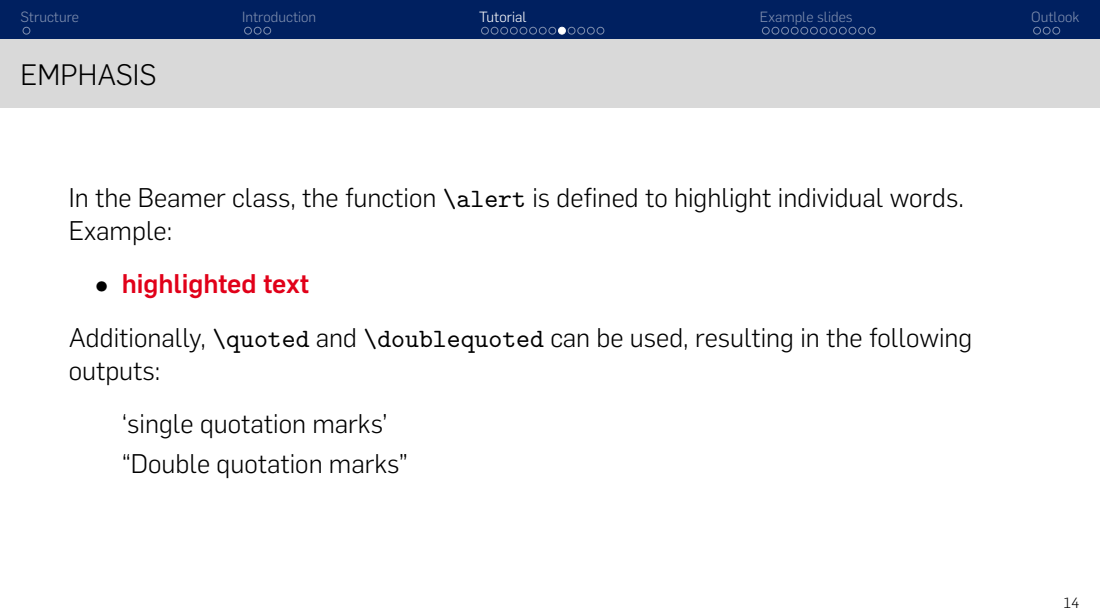
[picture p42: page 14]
EMPHASIS

In the Beamer class, the function \alert is defined to highlight individual words.
Example:
• highlighted text
Additionally, \quoted and \doublequoted can be used, resulting in the following
outputs:
‘single quotation marks’
“Double quotation marks”

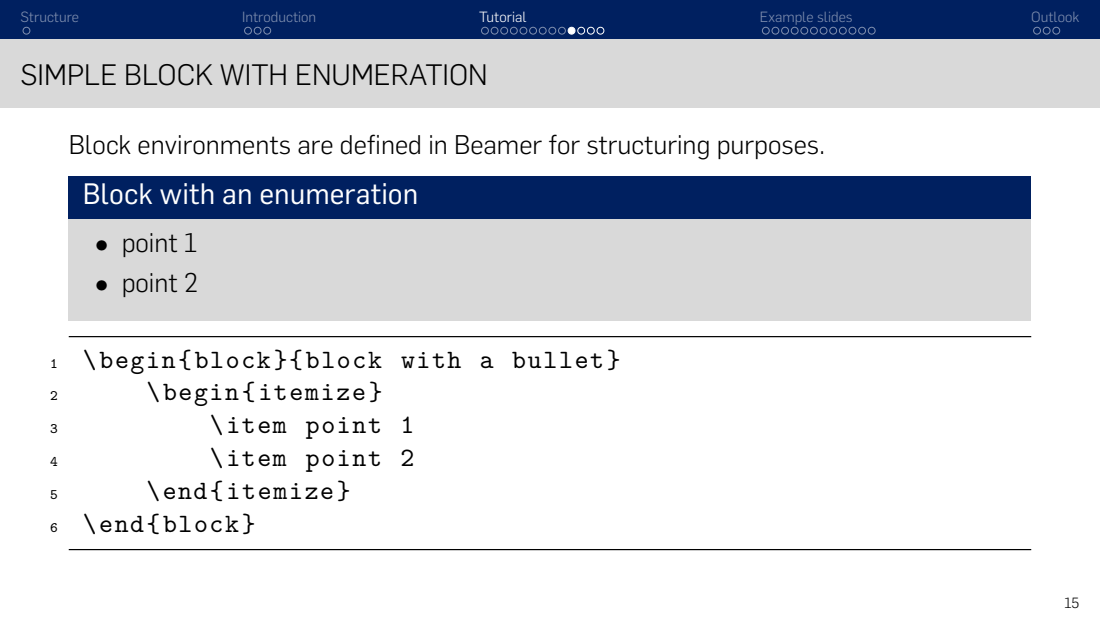
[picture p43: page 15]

SIMPLE BLOCK WITH ENUMERATION

Block environments are defined in Beamer for structuring purposes.
Block with an enumeration
• point 1
• point 2

1 \begin{block }{ block with a bullet}
2 \begin{itemize}
3 \item point 1
4 \item point 2
5 \end{itemize}
6 \end{block}

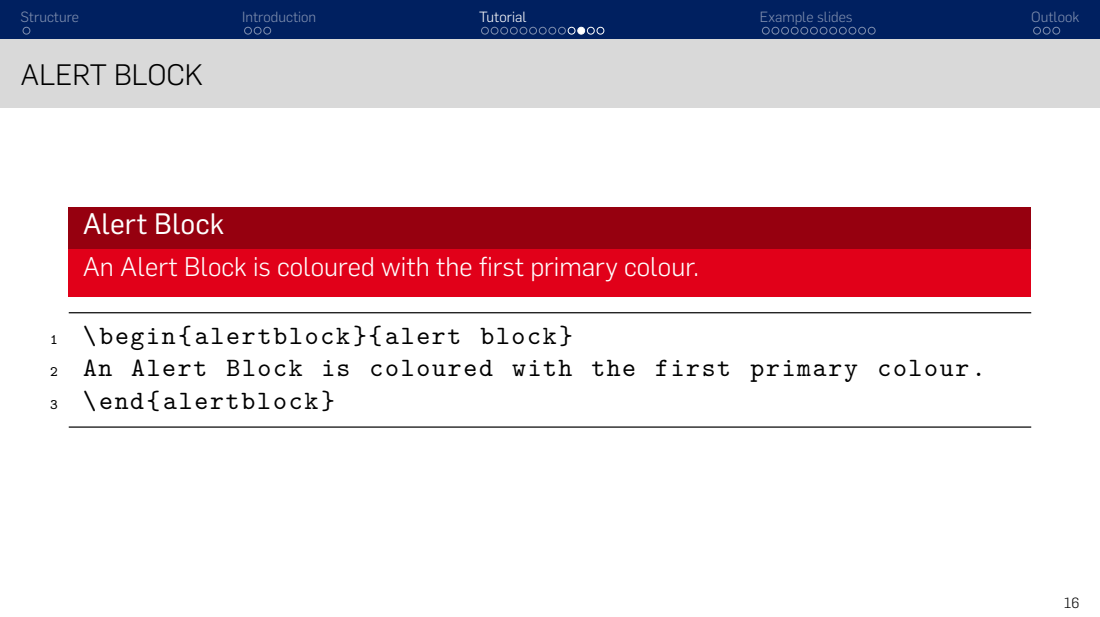
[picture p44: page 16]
ALERT BLOCK

Alert Block
An Alert Block is coloured with the first primary colour.
1 \begin{ alertblock }{ alert block}
2 An Alert Block is coloured with the first primary colour.
3 \end{ alertblock }

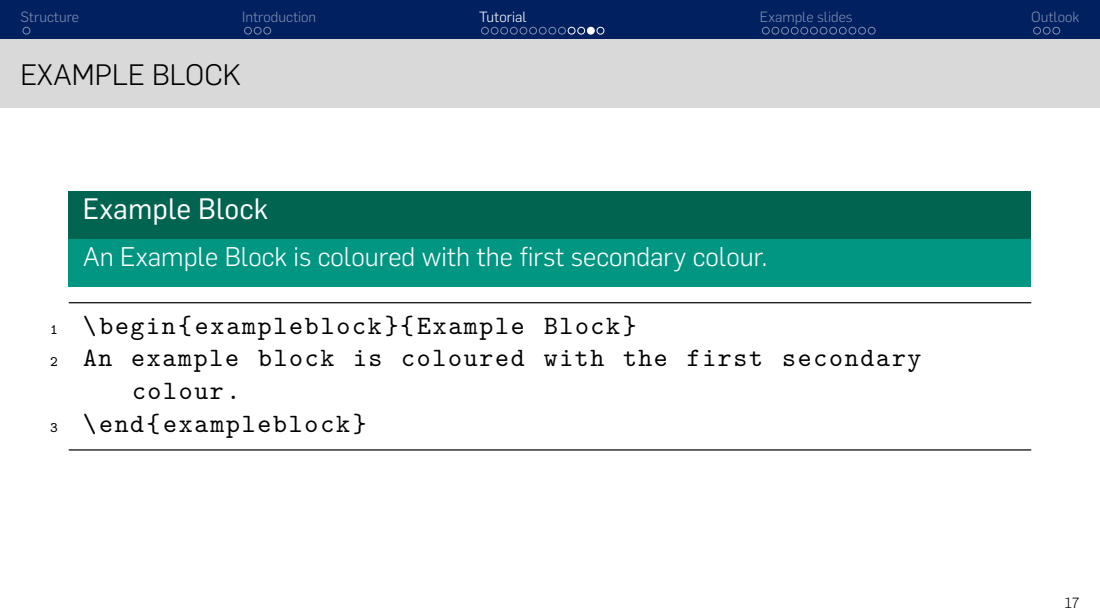
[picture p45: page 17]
EXAMPLE BLOCK

Example Block
An Example Block is coloured with the first secondary colour.
1 \begin{ exampleblock }{ Example Block}
2 An example block is coloured with the first secondary
colour.
3 \end{ exampleblock }

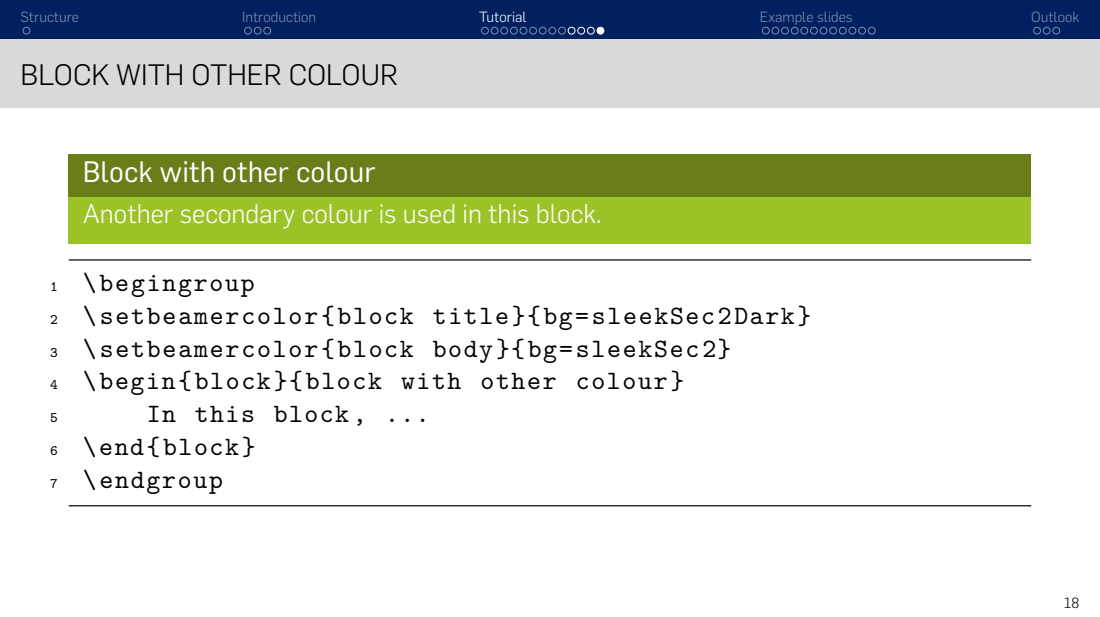
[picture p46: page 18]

BLOCK WITH OTHER COLOUR

Block with other colour
Another secondary colour is used in this block.
1 \ begingroup
2 \ setbeamercolor {block title }{bg=sleekSec2Dark}
3 \ setbeamercolor {block body }{bg=sleekSec 2}
4 \begin{block }{ block with other colour}
5 In this block , ...
6 \end{block}
7 \endgroup

## EXAMPLE SLIDES

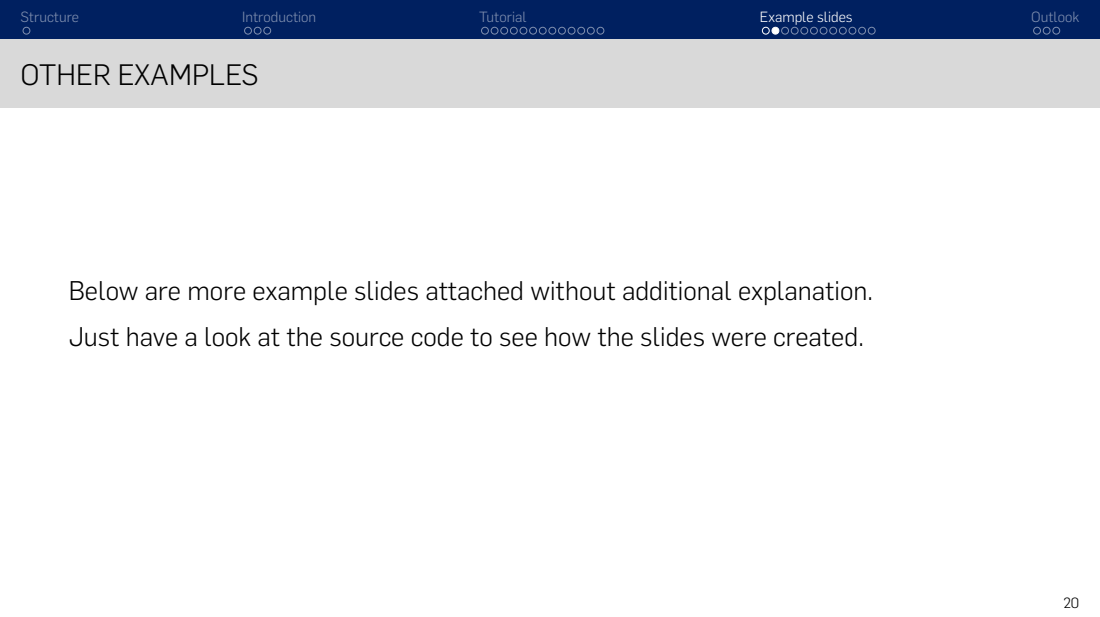
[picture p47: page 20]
OTHER EXAMPLES

Below are more example slides attached without additional explanation.
Just have a look at the source code to see how the slides were created.

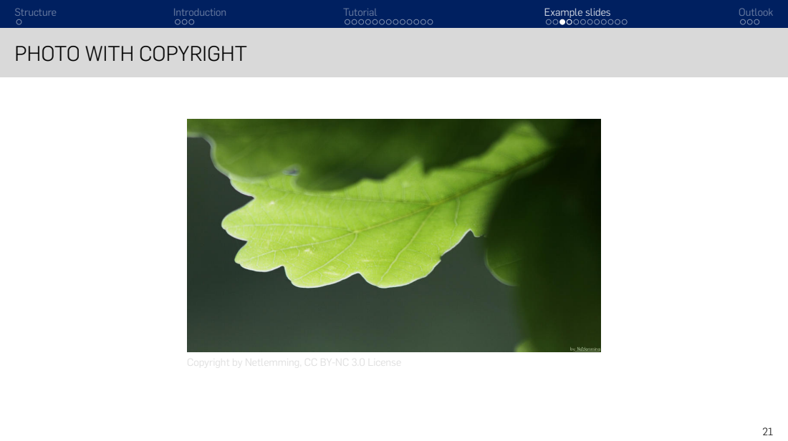
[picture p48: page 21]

PHOTO WITH COPYRIGHT

Copyright by Netlemming, (http://netzlemming.deviantart.com/) CC BY-NC 3.0 License (http://creativecommons.org/licenses/by-nc/3.0/)

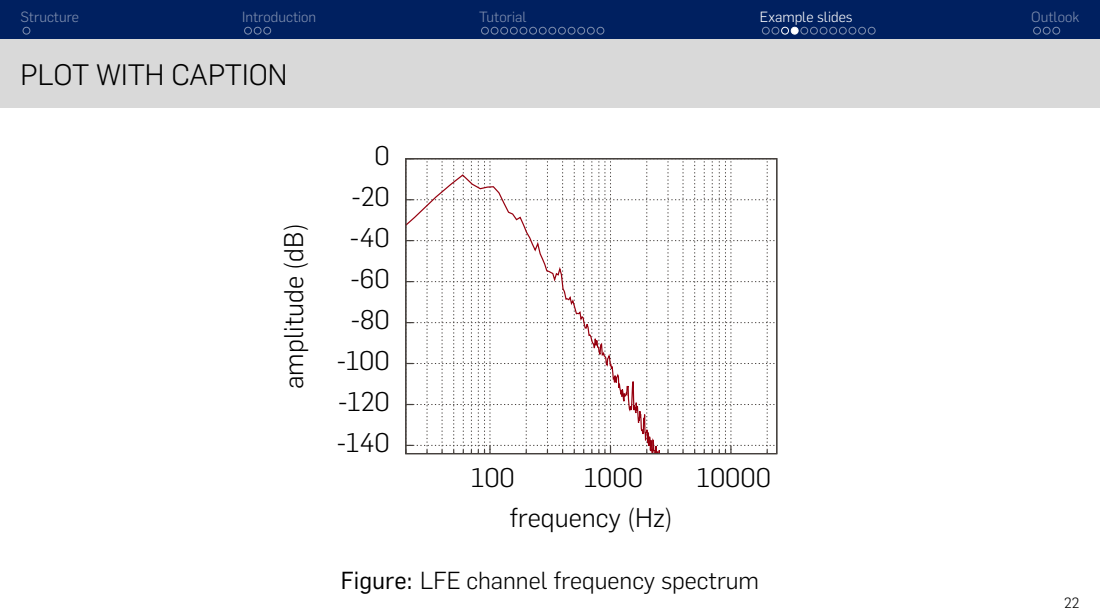
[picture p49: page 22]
amplitude (dB); frequency (Hz)

PLOT WITH CAPTION

Figure: LFE channel frequency spectrum

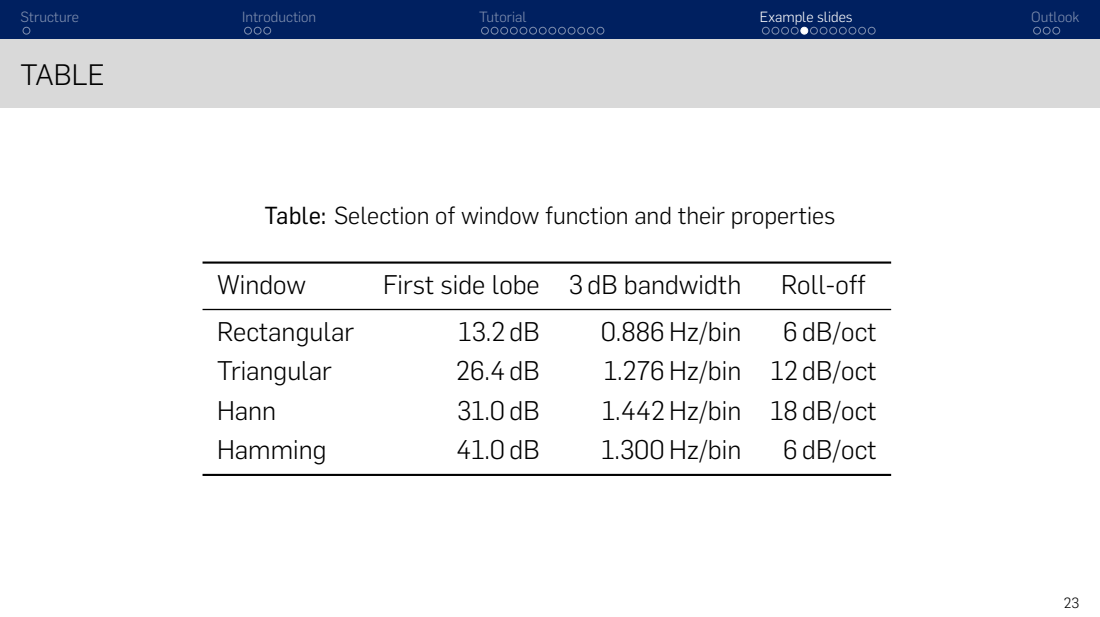
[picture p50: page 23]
TABLE; Window; First side lobe 3 dB bandwidth; Roll-off; Rectangular; 0.886 Hz/bin; 6 dB/oct; Triangular; 1.276 Hz/bin 12 dB/oct; Hann; 1.442 Hz/bin 18 dB/oct; Hamming; 1.300 Hz/bin

Table: Selection of window function and their properties

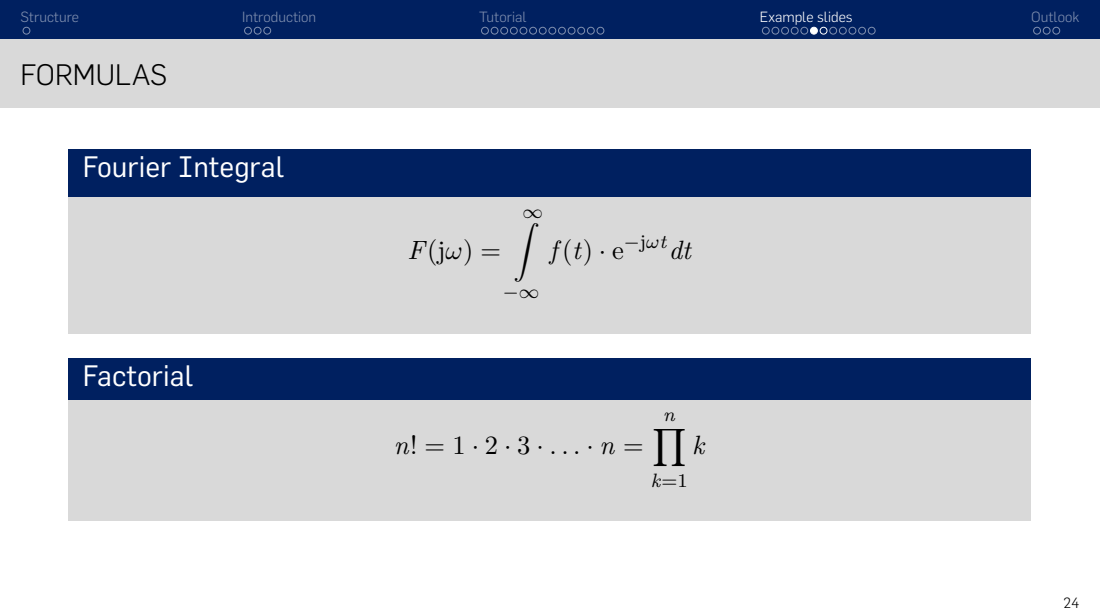
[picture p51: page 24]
FORMULAS; Fourier Integral; −jωt; Factorial

MINDMAP WITH TIKZ

Lorem ipsum dolor sit amet, consetetur sadipscing elitr, sed diam nonumy eirmod tempor invidunt ut labore et dolore magna aliquyam erat, sed diam voluptua. At vero eos et accusam et justo duo dolores et ea rebum. Stet clita kasd gubergren, no sea takimata sanctus est Lorem ipsum dolor sit amet. Lorem ¹
ipsum dolor sit amet,
consetetur sadipscing elitr, sed diam nonumy eirmod tempor invidunt ut labore et dolore magna aliquyam erat, sed diam voluptua. At vero eos et accusam et justo duo dolores et ea rebum. Stet clita kasd gubergren, no sea takimata sanctus est Lorem ipsum dolor sit amet.

1
Lorem ipsum dolor sit amet

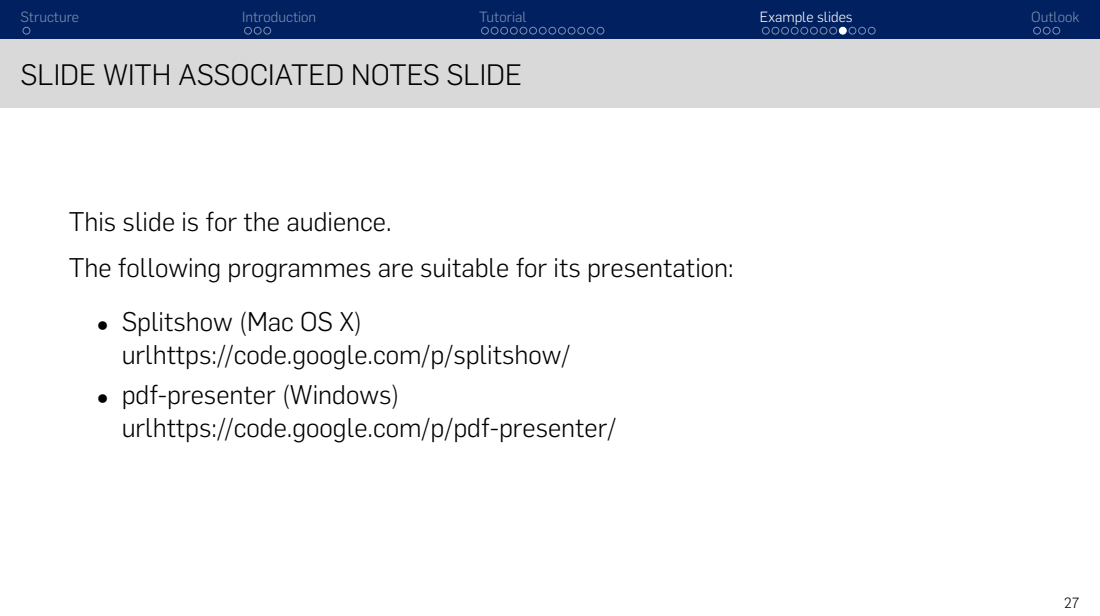
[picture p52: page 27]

SLIDE WITH ASSOCIATED NOTES SLIDE

This slide is for the audience.
The following programmes are suitable for its presentation:
• Splitshow (Mac OS X)
urlhttps://code.google.com/p/splitshow/
• pdf-presenter (Windows)
urlhttps://code.google.com/p/pdf-presenter/

SLIDE WITH ASSOCIATED NOTES SLIDE

This slide is for the audience. The following programmes are suitable for its presentation:

- Splitshow (Mac OS X) urlhttps://code.google.com/p/splitshow/
- pdf-presenter (Windows) urlhttps://code.google.com/p/pdf-presenter/

2022-08-14

Sleek Beamer Theme
Example slides
Notes
slide with associated notes slide

Use this slide for your notes on the presentation.
The following programmes are suitable for your presentation:
- Splitshow (Mac OS X)
https://code.google.com/p/splitshow/
- pdf-presenter (Windows)
https://code.google.com/p/pdf-presenter/

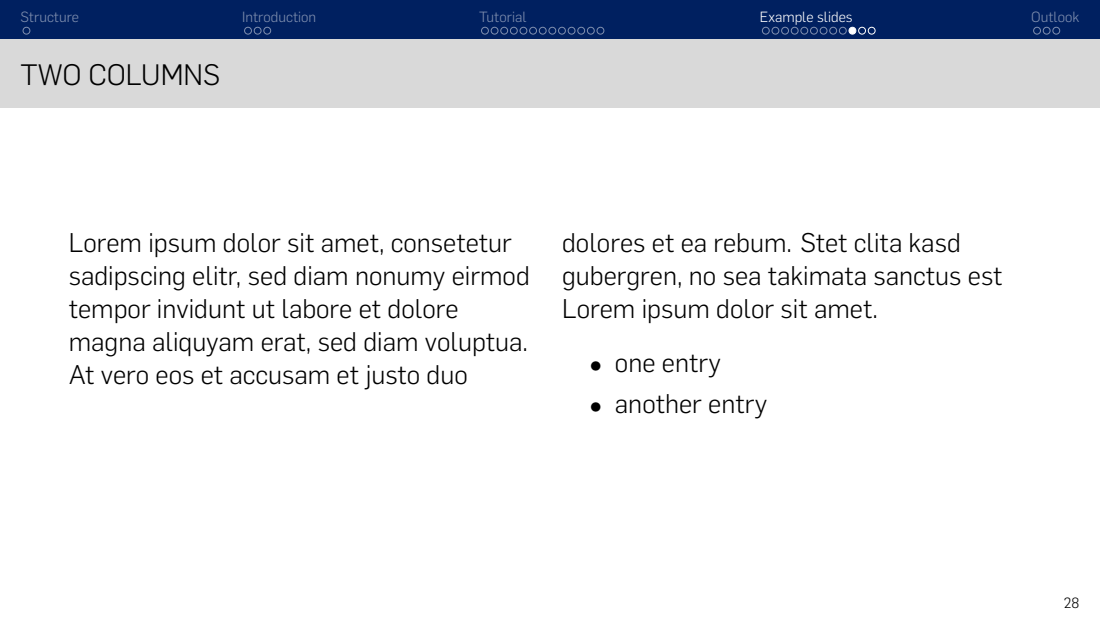
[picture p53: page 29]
TWO COLUMNS

Lorem ipsum dolor sit amet, consetetur
sadipscing elitr, sed diam nonumy eirmod
tempor invidunt ut labore et dolore
magna aliquyam erat, sed diam voluptua.
At vero eos et accusam et justo duo

dolores et ea rebum. Stet clita kasd
gubergren, no sea takimata sanctus est
Lorem ipsum dolor sit amet.
• one entry
• another entry

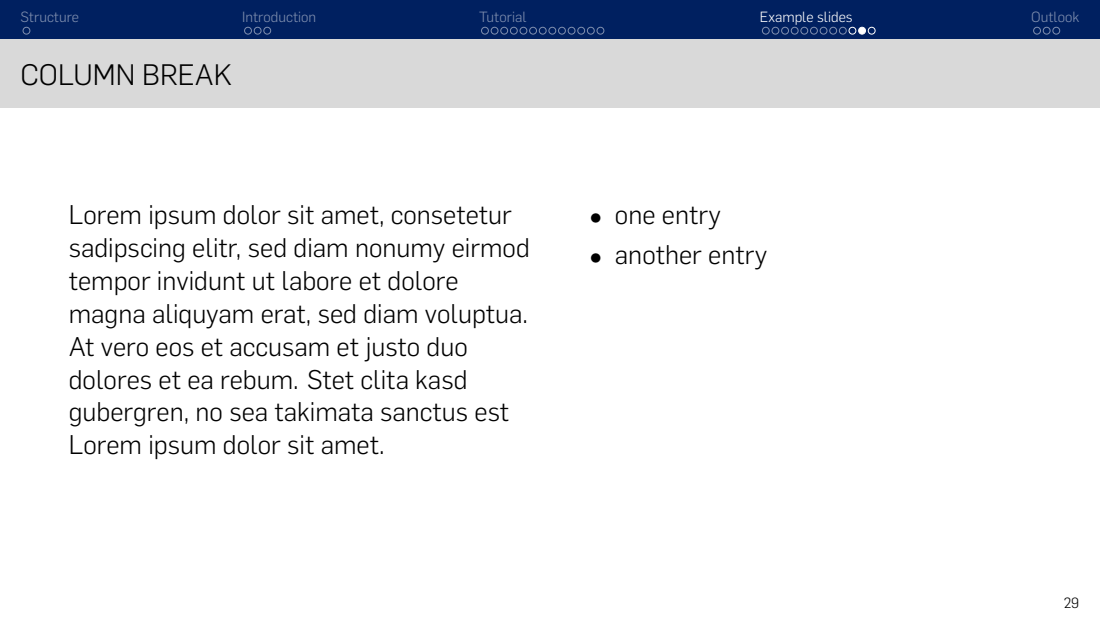
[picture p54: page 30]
COLUMN BREAK; • one entry • another entry

Lorem ipsum dolor sit amet, consetetur
sadipscing elitr, sed diam nonumy eirmod
tempor invidunt ut labore et dolore
magna aliquyam erat, sed diam voluptua.
At vero eos et accusam et justo duo
dolores et ea rebum. Stet clita kasd
gubergren, no sea takimata sanctus est
Lorem ipsum dolor sit amet.

Alan V. Oppenheim
“Discrete-Time Signal Processing”
Prentice Hall Press, 2009
European Broadcasting Union
“Specification of the Broadcast Wave Format (BWF)”

## OUTLOOK

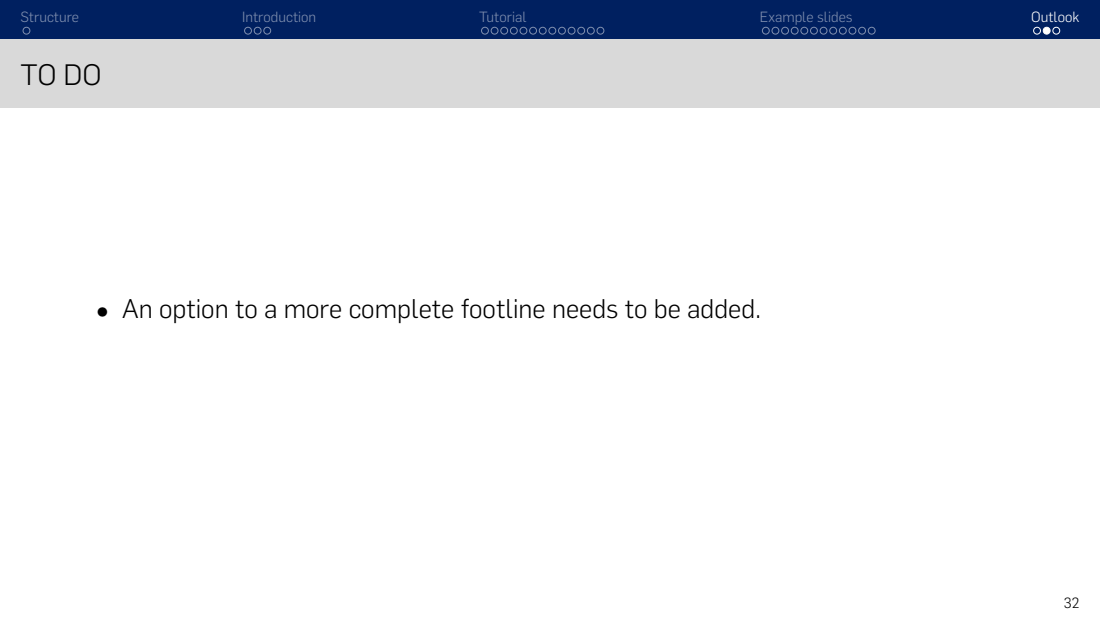
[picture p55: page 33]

• An option to a more complete footline needs to be added.

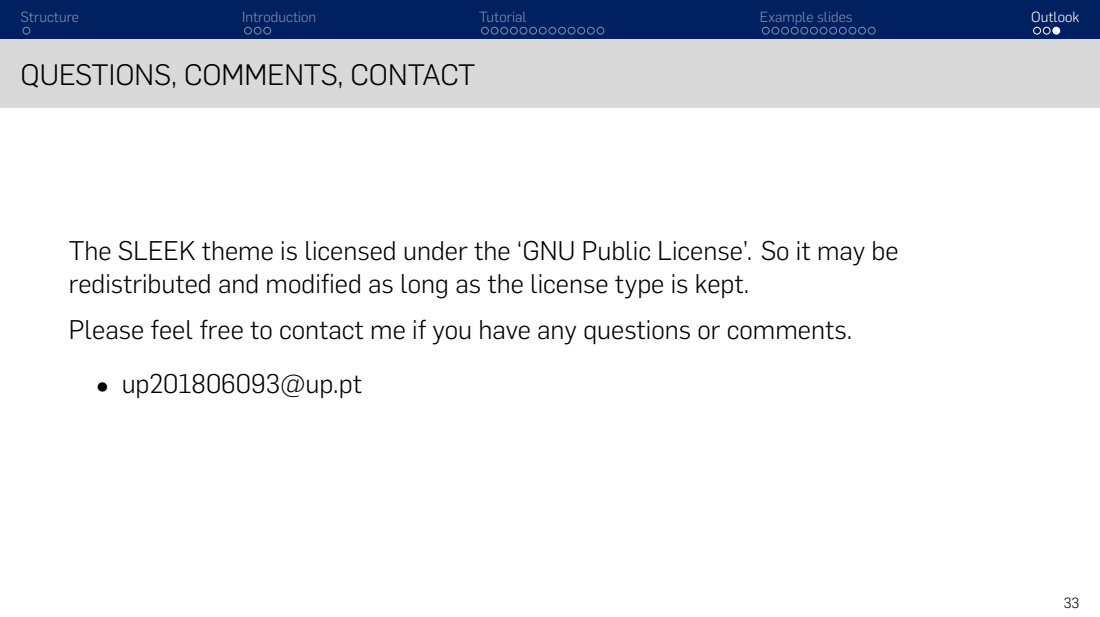
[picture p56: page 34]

QUESTIONS, COMMENTS, CONTACT

The SLEEK theme is licensed under the ‘GNU Public License’. So it may be
redistributed and modified as long as the license type is kept.
Please feel free to contact me if you have any questions or comments.

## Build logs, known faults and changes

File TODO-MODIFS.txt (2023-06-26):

REVOIR SYSTEME MULTIPEXEUR POUR CHIPS SELECT (POLARITE CS DE LA CARTE SD DIFFERENT)

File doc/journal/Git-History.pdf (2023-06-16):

2023-06-16 02:21:37 +0200 Ali-Z0 <ali.zoubir@eduvaud.ch> eb5b2b8 Rapport-final 2023-06-16 02:12:37 +0200 Ali-Z0 <ali.zoubir@eduvaud.ch> 3b6605a Rapport-aveclisting
2023-06-16 01:35:50 +0200 Ali-Z0 <ali.zoubir@eduvaud.ch> 779144d Update-rapport 2023-06-16 00:28:21 +0200 Ali-Z0 <ali.zoubir@eduvaud.ch> bfe370a Big-update-rapport 2023-06-16 00:08:18 +0200 Ali-Z0 <ali.zoubir@eduvaud.ch> 0111649 Update-rapport 2023-06-15 21:28:13 +0200 Ali-Z0 <ali.zoubir@eduvaud.ch> 1891661 Update-rapport 2023-06-15 20:59:46 +0200 Ali-Z0 <ali.zoubir@eduvaud.ch> 280b70c Am-nagement-dudossier
2023-06-15 20:35:09 +0200 Ali-Z0 <ali.zoubir@eduvaud.ch> 3aa4809 Update-code 2023-06-15 20:34:45 +0200 Ali-Z0 <ali.zoubir@eduvaud.ch> cccd727 Update-rapport 2023-06-15 20:14:44 +0200 Ali-Z0 <ali.zoubir@eduvaud.ch> d8d8e52 Raccourci-mesure 2023-06-15 20:13:50 +0200 Ali-Z0 <ali.zoubir@eduvaud.ch> f2db082 Big-update-rapport 2023-06-15 18:07:41 +0200 Ali-Z0 <107996590+Ali-Z0@users.noreply.github.com> 1659577 Mesures-putty
2023-06-15 18:06:04 +0200 Ali-Z0 <ali.zoubir@eduvaud.ch> 178293d Update-rapport 2023-06-15 17:38:06 +0200 Ali-Z0 <ali.zoubir@eduvaud.ch> 32cd1d2 Update-rapport 2023-06-15 13:48:06 +0200 Ali-Z0 <ali.zoubir@eduvaud.ch> 86493f6 Update-rapport 2023-06-15 11:24:58 +0200 Ali-Z0 <ali.zoubir@eduvaud.ch> fe25d38 Update-rapport 2023-06-15 10:43:02 +0200 Ali-Z0 <ali.zoubir@eduvaud.ch> f5456fe MAJ-UART 2023-06-15 10:42:33 +0200 Ali-Z0 <ali.zoubir@eduvaud.ch> d54edc0 Update-Dev-MEAS.tex
2023-06-15 10:40:17 +0200 Ali-Z0 <107996590+Ali-Z0@users.noreply.github.com> 8cdbbaf Mesure-UART
2023-06-15 10:24:08 +0200 Ali-Z0 <107996590+Ali-Z0@users.noreply.github.com> ea4dc88 Mesure-analyseur
2023-06-15 10:03:08 +0200 Ali-Z0 <ali.zoubir@eduvaud.ch> ed1baec Rapport-mesurestension
2023-06-15 09:23:01 +0200 Ali-Z0 <ali.zoubir@eduvaud.ch> 66bbd2f Update-rapport 2023-06-14 17:20:52 +0200 Ali-Z0 <ali.zoubir@eduvaud.ch> d3ec230 Dessin-trame 2023-06-14 17:16:35 +0200 Ali-Z0 <ali.zoubir@eduvaud.ch> 19edfd9 Update-rapport 2023-06-14 16:33:05 +0200 Ali-Z0 <ali.zoubir@eduvaud.ch> 32ced00 Optimisationespace
2023-06-14 16:31:43 +0200 Ali-Z0 <ali.zoubir@eduvaud.ch> e89f09d Update-rapport 2023-06-14 15:57:01 +0200 Ali-Z0 <ali.zoubir@eduvaud.ch> 026173d Update-code 2023-06-14 15:39:26 +0200 Ali-Z0 <ali.zoubir@eduvaud.ch> e841e92 Big-updace-code 2023-06-14 13:03:48 +0200 Ali-Z0 <ali.zoubir@eduvaud.ch> 49c6d60 Am-lioration-ducode
2023-06-14 12:33:50 +0200 Ali-Z0 <ali.zoubir@eduvaud.ch> ebb874f Commentaires-code 2023-06-14 12:26:52 +0200 Ali-Z0 <ali.zoubir@eduvaud.ch> f4689bf Update-rapportcommentaires-code
2023-06-14 11:21:42 +0200 Ali-Z0 <ali.zoubir@eduvaud.ch> 74b8c3c Update-rapport 2023-06-13 17:09:45 +0200 Ali-Z0 <ali.zoubir@eduvaud.ch> d4a887f Big-update-rapport 2023-06-13 16:07:31 +0200 Ali-Z0 <ali.zoubir@eduvaud.ch> e480047 Update-rapport 2023-06-13 14:27:36 +0200 Ali-Z0 <ali.zoubir@eduvaud.ch> 579fa43 Update-rapport 2023-06-13 13:50:41 +0200 Ali-Z0 <ali.zoubir@eduvaud.ch> 7cd88d0 Code-V0-fonctionnel
2023-06-13 11:39:42 +0200 Ali-Z0 <ali.zoubir@eduvaud.ch> 9667ae5 New-code-plusrapide
2023-06-08 12:02:41 +0200 Ali-Z0 <ali.zoubir@eduvaud.ch> 0a124d0 Update-TODO-MODIFS.txt
2023-06-07 19:43:34 +0200 Ali-Z0 <107996590+Ali-Z0@users.noreply.github.com>

f5a834a Code-fonctionnel-90ms-par-mesures
2023-06-07 17:17:38 +0200 Ali-Z0 <ali.zoubir@eduvaud.ch> d498273 Mesures-chaques-90ms
2023-06-07 17:05:21 +0200 Ali-Z0 <ali.zoubir@eduvaud.ch> d4c3d99 30min-loggingavec-160ms-moyenne
2023-06-07 15:42:09 +0200 Ali-Z0 <ali.zoubir@eduvaud.ch> cf2a4a6 Code-mesuresrapide-20-100ms
2023-05-31 16:43:08 +0200 Ali-Z0 <ali.zoubir@eduvaud.ch> 35c7bdf Update-code 2023-05-31 12:58:59 +0200 Ali-Z0 <ali.zoubir@eduvaud.ch> 0f76e92 rapport-journal-detravail
2023-05-30 17:07:40 +0200 Ali-Z0 <ali.zoubir@eduvaud.ch> 729ced2 Ajout-code-avec-ADC-pour-pression
2023-05-30 17:02:43 +0200 Ali-Z0 <107996590+Ali-Z0@users.noreply.github.com> d6713a3 Update-README.md
2023-05-24 19:04:40 +0200 Ali-Z0 <ali.zoubir@eduvaud.ch> 21e7431 Correction-CSV 2023-05-24 17:18:28 +0200 Ali-Z0 <ali.zoubir@eduvaud.ch> 98a8ff0 Am-lioration-destemps
2023-05-24 15:54:15 +0200 Ali-Z0 <ali.zoubir@eduvaud.ch> 504d725 Update-code-Carte-SD-Fonctionnelle
2023-05-17 18:08:32 +0200 Ali-Z0 <ali.zoubir@eduvaud.ch> 76cd463 New-code-UART-Debut-SPI-SD
2023-05-16 10:37:08 +0200 Ali-Z0 <107996590+Ali-Z0@users.noreply.github.com> d82b82a Update-bno055_support.c
2023-05-16 10:34:23 +0200 Ali-Z0 <107996590+Ali-Z0@users.noreply.github.com> fc7436d Update-private.xml
2023-05-15 13:17:26 +0200 Ali-Z0 <ali.zoubir@eduvaud.ch> 43cd953 Update-TODO-MODIFS.txt
2023-05-11 21:49:19 +0200 Ali-Z0 <107996590+Ali-Z0@users.noreply.github.com> 8633d0a IMU-fonctionnelle
2023-05-11 14:06:15 +0200 Ali-Z0 <107996590+Ali-Z0@users.noreply.github.com> 556f21c Update-README.md
2023-05-11 09:22:56 +0200 Ali-Z0 <ali.zoubir@eduvaud.ch> c3997ce Merge-branchmain-of-https-github.com-Ali-Z0-2221_LocalisationSousMarine
2023-05-11 09:22:43 +0200 Ali-Z0 <ali.zoubir@eduvaud.ch> 279eb7e Create-Etats_diagramme.jpg
2023-05-11 09:03:21 +0200 Ali-Z0 <107996590+Ali-Z0@users.noreply.github.com> b6fcc00 Update-README.md
2023-05-11 08:57:31 +0200 Ali-Z0 <ali.zoubir@eduvaud.ch> 666c1eb illustration 2023-05-11 08:40:59 +0200 Ali-Z0 <107996590+Ali-Z0@users.noreply.github.com> 6a1a3aa Create-README.md
2023-05-10 17:10:28 +0200 Ali-Z0 <ali.zoubir@eduvaud.ch> 76c7e7d New-code 2023-05-03 17:16:07 +0200 Ali-Z0 <ali.zoubir@eduvaud.ch> 294eb72 Updace-code 2023-05-03 16:54:44 +0200 Ali-Z0 <ali.zoubir@eduvaud.ch> ab36126 Update-all 2023-04-26 17:29:09 +0200 Ali-Z0 <ali.zoubir@eduvaud.ch> 7b2cca8 Update-TODO-MODIFS.txt
2023-04-26 16:56:42 +0200 Ali-Z0 <ali.zoubir@eduvaud.ch> 7e6a8ef Update-TODO-MODIFS.txt
2023-04-26 16:54:55 +0200 Ali-Z0 <ali.zoubir@eduvaud.ch> 2e7d41c TODO-MODIFS 2023-04-26 16:52:48 +0200 Ali-Z0 <ali.zoubir@eduvaud.ch> 7206816 MEC-files 2023-04-26 16:51:56 +0200 Ali-Z0 <ali.zoubir@eduvaud.ch> c03a1e7 PATH 2023-04-26 16:51:21 +0200 Ali-Z0 <ali.zoubir@eduvaud.ch> 0fc7bf2 Added-code 2023-04-26 16:50:26 +0200 Ali-Z0 <ali.zoubir@eduvaud.ch> debe539 Huge-update

2023-04-05 16:56:55 +0200 Ali-Z0 <ali.zoubir@eduvaud.ch> cfa31a6 Update-all 2023-04-03 09:24:32 +0200 Ali-Z0 <ali.zoubir@eduvaud.ch> 5a3cb29 Update-bom 2023-03-30 09:21:02 +0200 Ali-Z0 <ali.zoubir@eduvaud.ch> 65dd4a2 BOM 2023-03-22 16:49:22 +0100 Ali Zoubir <ali.zoubir@eduvaud.ch> 671f6bb Update-Altium 2023-03-22 15:14:06 +0100 Ali Zoubir <ali.zoubir@eduvaud.ch> b18fc90 Update-Logo 2023-03-22 11:34:00 +0100 Ali Zoubir <ali.zoubir@eduvaud.ch> 49d9dba Simuls 2023-03-22 11:33:30 +0100 Ali Zoubir <ali.zoubir@eduvaud.ch> ee14900 Update-all 2023-03-22 11:15:47 +0100 Ali Zoubir <ali.zoubir@eduvaud.ch> c54ebc4 Update-all 2023-03-22 10:17:55 +0100 Ali Zoubir <ali.zoubir@eduvaud.ch> c7213fd Update-PCB 2023-03-21 19:08:33 +0100 Ali Zoubir <ali.zoubir@eduvaud.ch> 846f474 Update-sch 2023-03-21 18:59:53 +0100 Ali Zoubir <ali.zoubir@eduvaud.ch> 0cd778f Update-PCB 2023-03-21 18:56:35 +0100 Ali Zoubir <ali.zoubir@eduvaud.ch> 41fa6c4 Changed-boostcircuit
2023-03-21 15:51:12 +0100 Ali Zoubir <ali.zoubir@eduvaud.ch> 9eb31a1 Eurocircuit 2023-03-21 15:41:53 +0100 Ali Zoubir <ali.zoubir@eduvaud.ch> d2716c3 Lib-PCB 2023-03-21 15:21:43 +0100 Ali Zoubir <ali.zoubir@eduvaud.ch> c20b076 Update-PCB 2023-03-21 10:06:48 +0100 Ali Zoubir <ali.zoubir@eduvaud.ch> 4ed0522 Updatedstitichng
2023-03-20 18:11:09 +0100 Ali Zoubir <ali.zoubir@eduvaud.ch> aa44c85 Update-outob 2023-03-20 18:07:54 +0100 Ali Zoubir <ali.zoubir@eduvaud.ch> 1f07dc2 Update-BOM-Projet
2023-03-15 16:23:45 +0100 Ali Zoubir <ali.zoubir@eduvaud.ch> 672a064 Updated-routing 2023-03-15 16:09:46 +0100 Ali Zoubir <ali.zoubir@eduvaud.ch> bee3c3d Update-routage 2023-03-15 14:57:13 +0100 Ali Zoubir <ali.zoubir@eduvaud.ch> 8654efd Update-routage 2023-03-15 11:15:13 +0100 Ali Zoubir <ali.zoubir@eduvaud.ch> af942b4 Update-routage 2023-03-08 16:53:35 +0100 Ali Zoubir <ali.zoubir@eduvaud.ch> a623185 Update-all 2023-03-08 15:09:36 +0100 Ali Zoubir <ali.zoubir@eduvaud.ch> 497adee Update-footprint 2023-03-08 13:02:30 +0100 Ali Zoubir <ali.zoubir@eduvaud.ch> c80a694 Update-DIMS 2023-03-08 12:47:42 +0100 Ali Zoubir <ali.zoubir@eduvaud.ch> 6f464b4 Updateplacement
2023-03-08 11:57:58 +0100 Ali Zoubir <ali.zoubir@eduvaud.ch> 945a0ba Updateplacement-et-taille
2023-03-08 10:44:06 +0100 Ali Zoubir <ali.zoubir@eduvaud.ch> 9027ee1 PCBdimensions
2023-03-08 09:37:18 +0100 Ali Zoubir <ali.zoubir@eduvaud.ch> b4cf5a6 Udateplacement
2023-03-07 09:15:02 +0100 Ali Zoubir <ali.zoubir@eduvaud.ch> b4eaf53 Update-report 2023-03-01 16:49:22 +0100 Ali Zoubir <ali.zoubir@eduvaud.ch> 293c7d1 Updateplacement-Schema
2023-03-01 14:14:15 +0100 Ali Zoubir <ali.zoubir@eduvaud.ch> d581f5c Updateplacement
2023-03-01 11:30:30 +0100 Ali Zoubir <ali.zoubir@eduvaud.ch> 4661b3d PCB-Placement 2023-03-01 11:25:22 +0100 Ali Zoubir <ali.zoubir@eduvaud.ch> b722a7a PCB-Placement 2023-03-01 10:47:33 +0100 Ali Zoubir <ali.zoubir@eduvaud.ch> 2f5bc1b Update-PCB 2023-03-01 09:30:58 +0100 Ali Zoubir <ali.zoubir@eduvaud.ch> 5a04943 Annotations 2023-03-01 09:19:53 +0100 Ali Zoubir <ali.zoubir@eduvaud.ch> 8be3cba SCH-PCB 2023-02-22 16:33:19 +0100 Ali Zoubir <ali.zoubir@eduvaud.ch> b105fa5 Update-SCH 2023-02-22 15:32:47 +0100 Ali Zoubir <ali.zoubir@eduvaud.ch> 2b581f0 Updatefootprints
2023-02-22 15:02:24 +0100 Ali Zoubir <ali.zoubir@eduvaud.ch> 83b7b38 Updatefootprints
2023-02-22 14:43:52 +0100 Ali Zoubir <ali.zoubir@eduvaud.ch> e1c0d85 Update-PCB-

Lib
2023-02-22 13:58:27 +0100 Ali Zoubir <ali.zoubir@eduvaud.ch> 7f219af Update-Sch-Ampli-Simu
2023-02-22 11:27:40 +0100 Ali Zoubir <ali.zoubir@eduvaud.ch> faaf492 Update-SCH 2023-02-22 11:26:14 +0100 Ali Zoubir <ali.zoubir@eduvaud.ch> 01113cf Update-SCH-Simu
2023-02-22 10:44:01 +0100 Ali Zoubir <ali.zoubir@eduvaud.ch> a6b07e0 Updateschematic
2023-02-08 16:45:50 +0100 Ali Zoubir <ali.zoubir@eduvaud.ch> 57245b8 Update-SCH 2023-02-08
16:22:11 +0100 Ali Zoubir <ali.zoubir@eduvaud.ch> e14b282 Update-SCH 2023-02-08 15:54:13 +0100 Ali Zoubir <ali.zoubir@eduvaud.ch> 6cf71b9 Update-DOC 2023-02-08 14:31:30 +0100 Ali Zoubir <ali.zoubir@eduvaud.ch> 7c11d1c Update-doc 2023-02-08 14:07:39 +0100 Ali Zoubir <ali.zoubir@eduvaud.ch> 399d9a6 Update-SCH 2023-02-08 13:47:09 +0100 Ali Zoubir <ali.zoubir@eduvaud.ch> 104932e Update-SCH 2023-02-08 13:37:43 +0100 Ali Zoubir <ali.zoubir@eduvaud.ch> 9c55c03 Update-SCH 2023-02-08 13:30:48 +0100 Ali Zoubir <ali.zoubir@eduvaud.ch> 5a286cb Update-SCH 2023-02-03 15:41:39 +0100 Ali Zoubir <ali.zoubir@eduvaud.ch> 76e06f9 create-TODO 2023-02-02 10:26:07 +0100 Ali Zoubir <ali.zoubir@eduvaud.ch> e1ce3ab Update-report 2023-02-01 16:38:30 +0100 Ali Zoubir <ali.zoubir@eduvaud.ch> ff8a185 Update-report 2023-02-01 15:08:02 +0100 Ali Zoubir <ali.zoubir@eduvaud.ch> d0fa1d2 Update-all 2023-02-01 14:21:16 +0100 Ali Zoubir <ali.zoubir@eduvaud.ch> f179687 BOM-Prix 2023-02-01 13:55:44 +0100 Ali Zoubir <ali.zoubir@eduvaud.ch> 9bdb92e Update-prsentation
2023-02-01 13:37:54 +0100 Ali Zoubir <ali.zoubir@eduvaud.ch> 8ea993c Bom-with-prices 2023-02-01 11:39:23 +0100 Ali Zoubir <ali.zoubir@eduvaud.ch> a372d1d Struct-git-etaltium
2023-02-01 11:32:15 +0100 Ali Zoubir <ali.zoubir@eduvaud.ch> 4a96ad3 Footprints-BOM 2023-02-01 10:47:24 +0100 Ali Zoubir <ali.zoubir@eduvaud.ch> eb9bbc0 Added-prsentation
2023-01-26 22:05:56 +0100 Ali-Z0 <ali.zoubir@eduvaud.ch> 6952c8e Rendu-Rapport-Schema
2023-01-26 21:53:19 +0100 Ali-Z0 <ali.zoubir@eduvaud.ch> 5977fc5 Update-report 2023-01-26 21:02:31 +0100 Ali-Z0 <ali.zoubir@eduvaud.ch> 0ae5599 report 2023-01-26 20:55:31 +0100 Ali-Z0 <ali.zoubir@eduvaud.ch> 04e2b98 Update-Report 2023-01-26 20:26:49 +0100 Ali-Z0 <ali.zoubir@eduvaud.ch> 8f3a6cf Update-report-Sch-PDF
2023-01-26 20:11:18 +0100 Ali-Z0 <ali.zoubir@eduvaud.ch> 3ed2bea Update-report 2023-01-26 16:52:17 +0100 Ali Zoubir <ali.zoubir@eduvaud.ch> 06daf42 Update-SCH 2023-01-26 16:19:30 +0100 Ali Zoubir <ali.zoubir@eduvaud.ch> bddbe3c Update-SCH 2023-01-26 13:27:26 +0100 Ali Zoubir <ali.zoubir@eduvaud.ch> f8bf31b Update-report 2023-01-26 11:14:39 +0100 Ali Zoubir <ali.zoubir@eduvaud.ch> 1770058 Update-SCH 2023-01-25 22:26:03 +0100 Ali-Z0 <ali.zoubir@eduvaud.ch> 1c0fe3f Modif-SCH 2023-01-25 19:22:19 +0100 Ali-Z0 <ali.zoubir@eduvaud.ch> 5c259b2 Update-SCH 2023-01-25 16:45:36 +0100 Ali Zoubir <ali.zoubir@eduvaud.ch> 018dd79 Update-SCH-Report
2023-01-25 15:14:06 +0100 Ali Zoubir <ali.zoubir@eduvaud.ch> 3ac6def Update-SCH 2023-01-25 15:08:34 +0100 Ali Zoubir <ali.zoubir@eduvaud.ch> f948c25 Update-SCH 2023-01-25 14:04:10 +0100 Ali Zoubir <ali.zoubir@eduvaud.ch> 61fa1eb Update-SCH 2023-01-25 12:58:07 +0100 Ali Zoubir <ali.zoubir@eduvaud.ch> 5127237 SCH-esthetique 2023-01-25 12:39:08 +0100 Ali Zoubir <ali.zoubir@eduvaud.ch> 3cf05bd Update-SCH-Estethique

2023-01-25 12:18:40 +0100 Ali Zoubir <ali.zoubir@eduvaud.ch> d04f0be Update-SCH 2023-01-25 11:46:54 +0100 Ali Zoubir <ali.zoubir@eduvaud.ch> 6d2e64b Update-reportillustrations
2023-01-25 11:07:04 +0100 Ali Zoubir <ali.zoubir@eduvaud.ch> 0594d54 Update-SCHreport
2023-01-25 10:10:42 +0100 Ali Zoubir <ali.zoubir@eduvaud.ch> a69b95b Update-SCH 2023-01-25 09:36:31 +0100 Ali Zoubir <ali.zoubir@eduvaud.ch> d13cbe5 Update-SCH-Report
2023-01-24 20:27:58 +0100 Ali-Z0 <ali.zoubir@eduvaud.ch> 2e7a162 Update-SCH 2023-01-24 20:22:27 +0100 Ali-Z0 <ali.zoubir@eduvaud.ch> 3204f14 Update-SCH-Diagramme
2023-01-24 19:59:49 +0100 Ali-Z0 <ali.zoubir@eduvaud.ch> 9d1a1bc Update-report 2023-01-24 13:53:10 +0100 Ali Zoubir <ali.zoubir@eduvaud.ch> ad80838 Update-MCU 2023-01-24 11:19:01 +0100 Ali Zoubir <ali.zoubir@eduvaud.ch> 9276895 Update-SCH 2023-01-23 16:47:44 +0100 Ali Zoubir <ali.zoubir@eduvaud.ch> fc66740 Update-Report 2023-01-23 08:14:25 +0100 Ali Zoubir <ali.zoubir@eduvaud.ch> 7027cbb RMV-history 2023-01-22 17:28:50 +0100 Ali-Z0 <ali.zoubir@eduvaud.ch> 4667f15 Update-SCH 2023-01-22 16:28:58 +0100 Ali-Z0 <ali.zoubir@eduvaud.ch> 72a4cda Update-SCH 2023-01-22 16:13:42 +0100 Ali-Z0 <ali.zoubir@eduvaud.ch> a104945 gitignore 2023-01-22 16:10:13 +0100 Ali-Z0 <ali.zoubir@eduvaud.ch> 44a282c Update-gitignore 2023-01-22 15:52:55 +0100 Ali-Z0 <ali.zoubir@eduvaud.ch> b144bd9 Update-SCHgitignore
2023-01-22 15:35:18 +0100 Ali-Z0 <ali.zoubir@eduvaud.ch> 4208450 Update-SCH 2023-01-19 12:22:27 +0100 Ali Zoubir <ali.zoubir@eduvaud.ch> 56ded79 Update-SCH 2023-01-19 09:38:15 +0100 Ali Zoubir <ali.zoubir@eduvaud.ch> 0c9f6b0 Update-SCH 2023-01-18 19:41:25 +0100 Ali Zoubir <ali.zoubir@eduvaud.ch> bd6c8d3 Update-SCH 2023-01-18 18:49:13 +0100 Ali Zoubir <ali.zoubir@eduvaud.ch> b48b2e9 Update-SCH 2023-01-18 16:29:32 +0100 Ali Zoubir <ali.zoubir@eduvaud.ch> 7a41100 Update-SCH 2023-01-18 15:53:03 +0100 Ali Zoubir <ali.zoubir@eduvaud.ch> b55c1db Update-SCH 2023-01-18 13:31:17 +0100 Ali Zoubir <ali.zoubir@eduvaud.ch> 90773e7 Projet-template-ES
2023-01-18 11:27:03 +0100 Ali Zoubir <ali.zoubir@eduvaud.ch> c38cd29 SCH-Interface 2023-01-18 11:10:03 +0100 Ali Zoubir <ali.zoubir@eduvaud.ch> 0680618 Schematic-bigupdate
2023-01-18 08:43:36 +0100 Ali Zoubir <ali.zoubir@eduvaud.ch> e28c5eb MAJ-schematic 2023-01-14 12:01:35 +0100 Ali Zoubir <ali.zoubir@eduvaud.ch> 1892159 Update 2022-12-21 17:56:30 +0100 Ali Zoubir <ali.zoubir@eduvaud.ch> d3e6093 Update-reportschematic
2022-12-14 16:48:31 +0100 Ali-Z0 <ali.zoubir@eduvaud.ch> 10d365b Moved-uselessfiles
2022-12-14 16:48:18 +0100 Ali-Z0 <ali.zoubir@eduvaud.ch> 08dd442 Gest-Fichiers 2022-12-14 16:39:54 +0100 Ali-Z0 <ali.zoubir@eduvaud.ch> d215c44 UpdateSchemagitignore-history
2022-12-14 16:02:30 +0100 Ali-Z0 <ali.zoubir@eduvaud.ch> 6d4cbc6 Schemapresentation
2022-12-14 15:43:48 +0100 Ali-Z0 <ali.zoubir@eduvaud.ch> b924fb4 Update 2022-12-14 10:24:41 +0100 Ali-Z0 <ali.zoubir@eduvaud.ch> 1b1bcad Initial-files

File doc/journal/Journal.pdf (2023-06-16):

DATE | Activité | Problèmatique
16.11.2023 | Choix du sujet, début de réflexion | -
13.11.2023 | Fonctionnement global du système et schema de principe | -
30.11.2023 | Meeting avec Gaston Baudat, dimensionnements et choix de composant | -
07.12.2023 | Suite du dimensionnement et du choix des composants. Rédaction pré-étude | -
14.12.2023 | Présentation pré-étude et début du schéma | -
04.01.2023 | Absent | Perte de temps due a l'absence
11.01.2023 | Entrevue avec Mr. Muller pour de l'assistance mécanique, sur la conception d'un capteur de pression par mesure de la déformation mécanique. | -
18.01.2023 | Progression sur la schématique du projet, dimensionnement partie alimentation. | -
25.01.2023 | Avancement du rapport. Entrevue design mécanique avec Mr. Moreno et Mr. Muller. | -
01.02.2023 | Footprint, Bom, schéma bloc | -
08.02.2023 | Ajout entrée analogique pour capteur de pression, màj du schèma et présentation de l'étude. | -
15.02.2023 | Montage
22.02.2023 | Montage
01.03.2023 | Montage et tests
08.03.2023 | Programmation firmware | Tests et lectures
15.03.2023 | Programmation firmware | Centrale inertiell BNO055
22.03.2023 | Programmation firmware | Centrale inertiell BNO055
29.03.2023 | Programmation firmware | Centrale inertiell BNO055
05.04.2023 | Programmation firmware | Carte SD
12.04.2023 | Vacances
19.04.2023 | Vacances
26.04.2023 | Design mécanique et tests
03.05.2023 | Programmation firmware | Carte SD
10.05.2023 | Implémentation capteur de pression
17.05.2023 | Programmation firmware | ADC - Capteur de pression
24.05.2023 | Programmation firmware | ADC - Capteur de pression
31.05.2023 | Programmation firmware | Gestion des temps processeur
07.06.2023 | Finalisation de la programmation firmware | -
14.06.2023 | Finalisation de la programmation firmware + rapport | -
16.06.2023 | Rendu final du dossier

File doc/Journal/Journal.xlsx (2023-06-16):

DATE | Activité | Problèmatique
2023-11-16 | Choix du sujet, début de réflexion | -
2023-11-13 | Fonctionnement global du système et schema de principe | -
2023-11-30 | Meeting avec Gaston Baudat, dimensionnements et choix de composant | -
2023-12-07 | Suite du dimensionnement et du choix des composants. Rédaction pré-étude | -
2023-12-14 | Présentation pré-étude et début du schéma | -
2023-01-04 | Absent | Perte de temps due a l'absence
2023-01-11 | Entrevue avec Mr. Muller pour de l'assistance mécanique, sur la conception d'un capteur de pression par mesure de la déformation mécanique. | -
2023-01-18 | Progression sur la schématique du projet, dimensionnement partie alimentation. | -
2023-01-25 | Avancement du rapport. Entrevue design mécanique avec Mr. Moreno et Mr. Muller. | -
2023-02-01 | Footprint, Bom, schéma bloc | -
2023-02-08 | Ajout entrée analogique pour capteur de pression, màj du schèma et présentation de l'étude. | -
2023-02-15 | Montage
2023-02-22 | Montage
2023-03-01 | Montage et tests
2023-03-08 | Programmation firmware | Tests et lectures
2023-03-15 | Programmation firmware | Centrale inertiell BNO055
2023-03-22 | Programmation firmware | Centrale inertiell BNO055
2023-03-29 | Programmation firmware | Centrale inertiell BNO055
2023-04-05 | Programmation firmware | Carte SD
2023-04-12 | Vacances
2023-04-19 | Vacances
2023-04-26 | Design mécanique et tests
2023-05-03 | Programmation firmware | Carte SD
2023-05-10 | Implémentation capteur de pression
2023-05-17 | Programmation firmware | ADC - Capteur de pression
2023-05-24 | Programmation firmware | ADC - Capteur de pression
2023-05-31 | Programmation firmware | Gestion des temps processeur
2023-06-07 | Finalisation de la programmation firmware | -
2023-06-14 | Finalisation de la programmation firmware + rapport | -
2023-06-16 | Rendu final du dossier

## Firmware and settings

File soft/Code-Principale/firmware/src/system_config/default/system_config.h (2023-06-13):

/*******************************************************************************
  MPLAB Harmony System Configuration Header

  File Name:
    system_config.h

  Summary:
    Build-time configuration header for the system defined by this MPLAB Harmony
    project.

  Description:
    An MPLAB Project may have multiple configurations.  This file defines the
    build-time options for a single configuration.

  Remarks:
    This configuration header must not define any prototypes or data
    definitions (or include any files that do).  It only provides macro
    definitions for build-time configuration options that are not instantiated
    until used by another MPLAB Harmony module or application.

    Created with MPLAB Harmony Version 2.06
*******************************************************************************/

// DOM-IGNORE-BEGIN
/*******************************************************************************
Copyright (c) 2013-2015 released Microchip Technology Inc.  All rights reserved.

Microchip licenses to you the right to use, modify, copy and distribute
Software only when embedded on a Microchip microcontroller or digital signal
controller that is integrated into your product or third party product
(pursuant to the sublicense terms in the accompanying license agreement).

You should refer to the license agreement accompanying this Software for
additional information regarding your rights and obligations.

SOFTWARE AND DOCUMENTATION ARE PROVIDED AS IS WITHOUT WARRANTY OF ANY KIND,
EITHER EXPRESS OR IMPLIED, INCLUDING WITHOUT LIMITATION, ANY WARRANTY OF
MERCHANTABILITY, TITLE, NON-INFRINGEMENT AND FITNESS FOR A PARTICULAR PURPOSE.
IN NO EVENT SHALL MICROCHIP OR ITS LICENSORS BE LIABLE OR OBLIGATED UNDER
CONTRACT, NEGLIGENCE, STRICT LIABILITY, CONTRIBUTION, BREACH OF WARRANTY, OR
OTHER LEGAL EQUITABLE THEORY ANY DIRECT OR INDIRECT DAMAGES OR EXPENSES
INCLUDING BUT NOT LIMITED TO ANY INCIDENTAL, SPECIAL, INDIRECT, PUNITIVE OR
CONSEQUENTIAL DAMAGES, LOST PROFITS OR LOST DATA, COST OF PROCUREMENT OF
SUBSTITUTE GOODS, TECHNOLOGY, SERVICES, OR ANY CLAIMS BY THIRD PARTIES
(INCLUDING BUT NOT LIMITED TO ANY DEFENSE THEREOF), OR OTHER SIMILAR COSTS.
*******************************************************************************/
// DOM-IGNORE-END

#ifndef _SYSTEM_CONFIG_H
#define _SYSTEM_CONFIG_H

// *****************************************************************************
// *****************************************************************************
// Section: Included Files
// *****************************************************************************
// *****************************************************************************
/*  This section Includes other configuration headers necessary to completely
    define this configuration.
*/


// DOM-IGNORE-BEGIN
#ifdef __cplusplus  // Provide C++ Compatibility

extern "C" {

#endif
// DOM-IGNORE-END

// *****************************************************************************
// *****************************************************************************
// Section: System Service Configuration
// *****************************************************************************
// *****************************************************************************
// *****************************************************************************
/* Common System Service Configuration Options
*/
#define SYS_VERSION_STR           "2.06"
#define SYS_VERSION               20600

// *****************************************************************************
/* Clock System Service Configuration Options
*/
#define SYS_CLK_FREQ                        48000000ul
#define SYS_CLK_BUS_PERIPHERAL_1            48000000ul
#define SYS_CLK_UPLL_BEFORE_DIV2_FREQ       192000000ul
#define SYS_CLK_CONFIG_PRIMARY_XTAL         8000000ul
#define SYS_CLK_CONFIG_SECONDARY_XTAL       32768ul
   
/*** Ports System Service Configuration ***/
#define SYS_PORT_A_ANSEL        0xF86E
#define SYS_PORT_A_TRIS         0xFB7E
#define SYS_PORT_A_LAT          0x0000
#define SYS_PORT_A_ODC          0x0000
#define SYS_PORT_A_CNPU         0x0000
#define SYS_PORT_A_CNPD         0x0000
#define SYS_PORT_A_CNEN         0x0000

#define SYS_PORT_B_ANSEL        0x0003
#define SYS_PORT_B_TRIS         0xEF1F
#define SYS_PORT_B_LAT          0x0080
#define SYS_PORT_B_ODC          0x0080
#define SYS_PORT_B_CNPU         0x0000
#define SYS_PORT_B_CNPD         0x0000
#define SYS_PORT_B_CNEN         0x0000

#define SYS_PORT_C_ANSEL        0xFC00
#define SYS_PORT_C_TRIS         0xFC5D
#define SYS_PORT_C_LAT          0x0000
#define SYS_PORT_C_ODC          0x0000
#define SYS_PORT_C_CNPU         0x0000
#define SYS_PORT_C_CNPD         0x0000
#define SYS_PORT_C_CNEN         0x0000


/*** File System Service Configuration ***/

#define SYS_FS_MEDIA_NUMBER         	1

#define SYS_FS_VOLUME_NUMBER		1
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

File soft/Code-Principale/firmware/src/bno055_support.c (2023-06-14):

/**
* Copyright (c) 2020 Bosch Sensortec GmbH. All rights reserved.
*
* BSD-3-Clause
*
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
* 1. Redistributions of source code must retain the above copyright
*    notice, this list of conditions and the following disclaimer.
*
* 2. Redistributions in binary form must reproduce the above copyright
*    notice, this list of conditions and the following disclaimer in the
*    documentation and/or other materials provided with the distribution.
*
* 3. Neither the name of the copyright holder nor the names of its
*    contributors may be used to endorse or promote products derived from
*    this software without specific prior written permission.
*
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
* @file bno055_support.c
* @date 10/01/2020
* @version  2.0.6
*
*/

/*---------------------------------------------------------------------------*
*  Includes
*---------------------------------------------------------------------------*/
#include "app.h"
#include "bno055.h"
#include "bno055_support.h"
#include "Mc32_I2cUtilCCS.h"
#include "driver/tmr/drv_tmr_static.h"

// Global variable
TIMER_DATA timerData;

#ifdef  BNO055_API

s32 bno055_read_routine(s_bno055_data *data)
{
      /* Variable used to return value of
     * communication routine*/
    s32 comres = BNO055_ERROR;

    /* variable used to set the power mode of the sensor*/
    //u8 power_mode = BNO055_INIT_VALUE;

    /*  For initializing the BNO sensor it is required to the operation mode
     * of the sensor as NORMAL
     * Normal mode can set from the register
     * Page - page0
     * register - 0x3E
     * bit positions - 0 and 1*/
    //power_mode = BNO055_POWER_MODE_NORMAL;

    /* set the power mode as NORMAL*/
    //comres += bno055_set_power_mode(power_mode);

    /*----------------------------------------------------------------*
     ************************* END INITIALIZATION *************************
     *-----------------------------------------------------------------*/

    /************************* START READ RAW FUSION DATA ********
     * For reading fusion data it is required to set the
     * operation modes of the sensor
     * operation mode can set from the register
     * page - page0
     * register - 0x3D
     * bit - 0 to 3
     * for sensor data read following operation mode have to set
     * FUSION MODE
     * 0x08 - BNO055_OPERATION_MODE_IMUPLUS
     * 0x09 - BNO055_OPERATION_MODE_COMPASS
     * 0x0A - BNO055_OPERATION_MODE_M4G
     * 0x0B - BNO055_OPERATION_MODE_NDOF_FMC_OFF
     * 0x0C - BNO055_OPERATION_MODE_NDOF
     * based on the user need configure the operation mode*/
    //comres += bno055_set_operation_mode(BNO055_OPERATION_MODE_NDOF);
    
    /*  Raw Quaternion W, X, Y and Z data can read from the register
     * page - page 0
     * register - 0x20 to 0x27 */
    comres += bno055_read_quaternion_wxyz(&data->quaternion);
    /************************* END READ RAW FUSION DATA  ************/
    /******************START READ CONVERTED SENSOR DATA****************/
    /*  API used to read mag data output as double  - uT(micro Tesla)
     * float functions also available in the BNO055 API */
    comres += bno055_convert_double_mag_xyz_uT(&data->mag);
    /*  API used to read gyro data output as double  - dps and rps
     * float functions also available in the BNO055 API */
    comres += bno055_convert_double_gyro_xyz_dps(&data->gyro);
    /*  API used to read Euler data output as double  - degree and radians
     * float functions also available in the BNO055 API */
    comres += bno055_convert_double_euler_hpr_deg(&data->euler);
    /*  API used to read Linear acceleration data output as m/s2
     * float functions also available in the BNO055 API */
    comres += bno055_convert_double_linear_accel_xyz_msq(&data->linear_accel);
    comres += bno055_convert_double_gravity_xyz_msq(&data->gravity);

    /*-----------------------------------------------------------------------*
     ************************* START DE-INITIALIZATION ***********************
     *-------------------------------------------------------------------------*/

    /*  For de - initializing the BNO sensor it is required
     * to the operation mode of the sensor as SUSPEND
     * Suspend mode can set from the register
     * Page - page0
     * register - 0x3E
     * bit positions - 0 and 1*/
    //power_mode = BNO055_POWER_MODE_SUSPEND;

    /* set the power mode as SUSPEND*/
    //comres += bno055_set_power_mode(power_mode);
    
    /* Flag measure ready */
    data->flagMeasReady = true;

    /*---------------------------------------------------------------------*
    ************************* END DE-INITIALIZATION **********************
    *---------------------------------------------------------------------*/
    return (comres+1);
}

/*--------------------------------------------------------------------------*
 *  The following API is used to map the I2C bus read, write, delay and
 *  device address with global structure bno055_t
 *-------------------------------------------------------------------------*/

/*-------------------------------------------------------------------------*
 *  By using bno055 the following structure parameter can be accessed
 *  Bus write function pointer: BNO055_WR_FUNC_PTR
 *  Bus read function pointer: BNO055_RD_FUNC_PTR
 *  Delay function pointer: delay_msec
 *  I2C address: dev_addr
 *--------------------------------------------------------------------------*/
s8 I2C_routine(void)
{
    bno055.bus_write = BNO055_I2C_bus_write;
    bno055.bus_read = BNO055_I2C_bus_read;
    bno055.delay_msec = BNO055_delay_msek;
    bno055.dev_addr = BNO055_I2C_ADDR1;
    return BNO055_INIT_VALUE;
}

/************** I2C buffer length******/

#define I2C_BUFFER_LEN 8
#define I2C0           5

/*-------------------------------------------------------------------*
 *
 *  This is a sample code for read and write the data by using I2C
 *  Use either I2C  based on your need
 *  The device address defined in the bno055.h file
 *
 *--------------------------------------------------------------------*/
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

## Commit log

2022-12-14 Schema + presentation
    [SchemaBloc.SchDoc]
2022-12-14 UpdateSchema + gitignore history
    [SchemaBloc.SchDoc]
2022-12-21 Update report + schematic
    [MCU.SchDoc, Sensors.SchDoc]
2023-01-18 MAJ schematic
    [2221_ProjetPCB.PrjPcb, Interface.SchDoc, MCU.SchDoc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]
2023-01-18 Schematic big update
    [2221_ProjetPCB.PrjPcb, Interface.SchDoc, Journal.xlsx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]
2023-01-18 SCH Interface
    [Interface.SchDoc]
2023-01-18 Projet-template ES
    [2221_LocalisationSousMarine.PrjPcb, ES_Class6C_2L.PcbDoc, Interface.SchDoc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]
2023-01-18 Update SCH
    [2221_LocalisationSousMarine.PrjPcb, Interface.SchDoc, MCU.SchDoc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]
2023-01-22 Update SCH + gitignore
    [2221_LocalisationSousMarine.PrjPcb, Interface.SchDoc, Peripherals.SchDoc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]
2023-01-23 Update Report
    [Power.SchDoc]
2023-01-24 Update MCU
    [MCU.SchDoc]
2023-01-25 Update SCH + Report
    [MCU.SchDoc, Peripherals.SchDoc, SchemaBloc.SchDoc]
2023-01-25 Update SCH Estethique
    [MCU.SchDoc, Peripherals.SchDoc, Power.SchDoc]
2023-01-25 SCH esthetique
    [MCU.SchDoc, Power.SchDoc]
2023-01-26 Update report Sch + PDF
    [Interface.SchDoc, MCU.SchDoc, Peripherals.SchDoc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]
2023-02-01 Bom with prices
    [Prix_Composants.xlsx]
2023-02-01 Update présentation
    [Prix_Composants.xlsx]
2023-02-01 Update all
    [Interface.SchDoc, Journal.xlsx, MCU.SchDoc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]
2023-02-22 Update schematic
    [Interface.SchDoc, MCU.SchDoc, Peripherals.SchDoc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]
2023-02-22 Update SCH + Simu
    [Peripherals.SchDoc]
2023-02-22 Update Sch-Ampli + Simu
    [Peripherals.SchDoc]
2023-02-22 Update PCB Lib
    [ES_Class6C_2L.PcbDoc, Interface.SchDoc, MCU.SchDoc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]
2023-02-22 Update footprints
    [2221_LocalisationSousMarine.PrjPcb, ES_Class6C_2L.PcbDoc, Peripherals.SchDoc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]
2023-03-01 SCH + PCB
    [Interface.SchDoc, MCU.SchDoc, Peripherals.SchDoc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]
2023-03-01 Update PCB
    [Interface.SchDoc, MCU.SchDoc]
2023-03-01 PCB Placement
2023-03-01 Update placement + Schema
    [Peripherals.SchDoc, Power.SchDoc]
2023-03-08 Udate placement
    [MCU.SchDoc]
2023-03-08 PCB dimensions
    [2221_LocalisationSousMarine.PrjPcb]
2023-03-08 Update placement
    [Peripherals.SchDoc]
2023-03-08 Update footprint
    [Peripherals.SchDoc]
2023-03-15 Update routage
    [MCU.SchDoc]
2023-03-15 Updated routing
    [2221_LocalisationSousMarine.PrjPcb]
2023-03-20 Update BOM + Projet
    [Interface.SchDoc, MCU.SchDoc]
2023-03-21 Lib + PCB
2023-03-21 Changed boost circuit
    [Interface.SchDoc, MCU.SchDoc, Peripherals.SchDoc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]
2023-03-22 Update Logo
    [2221_LocalisationSousMarine.PrjPcb, Interface.SchDoc]
2023-04-03 Update bom
2023-04-26 Huge update
    [MCU.SchDoc]
2023-05-11 IMU fonctionnelle
    PIN IntImu et SCL surement court-circuitées
2023-05-17 New code UART + Debut SPI SD
    [MCU.SchDoc]
2023-05-24 Update code, Carte SD Fonctionnelle
    [MCU.SchDoc]
2023-05-24 Amélioration des temps
2023-05-30 Ajout code avec ADC pour pression
    [Power.SchDoc]
2023-05-31 rapport + journal de travail
    [Journal.xlsx]
2023-06-14 Update rapport
    [Journal.xlsx]
2023-06-15 Rapport+mesures tension
2023-06-15 Mesure UART
2023-06-15 MAJ UART
2023-06-15 Aménagement du dossier
    [Journal.xlsx]
2023-06-19 Powerpoint final
    [Power.SchDoc]
2023-06-20 Code csv sd
    [MESURES.csv, Mesures.xlsx]
2023-06-20 Code plot fonctionnel v0
    [Mesures.xlsx]
2023-06-20 PPT + Code plot
    [DEMO.csv, MESURES.csv, Mesures.xlsx]
2023-06-20 csv demo
    [DEMO.csv]
2023-06-21 Powerpoint + 3d
    [SWITCH-M10-5A-R1-RP.SLDPRT, SWITCH-M10-5A-R1-RP.STEP, SWITCH-M10-5A-R1-RP.STL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]
2023-06-26 MAJ schéma et PCB Correctifs 1 et 2
    [MCU.SchDoc, SchemaBloc.SchDoc]
2023-06-26 Code pour 100ms aulieu de 90ms

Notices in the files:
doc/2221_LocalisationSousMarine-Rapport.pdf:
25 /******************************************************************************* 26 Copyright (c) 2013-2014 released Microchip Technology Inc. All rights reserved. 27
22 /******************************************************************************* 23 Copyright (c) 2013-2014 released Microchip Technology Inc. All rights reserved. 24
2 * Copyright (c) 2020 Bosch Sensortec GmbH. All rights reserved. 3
